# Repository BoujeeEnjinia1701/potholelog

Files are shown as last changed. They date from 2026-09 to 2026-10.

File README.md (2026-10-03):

# PotholeLog

     

**Area:** Smart Cities · **TRL:** 3 of 9 (proof of concept on paper) · **Value-engineering target:** about $75 USD · **Difficulty:** 2 of 5

A vehicle-mounted road roughness logger for buses, garbage trucks or bikes that records vibration with location to map potholes and rough roads as the fleet drives its routes.

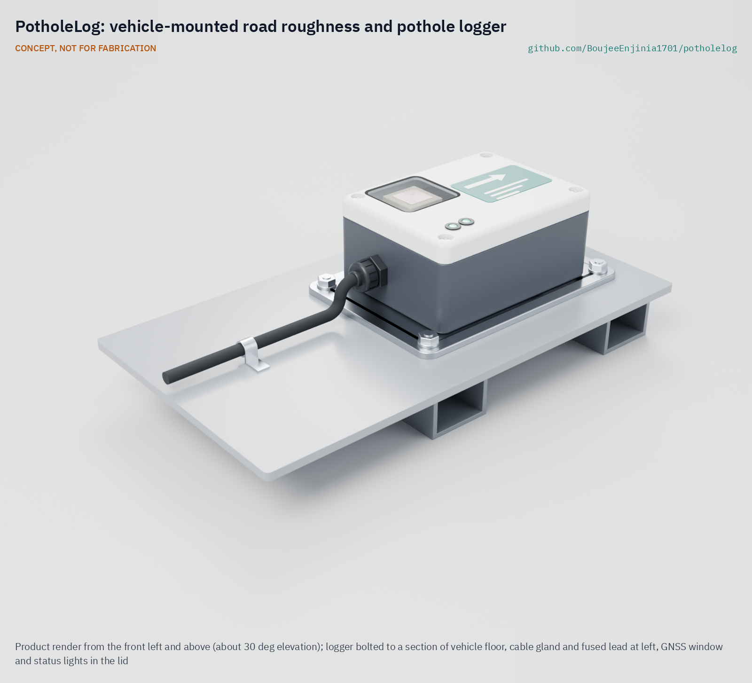
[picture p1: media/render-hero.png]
PotholeLog: vehicle-mounted road roughness and pothole logger, product render


[Exploded render](media/render-exploded.png) · [Detail render](media/render-detail.png) · [Interactive 3D model](media/viewer.html) · [Concept blueprint (PDF)](media/concept-blueprint.pdf) · [General arrangement (PDF)](cad/drawings/PHL-DWG-001.pdf) · [Calculations](docs/04-calcs/01-sizing.md) · [Prototype build plan](docs/05-build-plan.md) · [Design decisions](docs/06-design-decisions.md) · [Review note](docs/REVIEW.md)

## Concept rationale

Fleets already cover the road network every week, and a small sensor turns routine trips into a road survey. PotholeLog is a sealed box bolted to the floor of a bus or refuse truck above the rear axle. It logs vertical acceleration at 400 Hz with GNSS position, reports a roughness value for every 100 m of road and flags sharp impacts as possible potholes. Many passes by many vehicles are averaged, and each vehicle is calibrated on a few reference sections to give an estimate on the International Roughness Index (IRI) scale, following the method the World Bank set out for response-type roughness meters ([Technical Paper 46](https://documents1.worldbank.org/curated/en/851131468160775725/pdf/multi-page.pdf)).

It is open and garage-buildable because the agencies with the least survey money most need the data, and the parts are ordinary: an ESP32 board, an IMU breakout, a GNSS module, a vehicle DC-DC converter and a stock IP65 box, for about $77.50 in parts (indicative). Open firmware and an open data format let a city check how its road map was made and let others improve the detection method on the same raw data.

## Burning platform

Many road networks carry a large share of rough pavement. In the United States in 2023, about 25 % of the reported mileage of urban "other principal arterials" had an IRI above 170 in/mi (2.7 m/km), the level treated as poor (computed from [FHWA Highway Statistics, table HM-64](https://www.fhwa.dot.gov/policyinformation/statistics/2023/hm64.cfm)). In England, local authorities rated 17 % of their unclassified roads as needing maintenance to be considered in the year to March 2025 ([Department for Transport](https://www.gov.uk/government/statistics/road-conditions-in-england-to-march-2025)). Yet most local streets are surveyed rarely, so repairs follow complaints.

The stakes go beyond vehicle damage. Road crashes kill about 1.16 million people a year, 92 % of them in low- and middle-income countries, and more than half of those killed are pedestrians, cyclists and motorcyclists ([WHO](https://www.who.int/news-room/fact-sheets/detail/road-traffic-injuries)), the road users most exposed to potholes and broken surfaces. The same WHO fact sheet estimates that crashes cost most countries 3 % of gross domestic product.

## Where it could be used

### By industry

| Industry | Use |
| --- | --- |
| Municipal road maintenance | Weekly roughness and pothole map from the city's own fleet to plan patching and resurfacing |
| Public transit | Buses log the corridors they use most, and the agency can show where rough roads affect ride comfort and wear |
| Waste collection | Refuse trucks reach nearly every residential street on a weekly cycle, covering the roads surveys visit least |
| Road agencies and development programs | Low-cost condition data for network planning where survey vans are unaffordable |
| Fleet maintenance | Relate suspension and tyre wear to the roughness of each vehicle's routes |
| Universities and civic tech groups | Open raw data for research on detection methods and road equity |

### By country or region

| Country or region | Why it matters there |
| --- | --- |
| United States | About a quarter of urban principal arterial mileage rated above the poor IRI level in 2023 ([FHWA HM-64](https://www.fhwa.dot.gov/policyinformation/statistics/2023/hm64.cfm)); cities have large bus and refuse fleets to host loggers |
| England and the United Kingdom | 17 % of local unclassified roads needed maintenance to be considered in 2024/25 ([DfT](https://www.gov.uk/government/statistics/road-conditions-in-england-to-march-2025)); councils already publish condition data |
| Sub-Saharan Africa | Road traffic death rates are highest in the WHO African Region ([WHO](https://www.who.int/news-room/fact-sheets/detail/road-traffic-injuries)); minibus fleets cover dense networks where survey budgets are small |
| India | Road accidents attributed to potholes numbered 4,775 in 2019 and 3,564 in 2020, according to the road transport ministry's reply in the Lok Sabha ([PIB, 16 December 2021](https://pib.gov.in/PressReleasePage.aspx?PRID=1782178)); fleet data could locate defects before they cause crashes |
| Brazil | The 2025 CNT survey of 114,197 km of federal and main state highways rated the pavement fair, poor or very poor on 56.5 % of that length ([CNT, Pesquisa CNT de Rodovias 2025](https://repositorio.itl.org.br/jspui/bitstream/123456789/847/1/Pesquisa%20CNT%20de%20Rodovias%202025%20-%20S%C3%ADntese%20dos%20resultados%20-%20nacional,%20por%20regi%C3%A3o%20e%20por%20estados.pdf)); fleet loggers could extend condition data to city streets |
| Canada | About 13 % of public road length was in poor or very poor condition in 2020 ([Statistics Canada, Core Public Infrastructure Survey](https://www150.statcan.gc.ca/n1/daily-quotidien/220524/dq220524a-eng.htm)); municipal transit and refuse fleets could survey local roads weekly |

## What sparked the idea

The starting point was the International Road Roughness Experiment, held around Brasília, Brazil, in May and June 1982 by research teams from Brazil, the United Kingdom, France, the United States and Belgium. On 49 test sections, from asphalt to earth roads, it compared rod-and-level surveys and profilometers with seven response-type roughness systems, five of them roadmeters fitted to ordinary passenger cars, and the results became the basis of the International Roughness Index ([Sayers, Gillespie and Queiroz, World Bank Technical Paper 45, 1986](https://documents1.worldbank.org/curated/en/326081468740204115/pdf/multi-page.pdf)). The experiment showed that an everyday vehicle, calibrated on a few reference sections, can measure roughness on a common scale. PotholeLog applies that finding to the buses and refuse trucks that already drive every street, with an open, low-cost sensor in place of a mechanical roadmeter.

## Problem

Road surveys are expensive and infrequent, so repairs follow complaints rather than condition. Full problem statement: [docs/01-problem.md](docs/01-problem.md)

## Concept

A vehicle-mounted road roughness logger for buses, garbage trucks or bikes that records vibration with location to map potholes and rough roads as the fleet drives its routes. This build targets buses and refuse trucks on vehicle power, with summaries uploaded over depot Wi-Fi; a bicycle variant, which needs its own battery and mount, is a later step (decided by Amish, 2026-09-25).

The TRL 3 calculations ([PHL-CAL-001](docs/04-calcs/01-sizing.md)) give 0.54 W running, 112 kB of summaries a day, 133 to 160 days of raw data on a 32 GB card, 7 s of hold-up and an estimated $77.50 in parts, $2.50 over the $75 value-engineering target once the status lights, breather vent and nameplate adopted on 2026-10-02 are counted. They also found two limits, both settled by Amish's 2026-09-25 decisions ([PHL-DDR-002](docs/decisions/0002-recommendations-accepted.md)). A bus tyre bridges most of a 300 mm pothole, so small potholes are found reliably only at low speed; the defect-detection range is now 10 to 30 km/h, relying on repeat slow passes near stops and junctions. The converter is now rated 60 V, so it survives a load dump on a 24 V vehicle, with a thin 1.9 V margin over the TVS clamp. Detection accuracy and calibration remain unverified until field data exist.

Full design precis: [docs/02-concept.md](docs/02-concept.md) · Requirements: [docs/03-requirements.md](docs/03-requirements.md) · Decisions: [PHL-DDR-001](docs/decisions/0001-trl2-review-decisions.md), [PHL-DDR-002](docs/decisions/0002-recommendations-accepted.md), [PHL-DDR-003](docs/decisions/0003-design-for-construction.md) · Parametric model: [cad/src/model.py](cad/src/model.py)

## Key components

- 6-axis IMU (LSM6DSO class) on the enclosure floor, screwed through it into the mounting plate
- GNSS module with patch antenna and PPS output (u-blox M10 class)
- ESP32-S3 controller with Wi-Fi and microSD storage
- 60 V-rated vehicle DC-DC converter (9 to 36 V supplies) with fuse, TVS and reverse-polarity protection, plus a hold-up supercapacitor
- Stock IP65 enclosure, 120 x 90 x 55 mm, held by four hex standoffs to a 160 x 110 x 4 mm aluminum mounting plate, with the modules on an aluminum carrier plate inside

The working bill of materials is in [bom/bom.csv](bom/bom.csv).

## Building the prototype

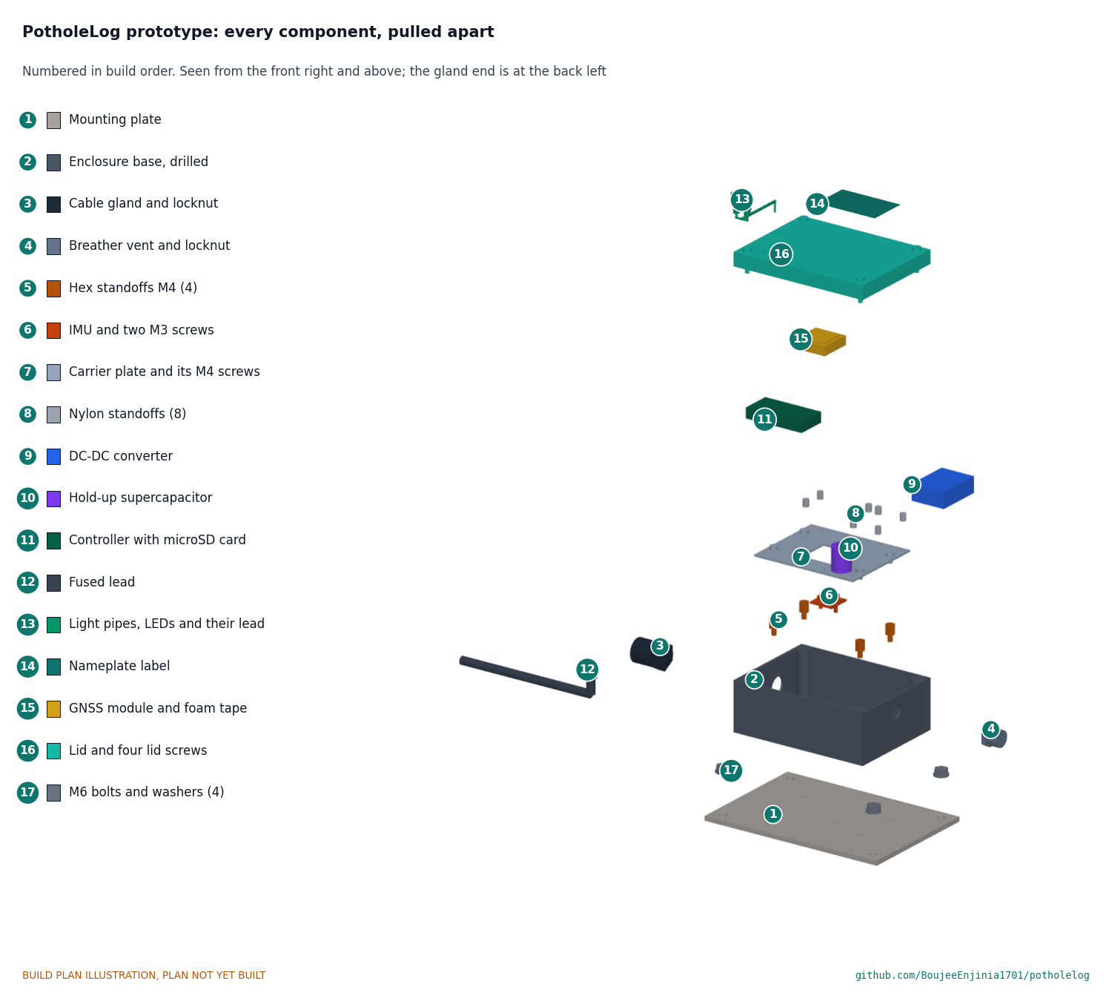
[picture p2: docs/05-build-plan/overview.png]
PotholeLog prototype: every component, pulled apart and numbered in build order


The [prototype build plan](docs/05-build-plan.md) (PHL-BLD-001) shows how to build the first logger from 14 components, each with a making sketch or a fitting picture, in nine assembly steps. Three parts are made in a small workshop from aluminium sheet and a bought plastic box; the rest are bought modules wired together at block level. Making the design buildable added a carrier plate for the modules and four hex standoffs that hold the box to the plate ([PHL-DDR-003](docs/decisions/0003-design-for-construction.md)). The plan stops at first checks on a bench board; fitting to a vehicle is outside it, and open choices are kept in the [design decisions register](docs/06-design-decisions.md).

## Safety

> Bolt the mounting plate through at existing fixing points so nothing can detach in a crash or hard stop, and never cut or weld structural members. Wire only to a fused, ignition-switched circuit with the battery isolated during installation, and route the lead away from moving parts and sharp edges. Do not fit a converter rated below 60 V to a 24 V vehicle. Never interact with the device while driving. Location data can reveal drivers' movements: publish only road-level results. This is a research prototype, not certified to automotive standards. See [docs/02-concept.md](docs/02-concept.md#safety).

## Repository layout

| Folder | Contents |
| --- | --- |
| `docs/` | Problem, concept, requirements, calculations and design decisions |
| `cad/src/` | build123d Python source, the source of truth for all geometry |
| `cad/step/`, `cad/stl/` | Exported models for FreeCAD, other CAD tools and printing |
| `cad/drawings/` | 2D sketches and dimensioned drawings |
| `bom/` | Bill of materials |
| `electronics/` | KiCad schematics and PCB layouts |
| `firmware/` | Microcontroller code |
| `media/` | Renders, perspectives and photos |
| `build-log/` | Dated prototyping notes |

## Documentation

Controlled documents follow the portfolio [documentation standard](.kit/STANDARDS.md). Each carries a document ID (PHL-PRC-001 for the precis), a version and a revision history. Branded PDFs are built with `python .kit/render.py` and attached to GitHub Releases when a document is tagged, for example `PHL-PRC-001/v1.0`.

## Credits

Designed by Amish Chadha. See [CONTRIBUTORS.md](CONTRIBUTORS.md) for roles. To cite this design, use [CITATION.cff](CITATION.cff) (GitHub shows it as "Cite this repository").

AI assistance (Claude) was used to accelerate concept renders, prototype documentation and first-pass sizing calculations. Design direction and all decisions are Amish Chadha's, recorded in this repository's decision records (`docs/decisions/`).

## Licenses

- **Hardware** (CAD, drawings, BOM, electronics): [CERN-OHL-S v2](LICENSE)
- **Software** (firmware, scripts, notebooks): [MIT](LICENSE-SOFTWARE)

A project of the [Design Molecule](https://designmolecule.com) lab.

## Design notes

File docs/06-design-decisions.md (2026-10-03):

---
doc_id: PHL-DEC-001
title: PotholeLog design decisions register
project: PotholeLog
doc_type: Design decisions register
version: "0.5"
status: Draft
date: '2026-10-03'
author: Amish Chadha
license: CERN-OHL-S-2.0
revisions:
  - version: "0.1"
    date: '2026-10-01'
    author: Amish Chadha
    change: Register opened with the build plan; budget treated as a value-engineering target
  - version: "0.2"
    date: '2026-10-02'
    author: Amish Chadha
    change: 'Amish approved the recommendations for all nine open decisions on 2026-10-02 (PHL-DDR-003 A1 to A3 accepted); moved to decisions made; value engineering notes the effect of the light pipes and vent'
  - version: "0.3"
    date: '2026-10-02'
    author: Amish Chadha
    change: "Design for construction (PHL-DDR-003, Tables 1 and 2) accepted by Amish on 2026-10-02; the 2026-10-01 row no longer says open for review"
  - version: "0.4"
    date: '2026-10-02'
    author: Amish Chadha
    change: "Value engineering: the light pipes and LEDs, breather vent and nameplate label are now BOM lines 14 to 16; estimate USD 77.50, USD 2.50 over the target"
  - version: "0.5"
    date: '2026-10-03'
    author: Amish Chadha
    change: "Amish accepted the cost overrun against the value-engineering target on 2026-10-03; row added to decisions made; value engineering section updated"
---

# PotholeLog design decisions register

Every design decision still to be made, and every decision made, in one place. Each decision is argued in full in its decision record under `docs/decisions/` or in the review note; this register is the index Amish works from. The build plan (`docs/05-build-plan.md`) describes the design as it stands and does not list open decisions.

## Open decisions

None. All open decisions were decided on 2026-10-02.

## To confirm when parts are bought

| # | What to confirm | Why it matters | Source |
| --- | --- | --- | --- |
| 1 | The box: 120 x 90 x 55 mm outside, 2.5 mm walls, a flat floor and four moulded corner pillars about 10 mm across | The standoff pattern, carrier size and clearances are set by them | PHL-DDR-003, P1, P7 |
| 2 | The converter's size (about 30 x 40 mm) and its four mounting holes; its 60 V input rating on the datasheet | The carrier's module holes are marked from it; safety stop S3 | PHL-DDR-003, P2; PHL-DDR-002, N1 |
| 3 | The ESP32-S3 board is no larger than about 52 x 26 mm and its microSD slot can be reached with the lid off | Many ESP32-S3 boards are longer; a longer board needs the layout rechecked | PHL-DDR-003, P3 |
| 4 | The IMU breakout: about 20 x 20 mm, two mounting holes, a side-entry plug, and the noise figure the calculations assume | The floor and plate IMU holes and the 3.4 mm clearance under the carrier | PHL-DDR-003, P5; PHL-CAL-001 |
| 5 | The GNSS module: no larger than 28 x 28 mm, a timing-pulse output, and a plug-in lead long enough to set the lid aside | The lid layout and the wiring | PHL-DDR-003, P6 |
| 6 | The hex standoffs' male thread is 6 mm or shorter | A longer thread would stick out under the plate | PHL-DDR-003, P1 |
| 7 | The M6 bolt length for the vehicle's floor or crossmember | It depends on the structure at the chosen fixing points | PHL-PRC-001 |

## Value engineering

Value-engineering target: USD 75 (a hypothetical control target, not a limit). Estimated cost of the constructable design: USD 77.50 (USD 2.50 over the target). Main cost drivers and savings worth trying:

Amish accepted this overrun on 2026-10-03: the estimated cost of USD 77.50 against the USD 75 target (USD 2.50 over), accepting the USD 2.50 overrun on R15. Amish: "Cost over target - i accept all the cost variations and overruns". It stays reported against the target as an accepted overrun, and the savings below remain worth trying.

- The largest lines are the GNSS module (USD 15), the controller (USD 10), the 60 V converter with its protection (USD 9) and the enclosure (USD 8); the plate, IMU and memory card are USD 6 each.
- Making the design constructable added the carrier plate (USD 2.00) and the box fixing kit (USD 1.50) and moved USD 0.50 of hardware out of line 11: from USD 71.00 to USD 74.00.
- Adopted on 2026-10-02 and now in the BOM: the two status light pipes with their LEDs and lead (line 14, USD 1.00), the breather vent (line 15, USD 2.00) and the nameplate label (line 16, USD 0.50). Together they take the estimate from USD 74.00 to USD 77.50, USD 2.50 over the target.
- Savings worth trying: cut the plate and carrier from offcuts; a 16 GB card still holds about 66 to 80 days of raw data against the 30 days needed (about USD 2 less), which with offcut plates would close most of the gap; GNSS modules of the same class vary widely in price; buying the standoffs, screws and lead parts in packs lowers the per-unit hardware cost.

## Decisions made

| Date | Decision | Decided by | Record |
| --- | --- | --- | --- |
| 2026-09-25 | TRL 2 review items D1 to D7: bicycles a later variant; depot Wi-Fi first; floor mount above the rear axle; ESP32-S3; LSM6DSO and M10 classes; 100 m segments in CSV and GeoJSON; publish road-level results only | Amish: "i accept all your recommendations, go with them across all repos." | PHL-DDR-001, PHL-DDR-002 |
| 2026-09-25 | N1: a 60 V-rated converter, with `budget_usd` raised from $70 to $75 | Amish, same instruction | PHL-DDR-002 |
| 2026-09-25 | N2: R5 defect-detection range 10 to 30 km/h with repeat slow passes; 300 mm reference defect kept | Amish, same instruction | PHL-DDR-002 |
| 2026-10-01 | Design for construction: hex standoffs, carrier plate, module layout, gland locknut, IMU screwed into the plate, GNSS on foam tape, modelled lid pillars | Made under Amish's 2026-09-30 instruction to make the design physically buildable ("fix the design assumptions to match and be physically feasible as you draw the illustrations"); the changes themselves were accepted on 2026-10-02 (below) | PHL-DDR-003 |
| 2026-10-02 | First pilot partner (first candidate to approach): a Dallas-Fort Worth area city with its own bus or refuse fleet, with TxDOT pavement management roughness data on state roads in that city as the reference IRI sections | Amish: "i approve your recommendations for all 555 open decisions." | PHL-DDR-001, O1; PHL-DDR-002 |
| 2026-10-02 | Clear lid window over the GNSS antenna shown in the renders only (option a); the build keeps the opaque lid | Amish: "i approve your recommendations for all 555 open decisions." | REVIEW 2026-09-26, item 1 |
| 2026-10-02 | Two sealed status light pipes in the lid, for power and logging, adopted (option a); the two lid holes are sealed like the others | Amish: "i approve your recommendations for all 555 open decisions." | REVIEW 2026-09-26, item 2 |
| 2026-10-02 | Pressure-equalizing breather vent on the front end wall adopted (option a) | Amish: "i approve your recommendations for all 555 open decisions." | REVIEW 2026-09-26, item 3 |
| 2026-10-02 | Printed nameplate label with a forward arrow adopted (option a) | Amish: "i approve your recommendations for all 555 open decisions." | REVIEW 2026-09-26, item 4 |
| 2026-10-02 | Segment files to CityTwin: CityTwin fetches the daily segment files from the operator's server (option a, matching CityTwin's outbound pull, CTW-DDR-001 D11); a date per segment may be published but never pass times, and only once at least two vehicles or several days are pooled | Amish: "i approve your recommendations for all 555 open decisions." | PHL-DDR-002, cross-repo actions |
| 2026-10-02 | Floor holes sealed with a ring of neutral-cure silicone round each hole for the prototype (option a), spray-tested at TRL 4 before a pilot; the foam gasket is the fallback if the spray test leaks | Amish: "i approve your recommendations for all 555 open decisions." | PHL-DDR-003, A1 |
| 2026-10-02 | GNSS module held by acrylic foam tape (option a), with adhesion checked after the TRL 4 heat soak; the printed clip is the fallback if the tape lets go | Amish: "i approve your recommendations for all 555 open decisions." | PHL-DDR-003, A2 |
| 2026-10-02 | Keep the 160 mm plate and bolt the logger down as a unit with a ring spanner for the prototype (option a); review after a TRL 4 trial fitting | Amish: "i approve your recommendations for all 555 open decisions." | PHL-DDR-003, A3; PHL-CAL-001 [I4] |
| 2026-10-02 | Design for construction accepted: the changes in Tables 1 and 2 (P1 to P7 and their knock-on changes), as made | Amish: "APPROVED: Design-for-construction changes in 10 repos (CityTwin, CoolShade, PalletPilot, Heliolite, PotholeLog, EarthPress, ReadyKit, CellCheck, CargoMule and ThermaCart)" | [PHL-DDR-003](decisions/0003-design-for-construction.md), Tables 1 and 2 |
| 2026-10-03 | Cost overrun accepted: the estimated cost of USD 77.50 against the USD 75 target (USD 2.50 over), accepting the USD 2.50 overrun on R15 | Amish: "Cost over target - i accept all the cost variations and overruns" | [REVIEW.md](REVIEW.md), session 2026-10-03 |

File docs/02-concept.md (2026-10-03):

---
doc_id: PHL-PRC-001
title: PotholeLog design precis
project: PotholeLog
doc_type: Design precis
version: "0.7"
status: Draft
date: '2026-10-02'
author: Amish Chadha
license: CERN-OHL-S-2.0
revisions:
- version: "0.1"
  date: '2026-09-25'
  author: Amish Chadha
  change: Initial scaffold
- version: "0.2"
  date: '2026-09-25'
  author: Amish Chadha
  change: Populate to TRL 2 (architecture, first-order numbers, safety, media)
- version: "0.3"
  date: '2026-09-25'
  author: Amish Chadha
  change: TRL 3 update (numbers checked against PHL-CAL-001, design choices adopted per PHL-DDR-001, parametric model and drawing PHL-DWG-001, detection and transient findings)
- version: "0.4"
  date: '2026-09-25'
  author: Amish Chadha
  change: Recommendations accepted by Amish (DDR-002)
- version: "0.5"
  date: '2026-10-01'
  author: Amish Chadha
  change: "Constructable design (PHL-DDR-003): carrier plate, box fixing, component table and key numbers updated"
- version: "0.6"
  date: '2026-10-02'
  author: Amish Chadha
  change: 'Decisions of 2026-10-02 (PHL-DEC-001): lid light pipes, nameplate and breather vent adopted; clear window renders only; CityTwin ingest and pooled dates; first pilot partner'
- version: "0.7"
  date: '2026-10-02'
  author: Amish Chadha
  change: 'Approved follow-ups carried out: light pipes and LEDs, breather vent and nameplate label as BOM lines 14 to 16; mass 0.44 kg and cost USD 77.50 (R15 not met); segment file pooling rule written into the server export'
---

# PotholeLog design precis

## Summary

PotholeLog is a sealed box, 120 x 90 x 55 mm on a 4 mm plate (59 mm overall), bolted to the floor of a bus or refuse truck above the rear axle. It records how the vehicle shakes and where it is, turns each 100 m of road into a roughness value and flags sharp impacts as possible potholes, then uploads a small daily file over depot Wi-Fi. Averaged over many passes and calibrated per vehicle, the data gives a city a weekly map of road condition on every street its fleet drives. The TRL 3 calculations (PHL-CAL-001) show that off-the-shelf modules meet the sampling, storage, hold-up and power needs for an estimated $77.50 in parts, $2.50 over the $75 value-engineering target since the status lights, breather vent and nameplate adopted on 2026-10-02 were added, and that the roughness signal is well above sensor noise. They also found two limits, both now addressed by Amish's 2026-09-25 decisions (PHL-DDR-002). A bus tyre bridges most of a 300 mm pothole, so the floor-mounted logger finds the R1 reference pothole only at low speed (up to about 20 km/h on a fair road, 50 km/h on a good one); small potholes are therefore sought on slow passes, 10 to 30 km/h, near stops and junctions. The converter is now rated 60 V so that it survives a load dump on a 24 V vehicle. Detection accuracy and calibration to IRI remain unverified until field data exist. On 2026-10-01 the design was made constructable (PHL-DDR-003): the modules now sit on a carrier plate held by the four hex standoffs that fix the box to the mounting plate, and the build is described component by component in the prototype build plan ([PHL-BLD-001](05-build-plan.md)).

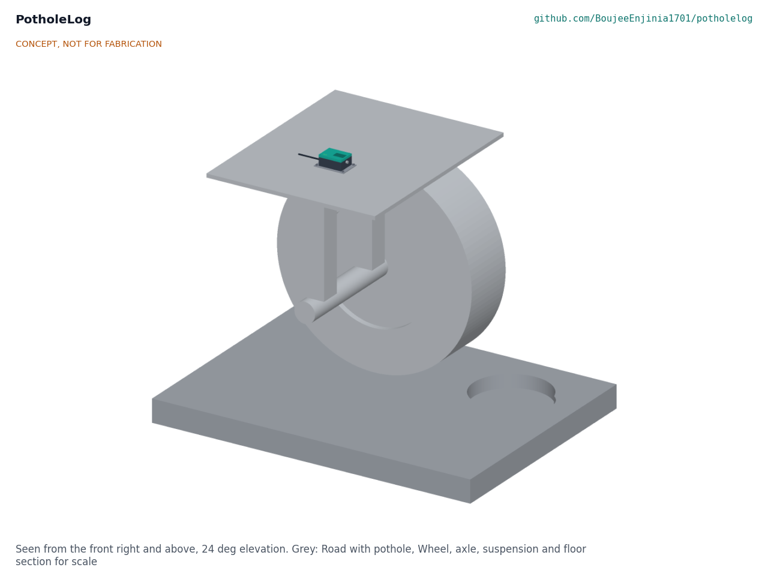
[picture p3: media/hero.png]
PotholeLog on a vehicle floor above the rear axle, with a wheel, suspension and a road with a pothole for scale


Figure 1. Concept massing model. The logger is the small dark box on the floor section; the grey scene is for scale.

## How it works

1. **Sense.** A 6-axis IMU rigidly fixed to the enclosure floor samples acceleration at 400 Hz. A GNSS module under the lid logs position and speed at 10 Hz.
2. **Log raw data.** Raw samples go to a microSD card as a rolling buffer, so any detection can be re-run later with a better algorithm.
3. **Summarize on board.** For every 100 m traveled, the controller computes a roughness value from the vertical acceleration (band-limited RMS from 0.5 to 20 Hz, tagged with its speed band for calibration), and records the segment's start and end, speed and the number of samples. Sharp vertical impacts above a threshold are stored as defect events, with most small potholes expected from slow passes at 10 to 30 km/h near stops and junctions (R5) with position, speed and peak size; the front and rear axle impacts of the same defect, about 0.4 to 0.7 s apart in town, are paired to confirm the event and place it at the rear axle.
4. **Upload.** When the vehicle is back within depot Wi-Fi with the ignition on, on arrival or at the next start, the controller joins the network and uploads the day's summaries (about 112 kB, about 8 s) to the fleet's server. The hold-up capacitor cannot power Wi-Fi long enough to upload after the ignition is switched off.
5. **Calibrate and aggregate.** On the server, each vehicle's raw roughness is converted to an IRI estimate using a calibration equation found on reference sections, in the way World Bank Technical Paper 46 describes for response-type systems ([Sayers et al., 1986](https://documents1.worldbank.org/curated/en/851131468160775725/pdf/multi-page.pdf)). Events from several passes and vehicles are clustered; a cluster seen on repeated passes becomes a reported defect, as in Pothole Patrol ([Eriksson et al., 2008](https://doi.org/10.1145/1378600.1378605)).
6. **Publish.** The city publishes a map of segment roughness and defect clusters as CSV and GeoJSON, for its own GIS and for CityTwin. Vehicle tracks and timestamps stay on the operator's server. CityTwin fetches the segment files from the operator's server; a date per segment is published only once at least two vehicles or several days are pooled, and pass times never are (decided 2026-10-02, PHL-DEC-001). The server export applies the pooling rule below.

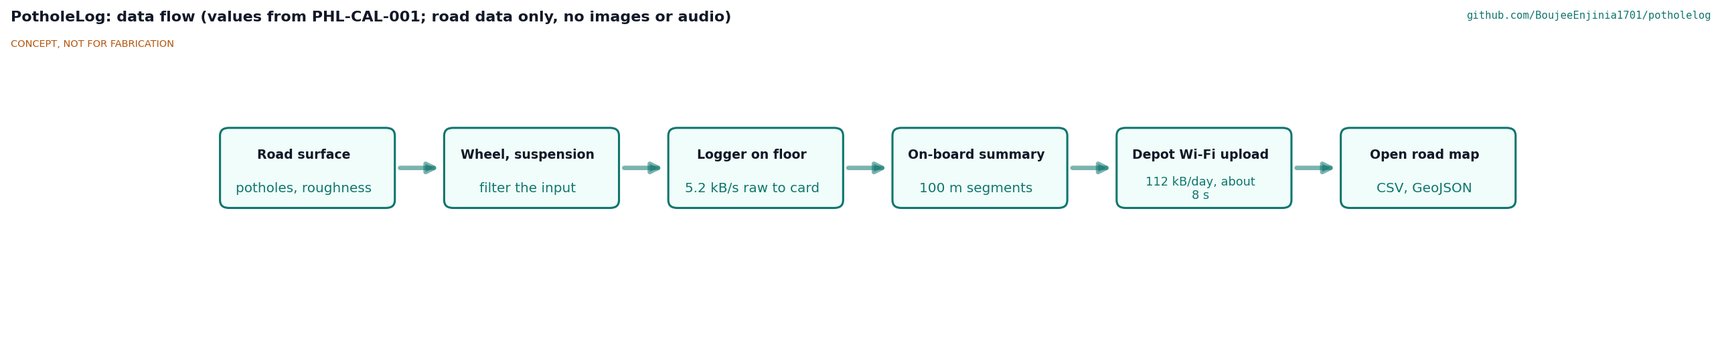
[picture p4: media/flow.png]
Data flow from road surface to open road map


Figure 2. Data flow. Values from PHL-CAL-001.

### Server export: segment files and the pooling rule

The operator's server writes one segment file a day in CSV and GeoJSON, following the CityTwin open data export, and CityTwin fetches it over HTTPS (decided 2026-10-02, PHL-DEC-001; CityTwin's outbound pull, CTW-DDR-001 D11). Each row is one 100 m segment: segment identifier and geometry, calibrated roughness (IRI estimate) with its uncertainty, number of passes, number of vehicles and number of days pooled, and defect clusters as point events. The pooling rule is applied in the export, not left to the reader:

1. A segment's row carries a date (day only, never a time) only when its value pools passes from at least two vehicles, or from at least three separate days. Otherwise the date field is left empty.
2. Pass times, vehicle identifiers, tracks and speeds are never exported; they stay on the operator's server.
3. Defect clusters carry the date of the newest day in the pool, under the same rule.

The three-day figure is this precis's reading of "several days" in the decision; it is to be matched with CityTwin's item 6 so both repos use the same rule and field names.

## Main components

Table 1. Main components. Numbers match the exploded view (Figure 3), `cad/src/model.py` and `bom/bom.csv`.

| # | Component | Proposed choice | Notes |
| --- | --- | --- | --- |
| 1 | Mounting plate | 160 x 110 x 4 mm aluminum, 4 x M6 on 140 x 90 mm; tapped for the box standoffs and the IMU screws | Bolts to existing crossmember, seat-rail or floor fixings; first mode about 168 Hz on corner bolts |
| 2 | Enclosure base | Stock IP65 ABS or polycarbonate box, 120 x 90 mm, with corner lid-screw pillars | Held to the plate by four M4 hex standoffs through its floor (PHL-DDR-003); a 12.2 mm hole in the front end wall for the breather vent (15) |
| 3 | Enclosure lid | Supplied with the box, with gasket; opaque; two 6.4 mm holes for the status light pipes (14) and the nameplate label (16) on top (decided 2026-10-02) | GNSS antenna under the lid; plastic lid keeps sky view through vehicle windows; the clear window shown in the renders is for the renders only |
| 4 | DC-DC converter and protection | 9 to 60 V in (60 V rated), 5 V 1 A out; TVS diode, reverse-polarity diode, input fuse | Covers normal 12 V and 24 V supplies and a 24 V suppressed load dump (58 V), clearing the TVS clamp by 1.9 V (PHL-DDR-002, N1) |
| 5 | Hold-up supercapacitor | 1 F, 5.5 V, rated to 70 °C or more | About 7 s at end of life to close files when power drops |
| 6 | Controller | ESP32-S3 board with Wi-Fi and microSD slot; module variant rated to 85 °C | Decided by Amish, 2026-09-25 (PHL-DDR-001, D4) |
| 7 | IMU | 6-axis, LSM6DSO class, ±16 g, 400 Hz or more | On the box floor, held by two M3 screws through the floor into the plate; gyroscope helps separate body roll and pitch from vertical motion |
| 8 | GNSS module | u-blox M10 class with patch antenna, 10 Hz, PPS output | Under the lid on a foam tape pad; PPS time-stamps the IMU samples |
| 9 | Cable gland and fused lead | M16 gland, 2 m lead, inline 2 A fuse | Wired to an ignition-switched fused circuit |
| 10 | microSD card | 32 GB high-endurance, -25 to 85 °C | 133 to 160 days of raw data |
| 11 | Fixings | 4 x M6 (8.8) with locking nuts and washers | Crash load is small; loosening needs a later test |
| 12 | Module carrier plate | 92 x 76 x 1.5 mm aluminum with a window over the IMU | Carries the converter, supercapacitor and controller (PHL-DDR-003) |
| 13 | Box fixing kit | 4 x M4 hex standoffs, screws, nylon standoffs, foam tape, sealant | Added for construction (PHL-DDR-003) |
| 14 | Status light pipes and LEDs | Two sealed panel-mount light pipes in the lid, a 5 mm LED in each, plug lead to the controller | Power and logging lights; adopted 2026-10-02 (PHL-DEC-001, decision 3) |
| 15 | Breather vent | M12 pressure-equalizing membrane vent, IP67, in the front end wall | Stops the box pumping moist air through the gasket as it heats and cools; adopted 2026-10-02 (decision 4) |
| 16 | Nameplate label | 54 x 34 mm laminated polyester label with a forward arrow | Shows which way the IMU's X axis must point; adopted 2026-10-02 |

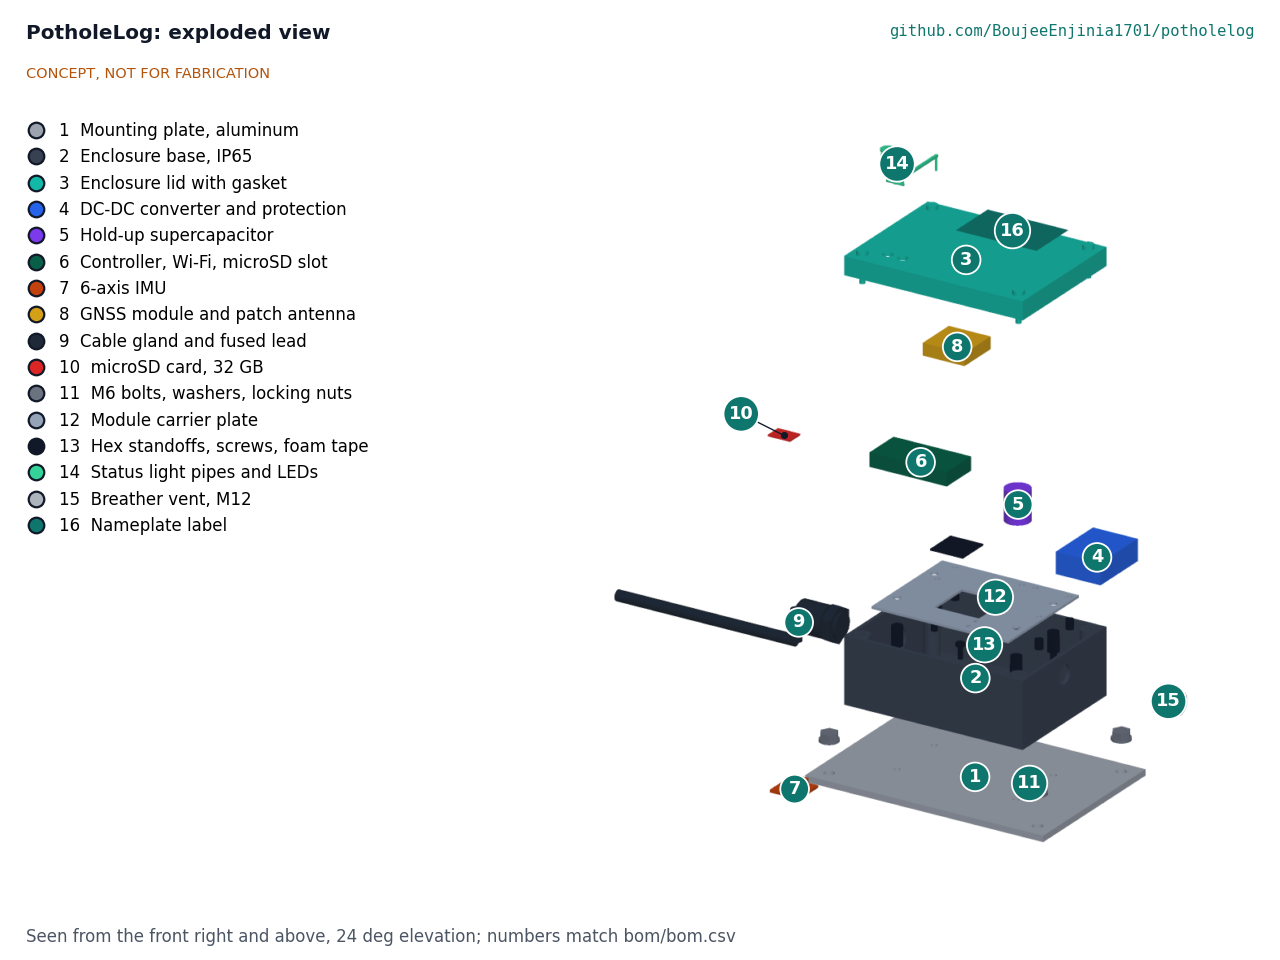
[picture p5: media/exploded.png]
Exploded view with BOM callouts


Figure 3. Exploded view with numbered callouts matching the BOM.

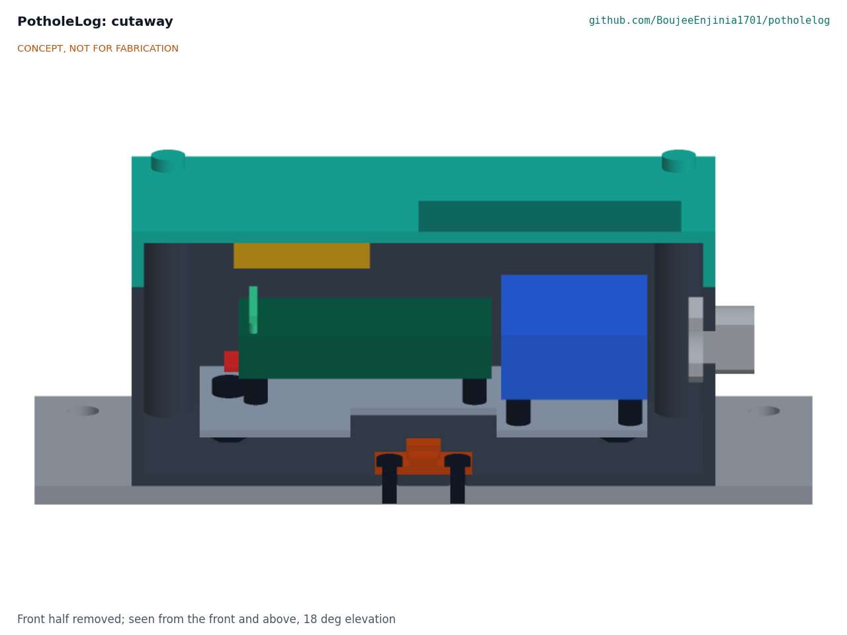
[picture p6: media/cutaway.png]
Section through the enclosure


Figure 4. Cutaway on the plane through the IMU. The IMU sits on the enclosure floor, the controller, supercapacitor and converter behind it, and the GNSS module under the lid.

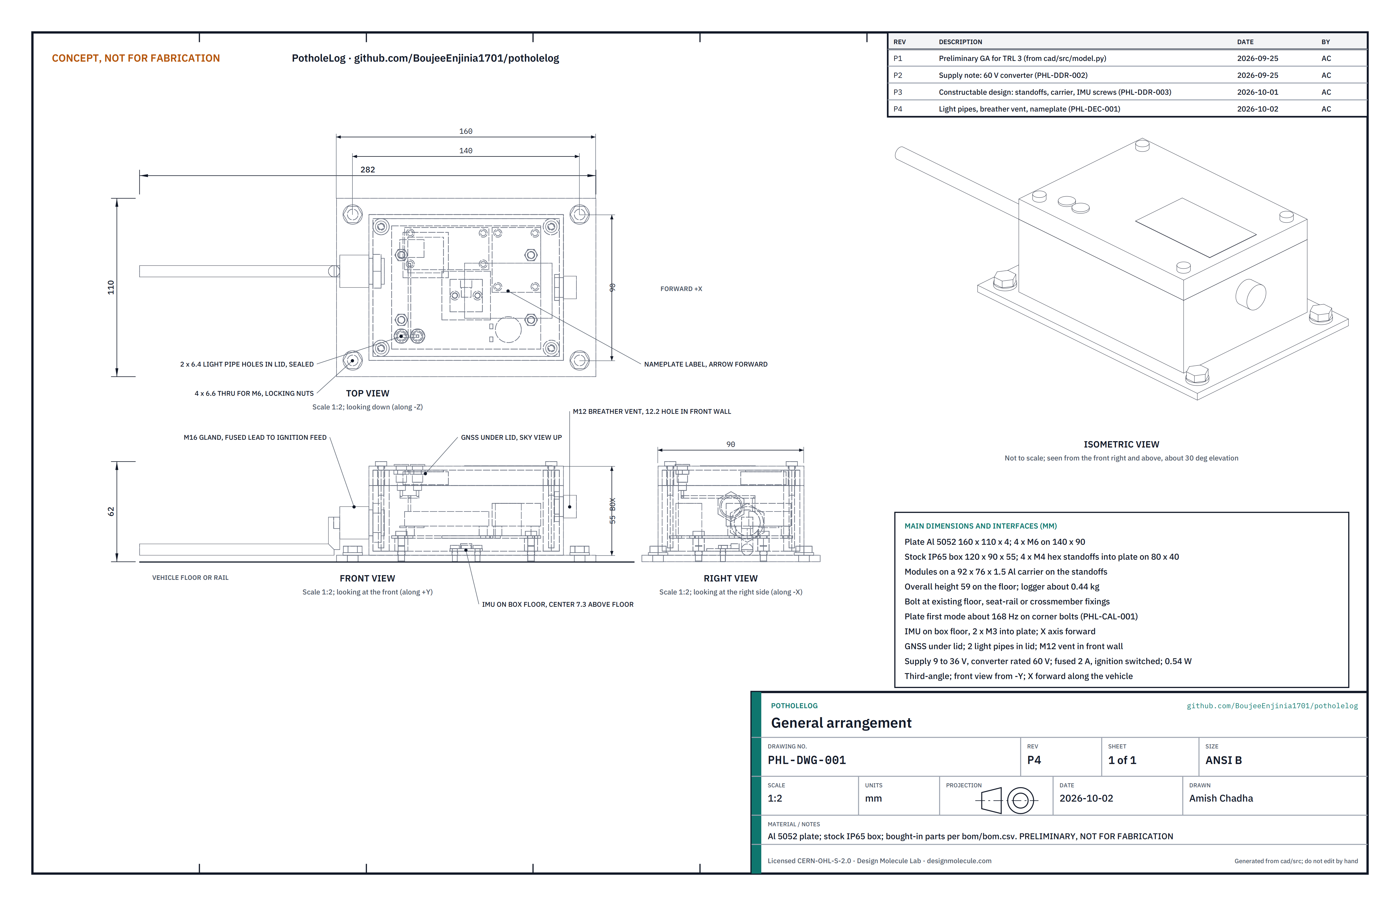
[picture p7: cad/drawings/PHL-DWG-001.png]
General arrangement drawing PHL-DWG-001


Figure 5. General arrangement PHL-DWG-001, Rev P3, generated from `cad/src/model.py` ([PDF](../cad/drawings/PHL-DWG-001.pdf)). Preliminary, not for fabrication.

## Key numbers

All values are from PHL-CAL-001 v0.3 (`docs/04-calcs/sizing.py`), which states the assumptions; they are calculations for review, not measurements.

Table 2. Key numbers.

| Quantity | Value | Basis | Requirement |
| --- | --- | --- | --- |
| Sample spacing on the road | 35 mm at 50 km/h, 56 mm at 80 km/h | 400 Hz | R6 |
| Samples across a 300 mm pothole | 9 at 50 km/h, 5 at 80 km/h | Length divided by spacing | R1 |
| Tyre drop into a 300 mm pothole | 22 mm, whatever its depth | 1.04 m tyre, rigid-circle envelope | R1 |
| Pothole detection margin | Above 1 up to about 20 km/h (IRI 4) and 50 km/h (IRI 2); in the 10 to 30 km/h band, 1.94 or more (IRI 2) and 0.97 at 30 km/h (IRI 4) | Quarter-car model against roughness crossing once per km | R1, R5 at risk |
| Roughness signal against noise | 12 times at 20 km/h on a smooth road | 0.5 to 20 Hz band | R5 |
| Synthetic calibration | r² 0.93 from one pass, 0.99 from five | 40 sections, IRI 1 to 8 m/km | R3 |
| Location, 95 % | 2.3 m suburban, 18.2 m dense urban (10 passes) | M10-class GNSS with PPS | R4 at risk |
| Raw data | 5.23 kB/s; 188 MB per 10 h day | 6 axes x 16 bit at 400 Hz, plus GNSS and time stamps | |
| Raw storage on a 32 GB card | 133 to 160 days | 10 to 12 h of driving a day | R7 met |
| Summaries per day | 112 kB, uploaded in about 8 s | 200 km, 48 B segments, 500 events at 32 B | R8 met |
| Running power | 0.54 W; 1.42 W for about 8 s while uploading | Loads 91 mA at 3.3 V, linear regulator, 85 % converter | R9 |
| Supply current | 45 mA at 12 V, 22 mA at 24 V | From running power | |
| Hold-up time | 10.0 s new, 7.0 s at end of life | 1 F from 4.7 V to 3.6 V | R10 met; 1 s needed |
| Inside temperature | About 72 °C at +70 °C ambient | 2.0 K self-heating | R11 at risk |
| Plate first mode | 168 Hz on corner bolts | 4 mm aluminum, 140 mm span | R12 met on paper |
| Installation | 30 min | Task estimate | R12 at the limit |
| Size | 120 x 90 x 55 mm box on a 160 x 110 x 4 mm plate, 59 mm overall | `cad/src/model.py` | |
| Mass | 0.44 kg; 0.58 kg with lead and fixings | Model volumes and module masses | |
| Converter input rating | 60 V against a 58 V suppressed load dump and a 58.1 V TVS clamp | ISO 16750-2 test B levels, to confirm | R9 at risk (TVS pulse energy) |
| Parts cost | $77.50 | `bom/bom.csv` | R15 not met: $2.50 over the $75 value-engineering target |

## Key design choices

The choices below were proposed at TRL 2 and decided by Amish on 2026-09-25 (go with recommendation; PHL-DDR-001 and PHL-DDR-002).

- **Sprung-mass mount on the floor, not on the axle.** The floor is clean, dry and easy to reach, and the GNSS can see the sky through the windows. The axle would give a stronger, less filtered signal but sees large shocks, water and stones. Calibration per vehicle corrects for the suspension. PHL-CAL-001 supports the choice: the axle would see about 9 g, 65 times the floor peak.
- **Depot Wi-Fi upload, not cellular.** It keeps parts cost near the value-engineering target and avoids data plans. Cellular (for example an LTE-M module) would give same-day data but adds about $20 to $30 per unit and a monthly fee; it stays an optional add-on, costed separately.
- **Raw data kept on the card.** Storage is cheap, and raw data lets the detection method improve without new hardware.
- **Summaries and events, not tracks, leave the vehicle's operator.** Only road-level results are published (R13).
- **Controller, IMU and GNSS.** ESP32-S3 (Wi-Fi, low cost, wide community), an LSM6DSO-class IMU and a u-blox M10-class GNSS. The alternatives considered were an RP2040 board with a separate Wi-Fi module and an nRF52 board with a phone or gateway for upload.
- **100 m segments and point events, in CSV and GeoJSON** following the CityTwin open data export.
- **60 V converter input.** A 60 V-rated converter replaces the 36 V part so that a 24 V suppressed load dump does not destroy it; about $2 more, with `budget_usd` raised from $70 to $75 (PHL-DDR-002, N1). A surge-stopper front end would be more robust and was not chosen.
- **Slow-pass defect detection.** The R5 defect-detection range is 10 to 30 km/h, with the 300 mm reference defect kept, because buses slow near stops and junctions and pass each spot many times (PHL-DDR-002, N2).
- **Bicycles later.** This build serves buses and refuse trucks; a bicycle variant with its own battery and mount is a later step, and the pitch is unchanged.
- **Built on existing lab work where it fits.** Outputs follow the CityTwin open data export so PotholeLog segments can appear on the CityTwin map; CityTwin is built on TwinKit. PotholeLog does not use FieldNode, because it runs from vehicle power rather than solar and uploads at the depot rather than over LoRaWAN.

## Safety

> **Safety:** PotholeLog is fitted to vehicles that carry passengers and operate in traffic.
>
> - **Secure mounting.** A loose box can become a projectile in a crash or hard stop. Bolt the plate through with M6 bolts and locking nuts at existing fixing points, never with adhesive or magnets alone. Do not cut, drill or weld chassis members or safety-critical structure; follow the fleet operator's and vehicle maker's rules for body fittings.
> - **Vehicle electrics.** Connect only to a fused, ignition-switched circuit through the inline fuse, with the battery isolated during installation. Route the lead away from moving parts, hot surfaces and sharp edges, and protect it where it passes through panels. A short on a 24 V vehicle supply can start a fire. The converter is now rated 60 V for a 24 V suppressed load dump (PHL-DDR-002), but the margin over the TVS clamp is only 1.9 V and the TVS pulse energy is untested; do not fit a converter rated below 60 V to a 24 V vehicle.
> - **Working on vehicles.** Install only with the vehicle parked, secured and switched off. Never work under a vehicle supported only by a jack.
> - **Driver distraction.** The logger has no controls or display and must not be handled while the vehicle is moving.
> - **Sharp edges.** Deburr the aluminum plate.
> - **Supercapacitor.** It stays charged for a short time after power is removed; do not short its terminals.
> - **Data.** Vehicle location data can reveal where drivers are and when. Keep tracks on the operator's server under the operator's data policy, inform drivers and unions before a pilot, and publish only road-level results.
>
> This is a research prototype. It is not certified to automotive electrical or EMC standards, and its outputs must not be used for contract acceptance or safety decisions without validation against a calibrated reference.

## Open questions

- Does the TVS survive a 24 V load dump pulse with the 60 V converter, or is a surge stopper needed (R9)? Needs a bench test (TRL 4, on hold).
- Are slow passes near stops and junctions frequent enough to meet R1 with the 10 to 30 km/h detection band (R5)? Needs field data.
- How far off is GNSS in the partner city's densest streets, and is map matching needed for R4?
- Which host fleet and city for a first pilot, and who provides reference IRI? Decided 2026-10-02 (PHL-DEC-001): the first candidate to approach is a Dallas-Fort Worth area city with its own bus or refuse fleet, with TxDOT pavement management roughness data on state roads in that city as the reference IRI sections.
- Should a bicycle variant be developed later, and with what battery and mount (R16)?

Concept media: [blueprint sheet](../media/concept-blueprint.pdf), [interactive 3D model](../media/viewer.html). Calculations: [PHL-CAL-001](04-calcs/01-sizing.md). Decisions: [PHL-DDR-001](decisions/0001-trl2-review-decisions.md).

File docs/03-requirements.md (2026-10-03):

---
doc_id: PHL-REQ-001
title: PotholeLog requirements
project: PotholeLog
doc_type: Requirements
version: "0.7"
status: Draft
date: '2026-10-02'
author: Amish Chadha
license: CERN-OHL-S-2.0
revisions:
- version: "0.1"
  date: '2026-09-25'
  author: Amish Chadha
  change: Initial scaffold
- version: "0.2"
  date: '2026-09-25'
  author: Amish Chadha
  change: First measurable requirements for TRL 2, with status against the concept
- version: "0.3"
  date: '2026-09-25'
  author: Amish Chadha
  change: TRL 3 status from PHL-CAL-001; R16 redefined per PHL-DDR-001 (D1); R8, R13 and R14 rest on adopted choices
- version: "0.4"
  date: '2026-09-25'
  author: Amish Chadha
  change: Recommendations accepted by Amish (DDR-002)
- version: "0.5"
  date: '2026-10-01'
  author: Amish Chadha
  change: "Constructable design (PHL-DDR-003): R12 plate mode and R15 cost updated; budget treated as a value-engineering target"
- version: "0.6"
  date: '2026-10-02'
  author: Amish Chadha
  change: 'Decisions of 2026-10-02 (PHL-DEC-001): R13 restated for published dates (pooled, never pass times); R14 CityTwin ingest path decided; R15 notes the cost of the adopted light pipes and vent. No status changed'
- version: "0.7"
  date: '2026-10-02'
  author: Amish Chadha
  change: 'Approved follow-ups carried out (PHL-CAL-001 v0.5): light pipes and LEDs, breather vent and nameplate label in the BOM; R15 moves from met on paper to not met (USD 77.50, USD 2.50 over the target)'
---

# PotholeLog requirements

These requirements are checked by calculation in PHL-CAL-001 v0.5. Targets are unchanged from v0.2 except R16, redefined for this build under PHL-DDR-001 (D1), and R5, whose defect-detection range is restated as 10 to 30 km/h under PHL-DDR-002 (N2). Both were decided by Amish on 2026-09-25 (go with recommendation). The status column gives the result on paper: "met on paper" means a calculation shows the target is met under the stated assumptions; "met by design" means the chosen parts and architecture meet it; "not verifiable at TRL 3" means only data from a vehicle can show it.

Table 1. Requirements.

| ID | Requirement | Target | Status at TRL 3 (PHL-CAL-001) | Verification (later) |
| --- | --- | --- | --- | --- |
| R1 | Detect potholes and severe defects in the wheel path | 80 % or more of defects at least 50 mm deep and 300 mm long found within 3 passes | At risk: a bus tyre drops only 22 mm into a 300 mm pothole; detectable up to about 20 km/h on IRI 4 roads and 50 km/h on IRI 2 roads | Detection model on logged data against a surveyed defect list |
| R2 | Keep false reports low | 10 % or fewer of reported defect clusters (2 or more passes) are not real defects | Not verifiable at TRL 3; Pothole Patrol reported over 90 % real after clustering | Field check of reported clusters |
| R3 | Report roughness per road segment | One roughness value per 100 m segment per pass, calibrated per vehicle to an IRI estimate; r² of 0.8 or better against reference IRI on calibration sections | Not verifiable at TRL 3; synthetic calibration gives r² 0.93 from one pass and 0.99 from five | Calibration runs following World Bank Technical Paper 46 |
| R4 | Locate defects | Defect cluster within 10 m of its true position (95 %) and on the correct street | At risk: 2.3 m suburban, 18.2 m in dense urban streets (10-pass cluster) | GNSS logs against surveyed points |
| R5 | Work across normal fleet speeds | Roughness valid from 20 to 80 km/h; defect detection from 10 to 30 km/h, relying on repeat slow passes near stops and junctions (restated under PHL-DDR-002, N2; was 10 to 80 km/h) | At risk: margin 1.94 or more on IRI 2 roads across the band, but 0.97 at 30 km/h on IRI 4 roads (1.17 allowing 10 background crossings per km); roughness signal is 12 times sensor noise at 20 km/h | Speed-banded calibration |
| R6 | Sample fast enough | 3-axis acceleration at 400 Hz or more, range ±8 g or more; GNSS position at 5 Hz or more | Met by design (400 Hz, ±16 g, 10 Hz GNSS with PPS; floor peak 0.14 g) | Datasheets and firmware configuration |
| R7 | Store data on the vehicle | 30 days or more of raw data and summaries without upload | Met on paper (133 to 160 days on 32 GB) | Storage calculation |
| R8 | Get data off the vehicle | Summaries uploaded automatically within 24 h, with no driver or staff action | Met on paper for vehicles in daily service (112 kB in about 8 s over depot Wi-Fi, with the ignition on) | Design review |
| R9 | Run from vehicle power | 9 to 36 V DC input (12 V and 24 V systems); reverse-polarity protected; transient levels of ISO 16750-2 as a target; under 1 W running; no draw with ignition off At risk: 60 V-rated converter (PHL-DDR-002, N1) clears the 58 V suppressed load dump and the 58.1 V TVS clamp by 1.9 V; TVS pulse energy during a load dump needs a bench test; running power 0.54 W met | Power budget; later bench test |
| R10 | Shut down cleanly | Files closed without corruption when power is cut at any time | Met on paper (7.0 s hold-up at end of life; 1 s needed) | Hold-up calculation |
| R11 | Survive the vehicle environment | Operating -20 to +70 °C; enclosure IP65; no loosening under vehicle vibration | At risk: about 72 °C inside at +70 °C needs 85 °C part grades; vibration not verifiable | Component ratings; later vibration test |
| R12 | Install quickly and safely | 30 min or less by a fleet mechanic; no cutting or welding of structural members; bracket first natural frequency above 150 Hz | At risk: 30 min task estimate at the limit; plate first mode 168 Hz met on paper (constructable design, PHL-DDR-003) | Design review |
| R13 | Protect privacy | No camera or microphone; published data limited to road-segment roughness and defect locations, with no vehicle tracks, timestamps or driver identity; no driver scoring. A date per segment may be published, never pass times, and only once at least two vehicles or several days are pooled (PHL-DEC-001, 2026-10-02) | Met by design (privacy rule D7) | Design review; data schema review |
| R14 | Open outputs | CSV and GeoJSON outputs that CityTwin and common GIS tools can read | Met by design (format D6); CityTwin fetches the segment files from the operator's server (PHL-DEC-001, 2026-10-02) | Sample export |
| R15 | Low cost and buildable | Parts cost against the $75 value-engineering target (a hypothetical control target, raised from $70 under PHL-DDR-002, N1); off-the-shelf modules; no custom PCB | Not met ($77.50, $2.50 over the target) | Priced BOM |
| R16 | Fit the fleet types in this build | Buses and refuse trucks; a bicycle variant is deferred to a later step (PHL-DDR-001, D1) | Met by design for buses and refuse trucks; bicycles are not served by this build | Design review |

## Requirements not met or at risk

- **R5 at risk.** The R1 reference pothole is largely bridged by a bus tyre, so its floor signal falls below ordinary road vibration at 30 km/h and above on fair roads (PHL-CAL-001, section C). Under PHL-DDR-002 (N2) the defect-detection range is restated as 10 to 30 km/h, with repeat slow passes near stops and junctions; the 300 mm reference defect is kept. The restated range is met on good roads and on fair roads up to about 29 km/h; at 30 km/h on an IRI 4 road the margin is 0.97. Longer potholes (600 mm) are detectable at all speeds.
- **R9 at risk.** Under PHL-DDR-002 (N1) the converter is now rated 60 V, which clears the 24 V suppressed load dump (58 V) and the TVS clamp (58.1 V), a margin of only 1.9 V. The TVS conducts during the load dump, and whether it survives the pulse energy can only be shown by a bench test (TRL 4, on hold).
- **R1 at risk.** Detection depends on passes at low speed; only field data can show whether 80 % within 3 passes is reached.
- **R4 at risk** in dense urban streets, where GNSS errors repeat between passes.
- **R11 and R12 at risk.** Part temperature grades, vibration loosening and the 30 min installation are all at their limits.
- **R2 and R3 not verifiable at TRL 3.** Both need field data and a calibration partner with reference IRI sections.
- **R15 not met.** Value-engineering target: USD 75. Estimated cost of the constructable design: USD 77.50 (USD 2.50 over the target), after the 60 V converter (PHL-DDR-002), the carrier plate and box fixing kit added for construction (PHL-DDR-003), and the status light pipes and LEDs, breather vent and nameplate label adopted by Amish on 2026-10-02 (PHL-DEC-001, BOM lines 14 to 16, USD 3.50 together). The savings in the design decisions register could close the gap. A cellular option would take it further over.
- **Bicycles.** The pitch still names bikes, but this build serves buses and refuse trucks only (R16 as redefined).

## Assumptions

- Host vehicles run about 200 km a day (estimate for an urban bus or refuse truck), return to a depot with Wi-Fi each night and spend at least about 10 s with the ignition on within its coverage.
- The logger is mounted on the sprung mass (floor or body structure), not the axle; the suspension filters the input, which calibration corrects.
- 100 m segments match common practice for network roughness reporting; defects are reported as point events.
- A partner agency can provide reference IRI on a few calibration sections, or allow a rod-and-level survey of them.

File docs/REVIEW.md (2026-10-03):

# Review note: PotholeLog

## Session 2026-09-25: /populate to a strong TRL 2

### What was done

- `docs/01-problem.md` (PHL-PRB-001 v0.2): problem with cited figures (FHWA, DfT, WHO), users and context, prior work (Pothole Patrol, World Bank response-type roughness meters, smartphone apps), constraints, out of scope, safety pointer; co-design checklist kept.
- `docs/03-requirements.md` (PHL-REQ-001 v0.2): 16 measurable requirements (R1 to R16) with targets, status against the concept, verification route and assumptions.
- `docs/02-concept.md` (PHL-PRC-001 v0.2): how it works, numbered components, first-order numbers with assumptions, design choices, safety section, open questions.
- `cad/src/concept_media.py`: massing model of the logger (plate, IP65 box and lid, converter, supercapacitor, controller, IMU, GNSS, cable gland and lead), each part with a BOM number. Because the logger is small, the hero uses a grey context scene (road with a pothole, wheel, axle, suspension and floor section) instead of the 1.75 m figure.
- `media/`: `hero.png`, `concept-blueprint.png`, `.pdf` and `.svg`, `model.glb` and `viewer.html`, `exploded.png` (callouts 1 to 9), `cutaway.png`, `flow.png` (data flow, estimates labeled). All images were inspected; temporary `media/_views*` folders were removed.
- `bom/bom.csv`: 11 lines with indicative prices, rows 1 to 9 matching the exploded view; `bom/bom-notes.md` updated.
- `README.md`: hero image and links line; concept rationale, burning platform, where it could be used (by industry and by region), what sparked the idea, and updated concept, components and safety sections.
- `docs/pdf/`: branded PDFs of the three controlled documents.
- `project.yaml`: unchanged. The pitch and problem still match the cited figures.

### Key results (estimates, to be checked at TRL 3)

| Quantity | Estimate | Requirement |
| --- | --- | --- |
| Sampling | 400 Hz acceleration (about 35 mm spacing at 50 km/h), 10 Hz GNSS | R6 met by design |
| Raw storage | about 190 MB a day; about 5 months on 32 GB | R7 met by design |
| Upload | about 0.1 MB of summaries a day over depot Wi-Fi | R8 met by design; no real-time data |
| Power | about 0.7 W, about 60 mA at 12 V | R9 met by design |
| Hold-up after power loss | about 9 s (1 F supercapacitor) | R10 met by design |
| Size and mass | 120 x 90 x 59 mm box on a 160 x 110 mm plate; about 0.4 kg | |
| Parts cost | about $69 against a $70 budget | R15 met, $1 margin |

Requirements not met or at risk:

- **R16 not met for bicycles.** The pitch names bikes, but this concept needs vehicle power and a rigid floor.
- **R1, R2 and R3 unverified.** Detection rate, false reports and correlation with IRI need field data and reference sections.
- **R4 at risk** in dense urban streets, where GNSS error can be large.
- **R5 partly met.** Segments driven below 20 km/h give no roughness value on that pass.
- **R9 transient immunity, R11 temperature and vibration, and R12 install time and plate stiffness are unverified.**
- **R15 margin is thin.** Any cellular option would exceed the $70 budget.

### Proposed, awaiting Amish

Update 2026-09-25: items 1 to 7 are now "Decided by Amish, 2026-09-25: go with recommendation" (PHL-DDR-001, PHL-DDR-002). Item 8 stays "Proposed, awaiting Amish".

1. **Bicycles in the pitch.** Options: (a) keep the pitch and treat a bicycle variant (own battery, handlebar or seat-post mount) as a later step; (b) drop bikes from the pitch; (c) design both now. Recommendation: (a). `project.yaml` is unchanged.
2. **Upload route.** Options: depot Wi-Fi (in budget, next-day data) or LTE-M cellular (about $20 to $30 more per unit plus a data plan, same-day data, over budget). Recommendation: depot Wi-Fi first, with cellular as an optional add-on costed separately. No budget change is proposed.
3. **Mount location.** Sprung-mass floor mount above the rear axle (recommended) or an axle mount (stronger signal, harsher environment).
4. **Controller.** ESP32-S3 (recommended), an RP2040 board with Wi-Fi, or an nRF52 board.
5. **IMU and GNSS classes.** LSM6DSO-class IMU and u-blox M10-class GNSS (recommended), to be confirmed against datasheets at TRL 3.
6. **Segment length and output format.** 100 m segments plus point events, in CSV and GeoJSON following the CityTwin open data export (recommended).
7. **Privacy rule.** Publish only road-segment roughness and defect clusters; keep vehicle tracks and timestamps on the operator's server; no driver scoring (recommended, and should be agreed with any fleet partner and its drivers).
8. **First pilot partner.** A city road department with a bus or refuse fleet that can provide reference IRI sections; the Helpful Engineering network could help find one.

### Safety concerns

- Mounting on passenger vehicles: a loose box is a projectile hazard; through-bolting at existing fixings only.
- Vehicle electrics: fused, ignition-switched supply; a short on a 24 V system can cause a fire. Transient immunity is unverified.
- Working under or around vehicles during installation.
- Driver distraction: no controls or display.
- Location data can reveal drivers' movements; this is the main non-physical risk and needs a data agreement with the operator.
- Outputs are not a certified survey and must not drive contract acceptance or safety decisions without validation.

### Problems and notes

- The kit's cutaway cutter is centered at Z = 0, so the logger is modeled at the origin and the context scene is shifted down to meet it. This does not affect the media.
- In the hero render the logger is small relative to the wheel and floor, which is the true scale; the exploded view and cutaway show it clearly.
- WebSearch was unavailable. Sources were verified by fetching pages directly. Figures that could not be verified (for example AAA pothole damage costs, the UK ALARM survey and India pothole death counts) were left out.
- The legacy `cad/src/model.py` placeholder is untouched (TRL 3 work).

### Recommended next step

Review this note and the media, then decide items 1 and 2. If approved, run `/advance-trl3` to check the sampling, power, hold-up and plate stiffness by calculation, define the roughness metric and calibration method, and produce the parametric model and drawing sheet.

## Session 2026-09-25: TRL 3

Amish asked on 2026-09-25 for this batch of repos to be taken through the usual process with the instruction "you know the drill, nothing gets past TRL 3". He has not reviewed this repo's TRL 2 items one by one, so each item with a recommendation is adopted as recommended for TRL 3 under that instruction and remains open for his review. This session ran `/advance-trl3` and stopped at TRL 3.

### What was done

- `docs/decisions/0001-trl2-review-decisions.md` (PHL-DDR-001 v0.1, status proposed): items D1 to D7 adopted as recommended for TRL 3 under Amish's 2026-09-25 instruction, open for his review; O1 (first pilot partner and city) left as "Proposed, awaiting Amish".
- `docs/04-calcs/01-sizing.md` (PHL-CAL-001 v0.1) and `docs/04-calcs/sizing.py`: a quarter-car model of a bus rear corner on ISO 8608 road profiles with golden-car IRI; roughness signal, noise, speed and load effects and a synthetic calibration; pothole detection with tyre enveloping; location error; storage, upload, power, transients and hold-up; self-heating, mass and fixings; plate stiffness and installation time; cost. The script imports the model's parameters and part volumes and reads the BOM and `project.yaml`; every number in the note is printed by it (runs in about 10 s).
- `cad/src/model.py`: parametric build123d model (plate with hole patterns, stock enclosure base and lid, converter, supercapacitor, controller with microSD card, IMU on the box floor, GNSS under the lid, gland and lead stub, M6 fixings). Exports `cad/step/` and `cad/stl/` for `potholelog-assembly`, `mounting-plate` and `enclosure`.
- `cad/src/sheets.py` and `cad/drawings/PHL-DWG-001.svg`, `.pdf`, `.png`: general arrangement at Rev P1, 1:2, marked "CONCEPT, NOT FOR FABRICATION" and "PRELIMINARY, NOT FOR FABRICATION". PHL-DWG-001 was free because the concept blueprint is PHL-DWG-010.
- `bom/bom.csv` (11 lines, all priced with a supplier or supplier type, $69.00) and `bom/bom-notes.md`.
- `cad/src/concept_media.py` now builds from the model; all of `media/` was re-rendered and every image checked. The exploded view now has callouts 1 to 11 matching the BOM. Temporary `media/_views*` folders were removed.
- PHL-PRB-001, PHL-PRC-001 and PHL-REQ-001 revised to v0.3; `README.md` (TRL 3, key numbers, links) and `project.yaml` (`trl: 3`, `trl_target: 3`, evidence list) updated. PDFs rebuilt in `docs/pdf/`.

Design details specified by the calculations, within the adopted choices: GNSS with a PPS output to time-stamp IMU samples; uploads run with the ignition on (the hold-up cannot power Wi-Fi); shutdown starts only after about 2 s of low input so cranking dips are ridden through; front and rear axle impacts are paired; part grades of 85 °C for the controller module and card and 70 °C or more for the supercapacitor; the plate is bolted down before the box is fitted, because socket clearance is about 2 mm. The TRL 2 power estimate falls from 0.7 W to 0.54 W.

### Requirement status (PHL-CAL-001, Table 5)

2 not met, 4 at risk, 2 not verifiable at TRL 3, 4 met on paper, 4 met by design.

| ID | Status | Key number |
| --- | --- | --- |
| R5 Speed range | **Not met** | Reference pothole (50 x 300 mm) margin 0.97 at 30 km/h, 0.54 at 50 km/h and 0.30 at 80 km/h on an IRI 4 road; a bus tyre drops only 22 mm into it |
| R9 Vehicle power | **Not met** (transients) | 24 V suppressed load dump 58 V against a 36 V converter; running power 0.54 W is met |
| R1 Detection | At risk | Margin above 1 up to about 20 km/h (IRI 4) and 50 km/h (IRI 2); 93 % of passes hit the pothole |
| R4 Location | At risk | 95 % radius 2.3 m suburban, 18.2 m dense urban after 10 passes |
| R11 Environment | At risk | About 72 °C inside at +70 °C; part grades and vibration loosening |
| R12 Installation | At risk | 30 min task estimate at the limit; plate mode 186 Hz met |
| R2, R3 | Not verifiable at TRL 3 | Synthetic calibration r² 0.93 from one pass, 0.99 from five |
| R7, R8, R10, R15 | Met on paper | 133 to 160 days on 32 GB; 112 kB uploaded in about 8 s; 7.0 s hold-up; $69.00 of $70 |
| R6, R13, R14, R16 | Met by design | 400 Hz, ±16 g, peak 0.14 g; privacy rule; CSV and GeoJSON; buses and refuse trucks |

Key numbers: 5.23 kB/s raw; 0.37 kg (0.51 kg with lead and fixings); load changes the roughness signal by ±7 % with air suspension and up to 22 % with steel springs.

### Decisions recorded (PHL-DDR-001)

Decided by Amish, 2026-09-25: go with recommendation (previously adopted as recommended for TRL 3, open for his review): D1 keep the pitch and treat bicycles as a later variant (R16 redefined to buses and refuse trucks for this build); D2 depot Wi-Fi first, cellular as a separately costed add-on; D3 floor mount above the rear axle; D4 ESP32-S3; D5 LSM6DSO-class IMU and M10-class GNSS; D6 100 m segments and point events in CSV and GeoJSON after the CityTwin export; D7 publish road-level results only, no driver scoring. No new budget and no pitch or problem rewording were recommended, so `budget_usd` stays at $70 and the pitch still names bikes.

### Still awaiting Amish

Update 2026-09-25: items 2 and 3 are now "Decided by Amish, 2026-09-25: go with recommendation" (PHL-DDR-002, N1 and N2). Item 1 stays "Proposed, awaiting Amish".

1. **O1, first pilot partner and city.** No partner, city or preference was named at TRL 2; none is chosen here.
2. **New, converter input for 24 V vehicles (R9).** Options: (a) a 60 V-rated converter, about $2 more, $71.00 in parts, $1 over budget; (b) keep the 36 V part and limit the build to 12 V vehicles, which excludes most buses; (c) add a surge-stopper front end, more robust and more costly. Recommendation: (a), with `budget_usd` raised to about $75 to restore a small margin. Not applied: the BOM still carries the 36 V part and `budget_usd` is unchanged at $70.
3. **New, defect-detection target (R1, R5).** Options: (a) keep the targets and accept R5 as not met; (b) limit the R5 defect-detection range to 10 to 30 km/h and rely on repeat slow passes near stops and junctions; (c) change the R1 reference defect to one at least 600 mm long, which is detectable at all speeds (margin 1.67 at 80 km/h on IRI 4). Recommendation: (b), keeping the 300 mm reference, because it matches how buses drive in town. Not applied.

Suggestions only, not in the repo: map matching to street centerlines for R4 in dense streets; a load flag for steel-sprung refuse trucks; testing the gyroscope's roll rate as a second detection channel for one-sided potholes.

### Cross-repo consistency

- PotholeLog uses no FieldNode, CellGuard, MotionCore, ThermaCart or CalRig component. It relates to TwinKit only through CityTwin's open data export (D6).
- CityTwin's review (session 2026-09-25, /populate) lists the PotholeLog upload path as undefined (its R1 at risk) and recommends one-way publishing, with the gateway accepting no inbound connections. PotholeLog uploads to the fleet operator's server, so CityTwin would need to fetch the operator's daily segment files, or the operator would pass them on by another route. This is not a conflict, but the path must be agreed between the two repos; no change was made to CityTwin.
- CityTwin plans to publish PotholeLog data "per road segment and per day". PotholeLog's R13 excludes timestamps from published data. A publication date for a daily aggregate is compatible with R13 as long as pass times are not published; to confirm when the interface is agreed.

### Safety concerns

- The 36 V converter in the BOM is not rated for a 24 V load dump. Until item 2 is decided it must not be fitted to a 24 V vehicle; the precis and README say so.
- A loose box is a projectile: crash loads are small (18 N per M6 bolt at 20 g), but loosening under years of vibration is untested. Locking nuts and bolting to structure, not thin floor panels, stay mandatory.
- False reassurance: small potholes can be missed at speed (R5), so a clean map is not proof of a sound road. Outputs remain uncertified and must not drive contract acceptance or safety decisions.
- Location data can reveal drivers' movements; the privacy rule (D7) still needs agreement with the fleet partner and its drivers.
- Working under and around vehicles and on vehicle electrics during installation, as at TRL 2.

### Gaps and notes

- The quarter-car model is linear, uses a rigid tyre circle and ignores pitch, roll and body flexing; ISO 8608 roads are Gaussian and lack joints and covers. The ISO 16750-2 levels, the IMU noise figure and the GNSS accuracy classes are stated as assumptions to confirm from the documents; they were not fetched this session.
- Citations: no unchecked citations remain in the docs. The figures left out at TRL 2 (AAA damage costs, the UK ALARM survey, India pothole deaths) were not re-attempted; WebSearch was unavailable.
- The kit's cutaway cuts at the mean Y of the parts, which removed the IMU; `cad/src/concept_media.py` swaps in a cut on the IMU's plane (a project-side wrapper; the kit is unchanged). The logger stays at the origin and the grey context scene is shifted, as at TRL 2.
- In the hero render the logger is small beside the wheel and floor, which is its true scale.
- Existing material beyond TRL 3: `build-log/README.md` (scaffold only) is present, untouched and not extended. No test, build, firmware or PCB material exists.

### Recommended next step

TRL 4 is on hold by Amish's instruction; this repo stops at TRL 3. Amish's review is needed on items 1 to 3 above and on D1 to D7. For the record only, TRL 4 would need: a bench build of the logger; a lab test report (TST, `environment: lab`) covering IMU noise and timing against PPS, power and hold-up with power cuts, and ISO 16750-2 transients on the chosen converter; and build log entries. Drive data over surveyed defects and reference IRI sections would follow at TRL 5. None of this has been started.

## Session 2026-09-25: recommendations accepted

Amish wrote on 2026-09-25, in chat: "i accept all your recommendations, go with them across all repos." This session applied that decision at TRL 3 and recorded it in `docs/decisions/0002-recommendations-accepted.md` (PHL-DDR-002 v0.1).

### Decisions applied

Nine items are now "Decided by Amish, 2026-09-25: go with recommendation".

| # | Decision | Before | After |
| --- | --- | --- | --- |
| D1 to D7 | Bicycles later, depot Wi-Fi, floor mount, ESP32-S3, LSM6DSO and M10 classes, 100 m segments in CSV and GeoJSON, privacy rule | Adopted as recommended for TRL 3, open for review | Decided; wording updated in PHL-DDR-001 v0.2, PHL-PRB-001, PHL-PRC-001, `bom/bom.csv`, `bom/bom-notes.md` and `README.md` |
| N1 | 60 V-rated converter; budget raised | 9 to 36 V converter, $7.00; parts $69.00; `budget_usd` $70; R9 not met | 9 to 60 V converter, $9.00; parts $71.00; `budget_usd` $75 (margin $4.00); R9 at risk (1.9 V over the 58.1 V TVS clamp; TVS pulse energy untested) |
| N2 | R5 defect-detection range restated, 300 mm reference kept | 10 to 80 km/h; not met (margin 0.30 at 80 km/h on IRI 4) | 10 to 30 km/h with repeat slow passes; at risk (lowest margin 1.94 on IRI 2, 0.97 at 30 km/h on IRI 4, 1.17 allowing 10 crossings per km) |

What changed in the repo:

- `project.yaml`: `budget_usd` 70 to 75; DDR-002 added to the TRL evidence. Pitch and problem unchanged (no rewording was recommended). `trl: 3` and `trl_target: 3` unchanged.
- `bom/bom.csv` item 4 and `bom/bom-notes.md`: 60 V converter, $71.00 total.
- `docs/03-requirements.md` (PHL-REQ-001 v0.4): R5 target and status, R9 status, R15 target ($75) and status.
- `docs/04-calcs/sizing.py` and `01-sizing.md` (PHL-CAL-001 v0.2): converter rating 60 V in F4 and F5, cost in J1 and J2, new line K2 for the 10 to 30 km/h band; Table 5 and the summary updated. The script was re-run and the note matches its output.
- `docs/02-concept.md` (PHL-PRC-001 v0.4), `docs/01-problem.md` (PHL-PRB-001 v0.4): decisions, converter, detection band, budget and safety text.
- `cad/src/model.py`: converter comment only (same 40 x 30 x 14 mm envelope); STEP and STL re-exported.
- `cad/drawings/PHL-DWG-001`: supply note now states the 60 V converter; Rev P1 to P2.
- `cad/src/concept_media.py`: blueprint key figures ($71 of $75, 60 V-rated input); all media re-rendered and inspected; `media/_views*` removed.
- `README.md`: budget, concept numbers, components, safety, a new "What sparked the idea" (the 1982 International Road Roughness Experiment in Brasília, World Bank Technical Paper 45), and removal of the earlier text about how the idea was assembled.
- All PDFs in `docs/pdf/` rebuilt; generated files regenerated so that none shows the old personal domain.

### Requirement status (PHL-CAL-001 v0.2)

0 not met, 6 at risk, 2 not verifiable at TRL 3, 4 met on paper, 4 met by design (before: 2 not met, 4 at risk).

| ID | Status | Key number |
| --- | --- | --- |
| R5 Speed range | At risk | Defect band 10 to 30 km/h: margin 0.97 at 30 km/h on IRI 4 |
| R9 Vehicle power | At risk | 60 V converter against 58 V load dump and 58.1 V TVS clamp; TVS energy untested |
| R1 Detection | At risk | Margin above 1 up to about 20 km/h (IRI 4) and 50 km/h (IRI 2) |
| R4 Location | At risk | 18.2 m in dense urban streets (10 passes) |
| R11 Environment | At risk | About 72 °C inside at +70 °C |
| R12 Installation | At risk | 30 min at the limit |
| R2, R3 | Not verifiable at TRL 3 | Synthetic r² 0.93 (one pass), 0.99 (five) |
| R7, R8, R10, R15 | Met on paper | 133 to 160 days; 112 kB in 8 s; 7.0 s hold-up; $71.00 of $75 |
| R6, R13, R14, R16 | Met by design | 400 Hz, ±16 g; privacy rule; CSV and GeoJSON; buses and refuse trucks |

### Still awaiting Amish

1. **O1, first pilot partner and city, and who provides reference IRI.** No recommendation was made, so no choice is made here.

Suggestions only, unchanged and not decisions: map matching for R4, a load flag for steel-sprung refuse trucks, and the gyroscope roll rate as a second detection channel.

### Cross-repo actions

- **CityTwin:** agree the ingest path for PotholeLog's daily segment files (CityTwin fetches from the operator's server, or the operator passes them on), and confirm that a daily publication date is compatible with PotholeLog R13. Not edited from this repo.

### Safety

- The 60 V converter clears the 24 V load dump by only 1.9 V over the TVS clamp, and the TVS pulse energy is untested; converters rated below 60 V must not be fitted to 24 V vehicles. The precis and README say so.
- A clean map is still not proof of a sound road: small potholes are sought only on slow passes.
- Other concerns are as in the TRL 3 session.

### TRL 4

TRL 4 remains on hold by Amish's instruction. Decided but on hold because they are TRL 4 work: a bench test of the converter and TVS against ISO 16750-2 load dump pulses (N1), and field data on slow-pass detection rates (N2). No build, test, firmware, PCB or purchasing work was started.

## Session 2026-09-26: sources strengthened

README "By country or region" rows without a citation were replaced or rewritten so each states only what a verified primary source supports. All kept links (FHWA HM-64, DfT, WHO, World Bank Technical Papers 45 and 46) were re-fetched and still support their claims.

| Row | Old source | New source |
| --- | --- | --- |
| India and South Asia, now India | None (uncited claims on two-wheelers and monsoon damage) | Press Information Bureau, Lok Sabha reply of 16 December 2021: pothole-related accidents 4,775 (2019) and 3,564 (2020) |
| Latin America, now Brazil | None | Confederação Nacional do Transporte, Pesquisa CNT de Rodovias 2025: pavement fair, poor or very poor on 56.5 % of 114,197 km |
| Canada and northern Europe, now Canada | None (uncited freeze-thaw claim) | Statistics Canada, Core Public Infrastructure Survey (The Daily, 24 May 2022): 13 % of roads poor or very poor in 2020 |

- What sparked the idea: the World Bank Technical Paper 45 source was kept (primary); "England" corrected to "the United Kingdom" to match the paper's list of participating countries.
- India pothole death counts were again not used; only the accident counts in the PIB release could be verified.
- No controlled document changed; `docs/01-problem.md` did not cite a weak source.

## Session 2026-09-26: product appearance model and photoreal renders

Amish chose this repo for the first batch of product renders on 2026-09-26. This session added `cad/src/product_model.py`, an appearance model for photoreal renders, and pointed the README hero at `media/render-hero.png` with a link to `media/render-exploded.png` (both produced later by the render pipeline).

What `product_model.py` adds, reusing `PARAMS`, `derived()` and `build_parts()` from `cad/src/model.py` with every main dimension and interface unchanged (plate, hole patterns, 120 x 90 x 55 mm box, module positions, gland position and lead path):

- Mounting plate with rounded corners and edge rounds; hex M6 bolt heads and washers (item 11).
- Enclosure base and lid with corner and edge fillets, a lid-to-base parting line, lid gasket, corner screw pillars and stainless lid screws, as on a stock IP65 box.
- M16 cable gland with hex body, locknut and knurled dome cap; the fused lead swept from the gland down to the floor, with a P-clip.
- Internals with credible detail: converter board with inductor, capacitors, TVS and terminal block; sleeved supercapacitor; controller PCB with ESP32-S3 module shield, USB-C, headers and microSD slot; IMU breakout with spacers and screws; GNSS PCB with ceramic patch antenna.
- Context: a compact section of painted steel vehicle floor with two crossmembers under the fixings.
- `TITLE` and three `RENDER_VIEWS`: hero (front left, with the floor), exploded (front right) and detail (front right, without the floor).

Where the appearance model differs from `model.py` (none of these change a main dimension or interface):

1. **Clear window in the lid over the GNSS patch antenna.** The BOM lid is opaque. Proposed, awaiting Amish. Recommendation: keep it for the renders only, or choose a stock box with a clear lid if Amish wants a visible antenna; GNSS reception is fine through either.
2. **Two status light pipes (power and logging) in the lid.** Not in the BOM or the firmware sketch. Proposed, awaiting Amish. Recommendation: adopt; a driver can see at a glance that the logger is running, at a cost of well under $1.
3. **Breather vent on the +X end wall.** Not in the BOM. Proposed, awaiting Amish. Recommendation: adopt a pressure-equalizing vent (about $2 to $3) to limit condensation in a sealed box that heats and cools daily; this would use about half of the $4 margin left in the $75 budget, so Amish decides.
4. **Teal nameplate with a forward arrow.** Not in the BOM. Proposed, awaiting Amish. Recommendation: adopt as a printed label; the arrow tells the installer which way the IMU axes face.
5. **Lead P-clip and floor and crossmember context.** Context only; the clip counts under item 11 hardware. No decision needed.

This is appearance only. No tolerances, fabrication detail, PCB layout or purchasing work was added. `trl` stays 3, and TRL 4 remains on hold by Amish's instruction. Previews were checked with the kit renderer; the photoreal renders are left to the orchestrator. No git commands were run in this session, by instruction.

## Session 2026-09-27: kit 1.5.0 and image quality

- Kit 1.5.0 synced: STANDARDS v1.5 (sections 12 to 15: product renders, storefront images and image quality, public release, authorship and signing), `.kit/cards.py`, `.kit/image_qc.py`, `.kit/release_gate.py`, issue templates, and the `/render-product` and `/release` commands. `CLAUDE.md` now matches `.kit/CLAUDE.md`.
- Every `media/render-*.png` recaptioned from its original render with the new layout: the title, concept label and repository sit in a band above the render and the view note in a band below it, each line wrapped to the image width, so no text overlaps other text or the render or runs off the image. `media/card.png` and `media/social-preview.png` regenerated with the same rules.
- `python .kit/image_qc.py` and `python .kit/release_gate.py` pass. trl stays 3.

## Session 2026-10-01: kit 1.7.0, constructable design and build plan

Amish approved the build plan format on 2026-09-30 and asked for it across all repos, with outstanding decisions kept in a separate design decisions register. Under his 2026-09-30 instruction to make the design physically buildable ("If you are realising that the design cannot be built as per concept - fix the design assumptions to match and be physically feasible as you draw the illustrations."), this session made the PotholeLog design constructable and wrote the build plan. No git commands were run, by instruction.

### What was done

- Kit 1.7.0 installed (`.kit/`, `.claude/commands/`); `CLAUDE.md` now matches `.kit/CLAUDE.md`.
- `cad/src/model.py`: constructable design with 48 build123d constructability checks (`python cad/src/model.py --check`), all passing. STEP and STL re-exported.
- `docs/decisions/0003-design-for-construction.md` (PHL-DDR-003 v0.1, Draft): every change, with the reason; three questions "Proposed, awaiting Amish" (A1 to A3).
- `bom/bom.csv`: line 12 (module carrier plate, $2.00) and line 13 (box fixing kit, $1.50) added; lines 1, 2, 4, 5, 7, 8 and 11 respecified; line 11 repriced to $2.50. Estimated cost $74.00.
- `docs/04-calcs/sizing.py` and `01-sizing.md` (PHL-CAL-001 v0.3): mass, crash loads, plate stiffness and cost re-run; cost written against the value-engineering target.
- `docs/02-concept.md` (PHL-PRC-001 v0.5), `docs/03-requirements.md` (PHL-REQ-001 v0.5), `docs/01-problem.md` (PHL-PRB-001 v0.5): figures and value-engineering wording.
- `cad/drawings/PHL-DWG-001` Rev P3 (`cad/src/sheets.py`); concept media regenerated (`cad/src/concept_media.py`: hero, blueprint, exploded with callouts 1 to 13, cutaway, flow, model.glb).
- `cad/src/build_plan_media.py`: overview, making sketches PHL-DWG-101 (mounting plate), 102 (enclosure base drilling) and 103 (module carrier plate), plate and box hole layouts, six joint close-ups, nine assembly step pictures and a block wiring diagram. Every picture was inspected; `drawing.py --check-text` is clean.
- `docs/05-build-plan.md` (PHL-BLD-001 v0.1) and `docs/06-design-decisions.md` (PHL-DEC-001 v0.1). `project.yaml`: `design_state: constructable`, both new documents and PHL-DDR-003 in `trl_evidence`; `budget_usd` unchanged. README: links line, "Building the prototype" section, value-engineering wording.
- `cad/src/product_model.py`: one key renamed so it still builds (controller standoff height); its appearance is otherwise unchanged.

### Design changes made for construction (PHL-DDR-003)

1. The box is held to the plate by four M4 male-female hex standoffs on 80 x 40 mm, through the floor into tapped holes in the plate (was four screws on 100 x 70 mm, two of them under the converter and all four on the box's corner pillars).
2. A 92 x 76 x 1.5 mm aluminium carrier plate on the standoffs holds the converter and controller on nylon standoffs and the supercapacitor with a cable tie; a window leaves the IMU clear (the modules had no fixings).
3. The converter is turned 90 degrees and the modules rearranged so nothing overlaps (the supercapacitor overlapped the controller by 0.5 mm).
4. The gland has a 16.2 mm hole in the rear end wall and a locknut inside, with 4.5 mm or more to the carrier and modules.
5. The IMU is held by two M3 screws through the box floor into the plate, so it is clamped to the aluminium.
6. The GNSS module is held under the lid by a pad of acrylic foam tape, with a plug-in lead.
7. The stock box's corner pillars and lid screws are modelled and every part is clear of them.
8. The floor holes are sealed with a ring of neutral-cure silicone under the box.

Knock-on: logger 0.43 kg (was 0.37 kg), 0.57 kg with lead and fixings; plate first mode 168 Hz (was 186 Hz; R12's 150 Hz still met on paper); estimated cost $74.00, $1.00 under the $75 value-engineering target. Requirement status unchanged: 0 not met, 6 at risk, 2 not verifiable, 4 met on paper, 4 met by design.

### Proposed, awaiting Amish

All open items are in `docs/06-design-decisions.md`: O1 pilot partner; the four appearance items of 2026-09-26 (clear lid window, light pipes, breather vent, nameplate); the CityTwin ingest path; and PHL-DDR-003 A1 (floor hole sealing), A2 (GNSS fixing) and A3 (spanner room at the M6 bolts).

### Stale media (made on Amish's Mac)

The outside of the logger is unchanged, so `media/render-hero.png`, `media/card.png` and `media/social-preview.png` are still true. `media/render-exploded.png` and `media/render-detail.png` show the concept's internal layout (no carrier plate, converter on the floor) and are stale; `cad/src/product_model.py` needs the carrier and new layout before they are re-rendered.

### Safety

- The build plan keeps bench power to a fused, current-limited supply and leaves vehicle fitting outside the plan, with safety stops before first power, before tests above 30 V and before any vehicle fitting.
- Concerns from earlier sessions stand: the 1.9 V margin over the TVS clamp, projectile risk if bolted to thin panels, and location privacy.

### Recommended next step

Amish reviews PHL-DDR-003 and the register. TRL 4 (building to this plan and testing) remains on hold by his instruction.

## Session 2026-10-02: open-decision recommendations approved

Amish, 2026-10-02: "i approve your recommendations for all 555 open decisions." This approves the recommendation for every open decision in the design decisions register. 9 decisions were recorded: each moved to Decisions made, dated 2026-10-02, with the approved recommendation and its record. trl stays 3; no build or test work was done, and the CAD model, BOM quantities and prices, and pictures were not changed.

### Documents changed

- `docs/06-design-decisions.md` (PHL-DEC-001 v0.2): the nine open decisions moved to Decisions made; Open decisions now reads none; value engineering notes the light pipes and vent take the estimate about USD 2 to 3 over the target
- `docs/decisions/0003-design-for-construction.md` (PHL-DDR-003 v0.2): A1 to A3 accepted with their fallbacks; Tables 1 and 2 stayed open for review (no register item asked for them) until Amish accepted them later on 2026-10-02 (see the next session)
- `docs/decisions/0001-trl2-review-decisions.md` (PHL-DDR-001 v0.3): O1 (first pilot partner) decided
- `docs/decisions/0002-recommendations-accepted.md` (PHL-DDR-002 v0.2): O1 decided; CityTwin ingest path decided
- `docs/03-requirements.md` (PHL-REQ-001 v0.6): R13 restated (dates published only when pooled, never pass times); R14 ingest path decided; R15 notes the cost of the light pipes and vent; no status changed
- `docs/04-calcs/01-sizing.md` (PHL-CAL-001 v0.4): requirement table wording for R13 and R14; no result changed
- `docs/02-concept.md` (PHL-PRC-001 v0.6): lid light pipes and nameplate, breather vent, clear window renders only, CityTwin path and pooled dates, first pilot partner
- `docs/01-problem.md` (PHL-PRB-001 v0.6): first pilot partner stated
- `bom/bom-notes.md`: adopted lid details and vent noted, not yet in the BOM; no quantity or price changed
- PDFs regenerated with `python3 .kit/render.py`; superseded PDF versions removed by the render.

### Follow-up actions to carry approved decisions into the design

1. Decision 3 (model): Add two sealed light pipe holes in the lid and the two status LEDs with their wires to `cad/src/model.py` and its checks
2. Decision 4 (model): Add the breather vent hole in the front end wall to `cad/src/model.py` and check its clearance to the modules
3. Decision 3 (bom): Add the light pipes and LEDs, the breather vent and the nameplate label to `bom/bom.csv` and price them
4. Decision 3 (calcs): Re-run `sizing.py` for the new total and update R15 in PHL-CAL-001 and PHL-REQ-001 (about USD 2 to 3 over the target)
5. Decision 3 (drawings): Update the general arrangement PHL-DWG-001 and the lid and box making sketches with the light pipe and vent holes
6. Decision 3 (pictures): Regenerate the build plan pictures and text for the lid, box drilling and wiring steps with the light pipes, vent and label
7. Decision 2 (pictures): Keep the clear lid window in the product renders only; check that `cad/src/product_model.py` marks it as a render detail
8. Decision 6 (docs): Agree the segment file fetch and pooled-date rule with CityTwin's item 6 so the formats match, and write the pooling rule into the server export

### Points found in the review

- There was no open item to accept PHL-DDR-003, yet the register listed it under Decisions made as "open for his review"; the recommendation was to accept. Amish accepted it later on 2026-10-02 (see the next session).
- Item 6 is already decided on the CityTwin side (CTW-DDR-001, D11, outbound pull); decide it together with CityTwin's item 6 so the formats match.
- Items 3 and 4 together take the estimate to about $2 to $3 over the $75 target; the register states only the vent's effect.

## Session 2026-10-02: design-for-construction changes accepted

Amish, 2026-10-02: "APPROVED: Design-for-construction changes in 10 repos (CityTwin, CoolShade, PalletPilot, Heliolite, PotholeLog, EarthPress, ReadyKit, CellCheck, CargoMule and ThermaCart)". This accepts the design-for-construction changes in Tables 1 and 2 of PHL-DDR-003 (P1 to P7 and their knock-on changes), which were left open for his review when the open decisions were decided earlier the same day. No other item is decided by it. trl stays 3; no build or test work was done, and the model, BOM, calculations and pictures are unchanged.

### Documents changed

- `docs/decisions/0003-design-for-construction.md` (PHL-DDR-003 v0.3, status Draft): status line now "accepted" with Amish's words.
- `docs/06-design-decisions.md` (PHL-DEC-001 v0.3): Decisions made row added, dated 2026-10-02; the 2026-10-01 row no longer calls the changes open for review.
- `docs/05-build-plan.md` (PHL-BLD-001 v0.2): section 2 says PHL-DDR-003 is accepted.
- PDFs regenerated.

### Recommended next step

No change: the follow-up actions of the previous session stand. TRL 4 remains on hold by Amish's instruction.

## Session 2026-10-02: approved follow-ups carried out

Amish, 2026-10-02: "497 follow-up actions that need CAD, drawing, picture, BOM or calculation work ... APPROVED CHANGES, COMPLETE THESE", and "Photoreal renders are out of date in most repos ... COMPLETE THESE". This session carried the decisions of 2026-10-02 into the design. trl stays 3; no build or test work was done; `budget_usd` is unchanged. No git commands were run, by instruction.

### Follow-ups (from the list of the open-decision session above)

1. Done. Light pipes and LEDs in the model: `cad/src/model.py` has two 6.4 mm sealed holes in the lid (30 mm right of centre, 40 and 30 mm toward the rear), two panel-mount light pipes with inside nuts, a 5 mm LED in each and their wire pair routed under the GNSS module to the controller (BOM line 14). Checks added for the seal, nuts, pillars, GNSS, LEDs and wire clearances.
2. Done. Breather vent in the model: a 12.2 mm hole in the front end wall on the centre line, 30 mm up, with an M12 vent and inside locknut (BOM line 15); the nut is 8.5 mm clear of the converter, 3.8 mm clear of the lid and 12.2 mm clear of the carrier. The nameplate label is modelled on the lid top (BOM line 16). 68 of 68 constructability checks pass (was 48); STEP and STL re-exported.
3. Done. `bom/bom.csv`: lines 14 (light pipes, LEDs and lead, $1.00), 15 (breather vent, $2.00) and 16 (nameplate label, $0.50) added with a price basis each; lines 2 and 3 respecified for the new holes. `bom/bom-notes.md` updated (total, mass, basis).
4. Done. `docs/04-calcs/sizing.py` re-run: logger 0.44 kg, 0.58 kg with lead and fixings [H2]; 22 N per M6 bolt at 20 g [H3]; plate first mode 168 Hz, unchanged [I1]; cost $77.50 [J1]. PHL-CAL-001 v0.5, PHL-REQ-001 v0.7 and PHL-DEC-001 v0.4 updated. Value-engineering target: USD 75. Estimated cost of the constructable design: USD 77.50 (USD 2.50 over the target).
5. Done. General arrangement PHL-DWG-001 Rev P4 (vent, light pipe holes and nameplate called out; notes updated). Making sketch PHL-DWG-102 adds the front wall vent hole; new lid drilling sketch PHL-DWG-104 (P1).
6. Done. Build plan pictures regenerated: overview (17 components), box hole layout (vent hole and front wall note), new joints 7 (light pipe in the lid) and 8 (vent in the front wall), step 1 (gland and vent), new step 7 (light pipes and nameplate onto the lid), steps 8 to 10 renumbered, wiring (status LEDs). `docs/05-build-plan.md` PHL-BLD-001 v0.3: section 1, 3.2, new 3.8 (lid drilling), 3.5.1 wiring, bought parts, steps, first checks and sources.
7. Done. `cad/src/product_model.py` marks the clear GNSS window as a render detail only (the build lid is opaque) and takes the light pipe, vent and nameplate sizes and positions from `model.py`. Its internals were also brought to the constructable design: carrier plate on the hex standoffs, modules on nylon standoffs, IMU on two screws, status LEDs and lead.
8. Partly done. The pooling rule is written into the server export description in PHL-PRC-001 v0.7 ("Server export: segment files and the pooling rule"): a date per segment, day only, only when at least two vehicles or at least three separate days are pooled; pass times, vehicle identifiers, tracks and speeds never exported. The three-day reading of "several days" is Proposed, awaiting Amish, to be matched with CityTwin. Agreeing the format with CityTwin's item 6 is not done here: cross-repo (see below). No server code was written (TRL 4 software).

Also changed: concept media regenerated (`cad/src/concept_media.py`: hero, blueprint key figures 0.44 kg and $77.50, exploded with callouts 1 to 16, cutaway, flow, model.glb); README cost figures; PHL-PRB-001 v0.7 cost line. `python3 .kit/drawing.py --check-text` is clean.

### Requirement status change

- R15 (low cost): met on paper to **not met**, $77.50 against the $75 value-engineering target ($2.50 over). Counts now: 1 not met, 6 at risk, 2 not verifiable at TRL 3, 3 met on paper, 4 met by design. The register lists savings (offcut plates, a 16 GB card) that could close the gap.

### Cross-repo actions

- CityTwin: match its item 6 (segment file fetch and pooled-date rule) to the PotholeLog export: daily CSV and GeoJSON files fetched over HTTPS, a day-only date per segment only when at least two vehicles or at least three days are pooled, no pass times. Field names to agree.

### Render scenes

`cad/src/product_model.py` exported with `.kit/export_views.py` to `/home/claude/renders/potholelog` (hero, exploded, detail: one .npz and .json each, plus `potholelog__jobs.json`). Photoreal renders, `media/card.png` and `media/social-preview.png` are to be made on Amish's Mac; until then `media/render-*.png` show the concept layout and no carrier plate.

### Proposed, awaiting Amish

- The "several days" in the pooling rule read as three or more separate days.
- R15 is over the target; whether to take the savings in the register or accept the overrun is Amish's call (`budget_usd` left at $75).

## 2026-10-02: photoreal renders redone on the constructable design

Rendered with Blender Cycles on Amish's Mac from the updated appearance model; captioned with `.kit/photo_caption.py`; `media/card.png` and `media/social-preview.png` regenerated with `.kit/cards.py`. Views: hero, exploded, detail. image_qc passes. Appearance deviations are those logged above as proposed, awaiting Amish.

## 2026-10-03: decisions recorded

Amish decided on 2026-10-03: "Cost over target - i accept all the cost variations and overruns". Recorded for this repo: the estimated cost of USD 77.50 against the USD 75 target (USD 2.50 over), accepting the USD 2.50 overrun on R15.

- `docs/06-design-decisions.md`: row added to decisions made; value engineering section says the overrun was accepted by Amish on 2026-10-03.

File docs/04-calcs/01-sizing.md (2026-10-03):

---
doc_id: PHL-CAL-001
title: PotholeLog sizing calculations
project: PotholeLog
doc_type: Calculation
version: "0.5"
status: Draft
date: '2026-10-02'
author: Amish Chadha
license: CERN-OHL-S-2.0
revisions:
- version: "0.1"
  date: '2026-09-25'
  author: Amish Chadha
  change: First issue for TRL 3 (vehicle and road model, roughness signal and calibration, pothole detection, location, storage and upload, power and transients, hold-up, environment, plate stiffness, installation, cost)
- version: "0.2"
  date: '2026-09-25'
  author: Amish Chadha
  change: Recommendations accepted by Amish (DDR-002)
- version: "0.3"
  date: '2026-10-01'
  author: Amish Chadha
  change: Design made constructable (PHL-DDR-003); mass, fixings, plate stiffness and cost re-run; budget treated as a value-engineering target
- version: "0.4"
  date: '2026-10-02'
  author: Amish Chadha
  change: 'Requirement table wording for R13 and R14 follows the decisions of 2026-10-02; no result changed'
- version: "0.5"
  date: '2026-10-02'
  author: Amish Chadha
  change: 'Approved follow-ups carried out: status light pipes and LEDs, breather vent and nameplate label (BOM lines 14 to 16) added to the model and BOM; mass, fixings, stiffness and cost re-run; R15 moves from met on paper to not met ($2.50 over the target)'
---

# PotholeLog sizing calculations

On paper, PotholeLog meets seven of its sixteen requirements (three by calculation, four by design), has six at risk, cannot show two at TRL 3 and misses one (R15, cost, $2.50 over the value-engineering target since the parts adopted on 2026-10-02). Version 0.2 applies Amish's 2026-09-25 decisions (PHL-DDR-002). Version 0.1 found two misses. First, a bus tyre largely bridges the R1 reference pothole (50 mm deep, 300 mm long), so a floor-mounted logger sees it clearly only at low speed: in the quarter-car model the impact stands above ordinary road vibration up to about 20 km/h on a fair road (IRI 4) and about 50 km/h on a good one (IRI 2), and not at 80 km/h. R5's defect-detection range is now restated as 10 to 30 km/h, relying on repeat slow passes near stops and junctions; it is met on good roads and misses by a hair (margin 0.97) at 30 km/h on fair ones, so R5 moves from not met to at risk, and R1 stays at risk. Second, the 9 to 36 V converter was exceeded by a suppressed load dump on a 24 V vehicle. The BOM now carries a 60 V-rated converter, which clears the 58 V load dump and the 58.1 V TVS clamp by 1.9 V; the TVS pulse energy is unverified, so R9 moves from not met to at risk. Version 0.3 re-runs the mass, fixing, stiffness and cost lines for the constructable design of PHL-DDR-003, which adds a carrier plate for the modules and a box fixing kit: the logger is now 0.43 kg, the plate's first mode 168 Hz (still above the 150 Hz target) and the estimated cost $74.00, $1.00 under the $75 value-engineering target. Version 0.5 adds the status light pipes and LEDs, the breather vent and the nameplate label that Amish adopted on 2026-10-02: the logger is 0.44 kg, the first mode stays at 168 Hz and the estimated cost is $77.50, $2.50 over the target, so R15 moves from met on paper to not met. The roughness function itself looks sound: the signal is 12 times the sensor noise at 20 km/h on a smooth road, and a synthetic calibration against IRI gives r² of 0.93 from one pass and 0.99 from five. Every number in this note is printed by `docs/04-calcs/sizing.py`; the tag in brackets, for example [C2], is the line of that script's output that carries it.

> **Safety:** These are first-principles estimates for a paper proof of concept. They are not a survey method, an automotive electrical approval or a mounting approval. Outputs must not drive contract acceptance or safety decisions without validation against a calibrated reference. See PHL-PRC-001, Safety.

## Scope and method

The note checks every requirement in PHL-REQ-001 v0.5 against the design in PHL-PRC-001 v0.5, the constructable design of PHL-DDR-003 and the parametric model `cad/src/model.py`. The script imports the model's `PARAMS`, derived dimensions and part volumes, so the plate, hole pattern, enclosure and masses used here are the ones in the STEP files and in drawing PHL-DWG-001. It also reads `bom/bom.csv` and `budget_usd` in `project.yaml`. Run it from the repo root with `python docs/04-calcs/sizing.py`.

The vehicle is a linear quarter-car model of one side of a 12 m city bus's rear axle: sprung body, unsprung axle and twin tyres. Random road profiles follow the ISO 8608 spectral shape and are solved in the frequency domain; their IRI comes from the standard golden-car model at 80 km/h, following World Bank Technical Paper 46. A single pothole is enveloped by a rigid tyre circle and solved in the time domain. The logger reads the body's vertical acceleration at the floor centerline above the axle.

## Assumptions

*Table 1. Main assumptions.*

| Area | Assumption | Basis |
| --- | --- | --- |
| Vehicle | Per side: sprung mass 4,500 kg (3,500 empty to 5,250 laden), unsprung 500 kg; body frequency 1.2 Hz with 20 % damping (air suspension); twin tyres 1.8 MN/m; tyre radius 0.52 m; wheelbase 6 m | Typical 12 m city bus; to confirm with the pilot fleet |
| Road | ISO 8608 displacement spectrum with slope 2 (1.8 to 2.2 for the calibration study), 0.01 to 10 cycles/m, 250 mm moving average as the tyre patch | ISO 8608 shape; the classes are mapped to IRI in [A2] |
| Logger position | Floor centerline above the axle sees half of a one-sided input (bounce only) and 0.87 of the single-track random input (left and right tracks correlated at 0.5) | Assumed; roll and pitch are not modeled |
| Sensor | 400 Hz output, ±16 g, noise about 100 µg/√Hz; roughness metric band 0.5 to 20 Hz | LSM6DSO class; to confirm from the datasheet |
| Detection | A pothole is detected when its floor peak exceeds the level that ordinary roughness crosses once per km (Rice formula, Gaussian roughness); lateral wander σ 250 mm; twin-tyre width 0.6 m | Assumed; real roads have joints, covers and bumps that are not Gaussian |
| Location | M10-class GNSS, open-sky CEP 1.5 m; σ 3 m per axis suburban, 10 m in dense urban streets with errors 0.5 correlated between passes; PPS time-stamping to 10 ms | Class figures; urban values assumed |
| Data | 6 axes x 16 bit at 400 Hz; 40 B GNSS record at 10 Hz; 8 B time stamp per 100 samples; 10 to 12 h of driving and 200 km a day; 500 events a day; 32 GB card with 94 % usable | As at TRL 2, with the record layout now defined |
| Power | 3.3 V loads 91 mA (ESP32-S3 60 mA at 240 MHz with radio off, board 10 mA, GNSS 10 mA, card 10 mA average, IMU 1 mA); linear regulator on the board from 5 V; 85 % converter efficiency; Wi-Fi adds 150 mA while uploading | Typical module figures; to confirm by measurement later |
| Transients | Suppressed load dump of 35 V (12 V systems) and 58 V (24 V systems), as understood from ISO 16750-2 test B | To confirm from the standard |
| Hold-up | 1 F, 5.0 V rail less a 0.3 V diode, regulator dropout floor 3.6 V; capacitance 70 % at end of life and at -20 °C; 1 s to flush and close files | Typical supercapacitor data; worst-case card write latency |
| Structure | Aluminum E = 70 GPa; plate on four corner bolts with nothing beneath, half the width effective; 20 g crash pulse, M6 property class 8.8 | Conservative screening values, not a vehicle-code check |

## A. Road and vehicle model

- **Vehicle.** The bus corner has a 1.2 Hz body mode (256 kN/m, 13.6 kN·s/m) and a 10.2 Hz wheel-hop mode [A1].
- **Road classes on the IRI scale.** ISO 8608 classes A, B, C and D come out at 2.17, 4.35, 8.69 and 17.38 m/km [A2]. IRI scales with the square root of the spectrum level, so IRI 2, 4 and 6 m/km correspond to Gd(n₀) of 13.6, 54.2 and 122.0 x 10⁻⁶ m³ [A3]. In this note "IRI 2" stands for a good urban road and "IRI 4" for a fair one.

## B. Roughness signal and calibration (R3, R5)

- **Noise.** The IMU's noise over the 0.5 to 20 Hz band is 4.3 mm/s² RMS, and one count at ±16 g is 4.8 mm/s² [B1].
- **Signal.** The floor RMS acceleration in that band rises with IRI and with speed [B2]:

*Table 2. Floor RMS acceleration in the 0.5 to 20 Hz band, m/s² [B2].*

| IRI | 10 km/h | 20 km/h | 30 km/h | 50 km/h | 80 km/h |
| --- | --- | --- | --- | --- | --- |
| 1 m/km | 0.031 | 0.051 | 0.066 | 0.089 | 0.114 |
| 2 m/km | 0.062 | 0.102 | 0.133 | 0.178 | 0.228 |
| 4 m/km | 0.123 | 0.204 | 0.266 | 0.356 | 0.456 |
| 6 m/km | 0.185 | 0.306 | 0.398 | 0.533 | 0.684 |

- **Low speed.** On a smooth road (IRI 1) the signal is 7 times the noise at 10 km/h and 12 times at 20 km/h [B3]. The 20 km/h floor of the roughness range in R5 is supported; the sensor is not the limit.
- **Speed.** At IRI 2 the RMS at 80 km/h is 2.23 times the 20 km/h value; even normalized by the square root of speed it varies 1.31 to 1 over 10 to 80 km/h [B4]. The metric must be calibrated per speed band, as TRL 2 assumed.
- **Scatter.** A 100 m segment at 50 km/h holds 7.2 s of data. With an effective bandwidth of 3.33 Hz, one RMS estimate scatters by 14 %, falling to 6 % averaged over five passes [B5].
- **Calibration.** For 40 synthetic sections from IRI 1 to 8 m/km with spectral slopes from 1.8 to 2.2, a straight-line fit of IRI on floor RMS gives r² of 0.998 with expected values, 0.934 from one pass and 0.992 from five passes, with a slope of 11.1 m/km per m/s² [B6]. This supports the response-type method and the R3 target of r² 0.8, but only a calibration on real reference sections can verify R3.
- **Load.** From empty to laden, the floor RMS changes from 1.07 to 0.96 of its mid-load value with air suspension, and from 1.22 to 0.89 with steel springs [B7]. Buses with air suspension need no load correction beyond this ±7 %; refuse trucks on steel springs need a load flag or calibration by load state.

## C. Pothole detection (R1, R2, R5, R6)

- **The tyre bridges the hole.** A 1,040 mm tyre can drop only 22.1 mm into a 300 mm long pothole, however deep it is, and the loaded tyre's contact patch is about 337 mm long [C1]. A bus sees the R1 reference pothole as a 22 mm dip.
- **Floor peak against background.** The floor peak from the reference pothole falls with speed while ordinary road vibration rises:

*Table 3. Reference pothole (50 mm deep, 300 mm long) against a threshold that ordinary roughness crosses once per km [C2], [K1].*

| Speed | Floor peak | Threshold, IRI 2 | Margin, IRI 2 | Threshold, IRI 4 | Margin, IRI 4 |
| --- | --- | --- | --- | --- | --- |
| 10 km/h | 1.35 m/s² (0.138 g) | 0.24 m/s² | 5.64 | 0.48 m/s² | 2.82 |
| 20 km/h | 1.20 m/s² | 0.40 m/s² | 3.03 | 0.79 m/s² | 1.51 |
| 30 km/h | 0.98 m/s² | 0.51 m/s² | 1.94 | 1.01 m/s² | **0.97** |
| 50 km/h | 0.71 m/s² | 0.66 m/s² | 1.07 | 1.32 m/s² | **0.54** |
| 80 km/h | 0.48 m/s² | 0.82 m/s² | **0.59** | 1.64 m/s² | **0.30** |

Margins below 1 (bold) mean the pothole is lost in ordinary road vibration.

- **Relaxing the threshold does not rescue high speed.** Allowing 10 background crossings per km, which clustering over repeat passes could tolerate, raises the IRI 4 margins only to 1.17 at 30 km/h and 0.66 at 50 km/h [C2b]. A band-pass detector tuned to the wheel-hop band gave similar margins in a side check, so the limit is physical, not the choice of filter.
- **Longer potholes are found at all speeds.** A 50 mm deep pothole 600 mm long lets the tyre reach the bottom and gives margins of 5.28 at 10 km/h, 2.63 at 50 km/h and 1.67 at 80 km/h on an IRI 4 road [C2c].
- **Wheel path.** The twin tyres hit a 300 mm pothole centered in the wheel path on 93 % of passes, and on at least one of three passes 99.96 % of the time [C3]. The limit is detection per hit, not the chance of a hit.
- **R1 is at risk and R5 is not met.** In urban service a bus often passes a spot at 20 km/h or less, near stops and junctions, and R1 allows three passes, so R1 may still be met on streets with low speeds; it cannot be shown without field data. The original R5 defect-detection range of 10 to 80 km/h was not met for the reference pothole at 30 km/h and above on fair roads, or at 80 km/h on good ones. Under PHL-DDR-002 (N2) the range is restated as 10 to 30 km/h. Across that band the lowest margin is 1.94 on IRI 2 roads and 0.97 at 30 km/h on IRI 4 roads, or 1.17 allowing 10 background crossings per km [K2]. R5 is at risk rather than not met.
- **Range and sampling (R6).** The floor peak is at most 0.14 g, far inside ±16 g. An axle mount would see about 9 g in this linear model, 65 times more, with water and stones [C4], which supports the floor mount (D3). Sampling at 400 Hz keeps 99 % or more of the floor peak; samples are 35 mm apart at 50 km/h and 56 mm at 80 km/h, giving 9 and 5 samples across the pothole [C5].
- **Two axles.** The front and rear axle impacts arrive 0.72 s apart at 30 km/h and 0.43 s at 50 km/h [C6]. Pairing them confirms an event and fixes which axle hit it.
- **R2 cannot be shown at TRL 3.** Joints, drain covers and speed bumps are not Gaussian roughness, and they are the likely false reports. Only a field check of reported clusters can verify R2.

## D. Location (R4)

*Table 4. 95 % location radius [D1].*

| Setting | σ per axis | One pass | 10-pass cluster |
| --- | --- | --- | --- |
| Open sky | 1.3 m | 3.1 m | 1.0 m |
| Suburban | 3.0 m | 7.3 m | 2.3 m |
| Dense urban | 10.0 m | 24.5 m | 18.2 m (errors correlated) |

- **Timing.** With PPS, a 10 ms IMU-to-GNSS error is 0.22 m at 80 km/h; using message times alone, 100 ms is 2.2 m. Fixes are 2.2 m apart at 10 Hz and 80 km/h [D2]. BOM item 8 now calls for a PPS output.
- **Axle.** An event attributed to the wrong axle is misplaced by the 6 m wheelbase [D3]; axle pairing (section C) removes this.
- **R4 is at risk.** The 10 m target is met in open and suburban streets but not in dense urban streets, where multipath errors repeat from pass to pass and do not average out. Map matching to the street centerline is the likely fix and is a later software task.

## E. Storage and upload (R7, R8)

- **Raw data.** 5.23 kB/s, or 188 MB per 10 h day and 226 MB per 12 h day [E1]. A 32 GB card holds 160 days at 10 h or 133 days at 12 h [E2], far beyond the 30 days of R7. Over five years the card is written 14 times over (412 GB) [E3], well within a high-endurance card's rating. **R7 is met on paper.**
- **Summaries.** A 48 B segment record and a 32 B event record give 112 kB a day for 200 km and 500 events [E4]. The pass time is kept only in the operator's copy (R13).
- **Upload.** At 2 Mbit/s effective at the edge of depot coverage the upload takes 8.4 s, most of it connecting; a day of raw data would take 13 min, so raw data stays on the card [E5]. The hold-up capacitor can power Wi-Fi for only 2.3 s [G3], so the upload runs while the ignition is on: on arrival at the depot or at the next start. **R8 is met on paper** for vehicles in daily service that spend at least about 10 s with the ignition on within depot Wi-Fi.

## F. Power and transients (R9)

- **Running power.** The 3.3 V loads draw 91 mA, which is 0.45 W at 5 V through the board's linear regulator and 0.54 W from the vehicle [F1]: 45 mA at 12 V, 22 mA at 24 V and 59 mA at 9 V, well within the 2 A fuse [F2]. Uploading raises this to 1.42 W for about 8 s a day; a 10 h day uses 5.4 Wh [F3]. The running target of under 1 W is met; the brief upload peak exceeds it. With an ignition-switched feed there is no draw with the ignition off. The TRL 2 estimate of 0.7 W was conservative and is revised to 0.54 W.
- **Transients.** Under PHL-DDR-002 (N1) the converter is rated 60 V (v0.1 used a 36 V part). Normal 12 V (9 to 16 V) and 24 V (18 to 32 V) supplies and both suppressed load dumps, 35 V on 12 V systems and 58 V on 24 V systems, are within the 60 V input [F4]. The SMBJ36A-class TVS clamps at up to 58.1 V, which the 60 V converter clears by 1.9 V [F5]. The TVS conducts during a 24 V load dump, and a pulse lasting hundreds of milliseconds may overheat it; only a bench test can show that it survives. **The transient part of R9 is at risk** for 24 V vehicles, rather than not met. A surge-stopper front end remains the fuller fix and was not chosen.

## G. Hold-up (R10)

- **Hold-up time.** 1 F from 4.7 V to 3.6 V stores 4.57 J, which lasts 10.0 s new and 7.0 s at 70 % capacitance; closing files needs about 1 s, a factor of 7 [G1]. The TRL 2 estimate of about 9 s stands for a new capacitor. **R10 is met on paper.** The controller should start shutdown only after about 2 s of low input, so engine cranking dips are ridden through rather than logged as a stop.
- **Charging.** Through 10 Ω the capacitor reaches 95 % in 30 s; the 0.5 A charge peak is within the 1 A converter [G2].

## H. Environment and fixings (R11)

- **Self-heating.** 0.54 W over 339 cm² of box raises the inside by 2.0 K, so at +70 °C ambient the parts see about 72 °C [H1]. The GNSS, IMU, converter and a high-endurance card are commonly rated to 85 °C, but many supercapacitors are rated to 70 °C and some ESP32-S3 module variants (those with octal PSRAM) are rated to 65 °C. BOM items 5, 6 and 10 now state the grades needed. Parked in the sun with the ignition off, the logger sees only storage temperature.
- **Mass.** The plate is 187 g, the polycarbonate enclosure with its moulded lid-screw pillars 143 g, the modules on their carrier 90 g (of which the aluminium carrier is 24 g and its standoffs, screws and tape 21 g) the gland 12 g, and the light pipes, vent and label adopted on 2026-10-02 8 g: 0.44 kg for the logger, 0.58 kg with the 2 m lead and fixings [H2]. The TRL 2 estimate of 0.4 kg is close.
- **Fixings.** A 20 g crash pulse puts 86 N on the plate, 22 N per M6 bolt against about 9.6 kN of shear capacity, and 46 N on the four M4 hex standoffs that hold the box to the plate [H3]. Strength is not a concern; loosening under long-term vibration is, and only a test can show that locking nuts suffice.
- **R11 is at risk:** the temperature margin depends on part grades, and vibration and loosening cannot be verified at TRL 3.

## I. Plate stiffness and installation (R12)

- **Stiffness.** Spanning 140 mm between corner bolts with nothing beneath, on half its width, the 4 mm plate has a stiffness of 359 kN/m under a moving mass of 323 g and a first mode of 168 Hz; on full-width supports it is 237 Hz [I1]. A 3.7 mm plate would just reach 150 Hz on the conservative model [I2], so the 4 mm plate keeps a small margin. The bracket part of R12 is met on paper. The mode sits near the 200 Hz Nyquist limit, so the IMU's internal low-pass filter should be set well below 200 Hz. A thin floor panel has its own lower modes, so the plate should bolt to a crossmember, seat rail or other stiff structure.
- **Installation time.** The tasks add up to 30 min, exactly the R12 limit [I3]. Tool clearance around the bolts is tight: the hole centers are 10 mm beyond the box end walls, leaving about 2 mm for a 10 mm socket [I4]; a ring spanner or a thin-wall socket is needed, and the build plan uses a ring spanner on the assembled logger. **R12 is at risk** on installation time.

## J. Cost (R15)

Value-engineering target: USD 75 (`budget_usd`, a hypothetical control target, not a limit). Estimated cost of the constructable design: USD 77.50 from the 16-line BOM (USD 2.50 over the target) [J1]. The 60 V converter added about $2 under PHL-DDR-002 (N1), the carrier plate and box fixing kit added for construction (PHL-DDR-003) add $3.50, and the status light pipes and LEDs ($1.00), breather vent ($2.00) and nameplate label ($0.50) adopted by Amish on 2026-10-02 add $3.50 [J2]. **R15 is not met:** the estimate is over the target. The savings listed in the design decisions register (PHL-DEC-001) could close the gap; `budget_usd` is unchanged. The LTE-M option would bring the cost to $98 to $108 [J2], over the target; it is not in the BOM.
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

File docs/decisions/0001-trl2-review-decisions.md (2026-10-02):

---
doc_id: PHL-DDR-001
title: PotholeLog TRL 2 review decisions
project: PotholeLog
doc_type: Design decision record
version: "0.3"
status: Draft
date: '2026-10-02'
author: Amish Chadha
license: CERN-OHL-S-2.0
revisions:
- version: "0.1"
  date: '2026-09-25'
  author: Amish Chadha
  change: Record the TRL 2 review items adopted as recommended for TRL 3 work and the items that remain open
- version: "0.2"
  date: '2026-09-25'
  author: Amish Chadha
  change: Recommendations accepted by Amish (DDR-002)
- version: "0.3"
  date: '2026-10-02'
  author: Amish Chadha
  change: 'O1 (first pilot partner) decided by Amish on 2026-10-02'
---

# 0001: TRL 2 review decisions

- **Date:** 2026-09-25
- **Status:** items D1 to D7 decided by Amish, 2026-09-25: go with recommendation (see PHL-DDR-002); item O1 decided by Amish on 2026-10-02 (PHL-DEC-001).

## Context
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

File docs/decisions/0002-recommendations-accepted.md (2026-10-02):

---
doc_id: PHL-DDR-002
title: PotholeLog recommendations accepted
project: PotholeLog
doc_type: Design decision record
version: "0.2"
status: Draft
date: '2026-10-02'
author: Amish Chadha
license: CERN-OHL-S-2.0
revisions:
- version: "0.1"
  date: '2026-09-25'
  author: Amish Chadha
  change: Record the recommendations accepted by Amish on 2026-09-25, what changed in the repo, and the items still open
- version: "0.2"
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

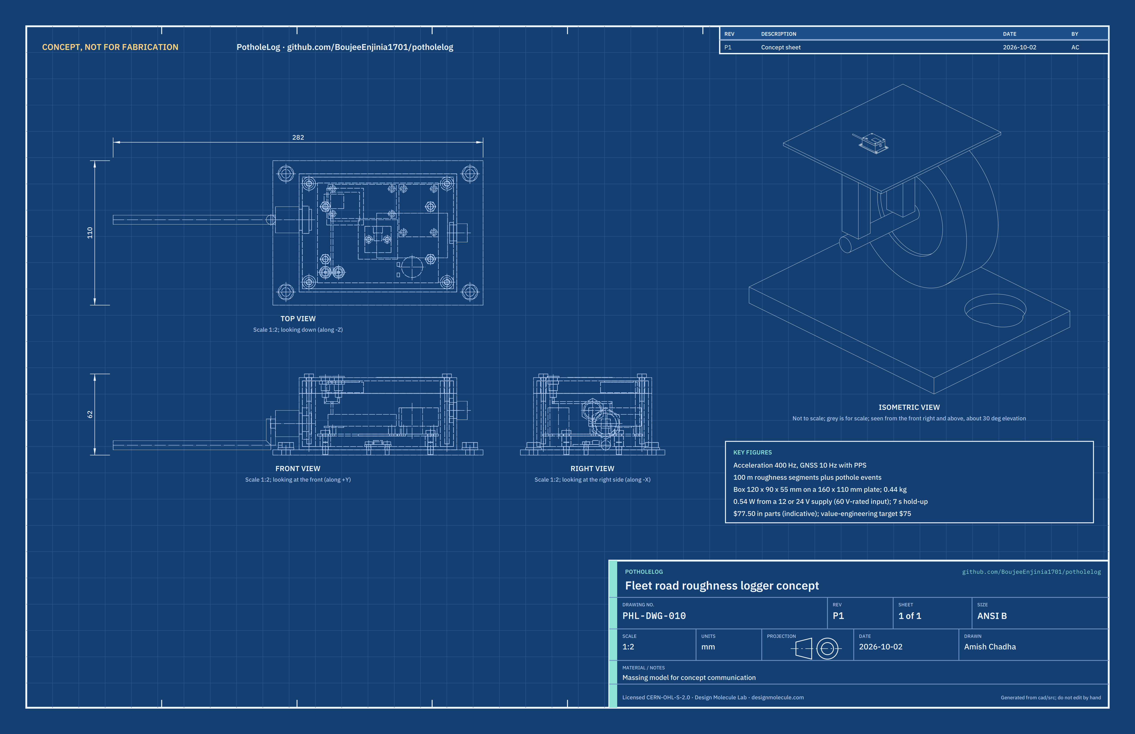
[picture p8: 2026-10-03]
media/concept-blueprint.png

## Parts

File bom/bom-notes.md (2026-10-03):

# BOM notes

- Items 1 to 16 match the numbered callouts in `media/exploded.png` and the parts in `cad/src/model.py`. The microSD card (10) sits in the controller's slot and the fixings (11) are shown as bolt heads and washers.
- Every line is priced. Prices are indicative single-unit USD prices for concept costing, not quotes. Supplier types are given where no single supplier is preferred.
- Total: $77.50 over 16 lines against the $75 value-engineering target (`budget_usd` in `project.yaml`, unchanged), $2.50 over (PHL-CAL-001 v0.5, J1). The budget was raised from $70 under PHL-DDR-002 (N1); the carrier plate and box fixing kit (lines 12 and 13) were added for construction (PHL-DDR-003) and lines 14 to 16 for the decisions of 2026-10-02.
- PHL-CAL-001 v0.1 (F4, F5) showed that a 36 V converter input is exceeded by a suppressed load dump on 24 V vehicles. Item 4 is now a 60 V-rated converter, about $2 more ($7.00 to $9.00), decided by Amish on 2026-09-25 (PHL-DDR-002, N1). The TVS pulse energy during a load dump still needs a bench test (TRL 4, on hold).
- The depot Wi-Fi version is costed. A cellular option (LTE-M module and antenna, about $20 to $30 more, plus a data plan) is an optional add-on, costed separately and not included.
- The controller, IMU and GNSS choices were decided by Amish on 2026-09-25 (PHL-DDR-001, D4 and D5).
- Decisions of 2026-10-02 (PHL-DEC-001), carried into the BOM the same day: line 14, two sealed status light pipes with their 5 mm LEDs and a plug lead to the controller ($1.00); line 15, an M12 pressure-equalizing breather vent in the front end wall ($2.00, low end of the $2 to $3 range for screw-in membrane vents); line 16, a laminated nameplate label with a forward arrow ($0.50). Prices are indicative distributor single-unit prices for each class of part, not quotes. Together they take the estimate $3.50 higher, to $2.50 over the target. The lid stays opaque (line 3; the clear window is shown in the product renders only) and is drilled for the light pipes (PHL-DWG-104). The floor holes are sealed with neutral-cure silicone and the GNSS module held with acrylic foam tape (line 13).
- Mass: logger 0.44 kg, 0.58 kg with the 2 m lead and fixings (PHL-CAL-001 v0.5, H2); lines 14 to 16 add about 8 g.

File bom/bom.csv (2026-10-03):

item | qty | spec | supplier | unit_cost_usd | make_buy | notes
1 Mounting plate | 1 | 160 x 110 x 4 mm aluminium 5052; 4 x 6.6 mm holes on 140 x 90 mm; 4 x M4 tapped holes on 80 x 40 mm (box standoffs); 2 x M3 tapped holes 14 mm apart (IMU); deburred | Metal supplier or offcut (local metal stockist) | 6.00 | make | Indicative price; material and cutting; first mode about 186 Hz on corner bolts (PHL-CAL-001 I1); hole pattern revised for construction (PHL-DDR-003)
2 Enclosure base | 1 | Stock IP65 polycarbonate or ABS box, 120 x 90 x 55 mm overall with lid, gasket, four corner lid-screw pillars and lid screws; flat floor; drilled 4 x 4.5 mm and 2 x 3.5 mm in the floor, 16.2 mm in the rear end wall and 12.2 mm in the front end wall | Electronics distributor (enclosure range) | 8.00 | buy | Indicative price; includes lid (item 3); drilling per PHL-DWG-102
3 Enclosure lid with gasket | 1 | Supplied with item 2; opaque; drilled 2 x 6.4 mm for the light pipes | Electronics distributor (enclosure range) | 0.00 | buy | Included with item 2; drilling per PHL-DWG-104
4 DC-DC converter and protection | 1 | 9 to 60 V in (60 V rated), 5 V 1 A buck module about 30 x 40 mm with four mounting holes; SMBJ36A-class TVS diode; reverse-polarity diode | Electronics distributor or module marketplace | 9.00 | buy | Indicative price; 60 V input clears the 24 V suppressed load dump (58 V) and the TVS clamp (58.1 V) per PHL-DDR-002 (N1); TVS pulse energy to confirm by bench test (TRL 4 on hold)
5 Hold-up supercapacitor | 1 | 1 F 5.5 V radial, about 16 mm diameter and 20 mm tall, rated to 70 degC or more, with 10 ohm charge resistor, bypass diode and a Schottky blocking diode | Electronics distributor | 3.00 | buy | Indicative price; about 7 s hold-up at end of life (PHL-CAL-001 G1)
6 Controller | 1 | ESP32-S3 board with Wi-Fi and microSD slot; module variant rated to 85 degC | Electronics distributor | 10.00 | buy | Indicative price; decided by Amish 2026-09-25 (PHL-DDR-001 D4)
7 6-axis IMU breakout | 1 | LSM6DSO class, +/-16 g, 416 Hz, about 100 ug/rtHz, I2C or SPI; breakout about 20 x 20 mm with two mounting holes and a side-entry connector | Electronics distributor | 6.00 | buy | Indicative price; decided by Amish 2026-09-25 (PHL-DDR-001 D5); datasheet figures to confirm
8 GNSS module with patch antenna | 1 | u-blox M10 class, multi-constellation, 10 Hz, PPS output, patch antenna on top, module about 28 x 28 mm, with a plug-in lead | Electronics distributor or module marketplace | 15.00 | buy | Indicative price; PPS used to time-stamp IMU samples (PHL-CAL-001 D2)
9 Cable gland and fused lead | 1 | M16 IP68 gland, 2 m two-core lead, inline 2 A blade fuse holder, fuse tap, ring terminals | Auto parts store or electronics distributor | 5.00 | buy | Indicative price
10 microSD card | 1 | 32 GB high-endurance, rated -25 to 85 degC | Electronics retailer | 6.00 | buy | Indicative price; about 133 to 160 days of raw data (PHL-CAL-001 E2)
11 Hardware and consumables | 1 | 4 x M6 x 20 bolts (8.8) with locking nuts and washers; hook-up wire 0.5 and 0.25 mm2; two resistors for the supply-sense divider; heat shrink; cable ties | Hardware store | 2.50 | buy | Indicative price; box fixing hardware moved to item 13 (PHL-DDR-003)
12 Module carrier plate | 1 | 92 x 76 x 1.5 mm aluminium 5052 with a 30 x 30 mm window over the IMU, 4 x 4.5 mm holes on 80 x 40 mm, M3 holes to suit the modules, two tie slots | Metal supplier or offcut (local metal stockist) | 2.00 | make | Indicative price; added for construction (PHL-DDR-003); carries the converter, supercapacitor and controller above the IMU
13 Box fixing kit | 1 | 4 x M4 male-female hex standoffs 7 mm across flats, 8 mm body, 6 mm male thread; 4 x M4 x 6 pan-head screws; 2 x M3 x 8 pan-head screws; 8 x M3 nylon standoffs 6 mm with screws; acrylic foam tape pad 22 x 22 mm; neutral-cure silicone sealant | Hardware store or electronics distributor | 1.50 | buy | Indicative price; added for construction (PHL-DDR-003)
14 Status light pipes and LEDs | 1 | 2 x sealed panel-mount light pipes for a 6.4 mm hole, 9 mm flange, O-ring and inside nut, about 10 mm long with a rear socket for a 5 mm LED; 2 x 5 mm LEDs (green for power, blue-green for logging) with series resistors; 2-pin plug lead to the controller | Electronics distributor | 1.00 | buy | Indicative price: light pipes about $0.30 each, LEDs and resistors about $0.10 each, plug lead about $0.20 at distributor single-unit prices; adopted by Amish 2026-10-02 (PHL-DEC-001, decision 3)
15 Breather vent | 1 | M12 x 1.5 pressure-equalizing vent with ePTFE membrane, IP67 or better, screw-in with O-ring and locknut; 12.2 mm hole in the front end wall | Electronics distributor (enclosure accessories) | 2.00 | buy | Indicative price: low end of the $2 to $3 range for screw-in membrane vents at distributor single-unit prices; adopted by Amish 2026-10-02 (PHL-DEC-001, decision 4)
16 Nameplate label | 1 | 54 x 34 mm printed polyester label, laminated, outdoor-rated adhesive; name, forward arrow and contact line | Label printer or print shop | 0.50 | buy | Indicative price: one label from a short run of laminated polyester labels; adopted by Amish 2026-10-02 (PHL-DEC-001)

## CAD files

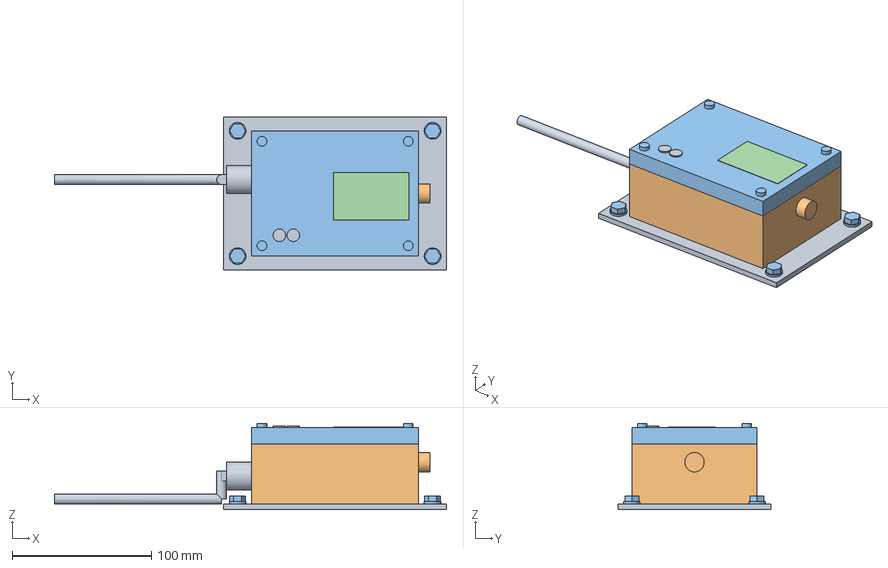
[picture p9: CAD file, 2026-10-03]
cad/step/potholelog-assembly.step
281.5 x 110.0 x 61.8 mm

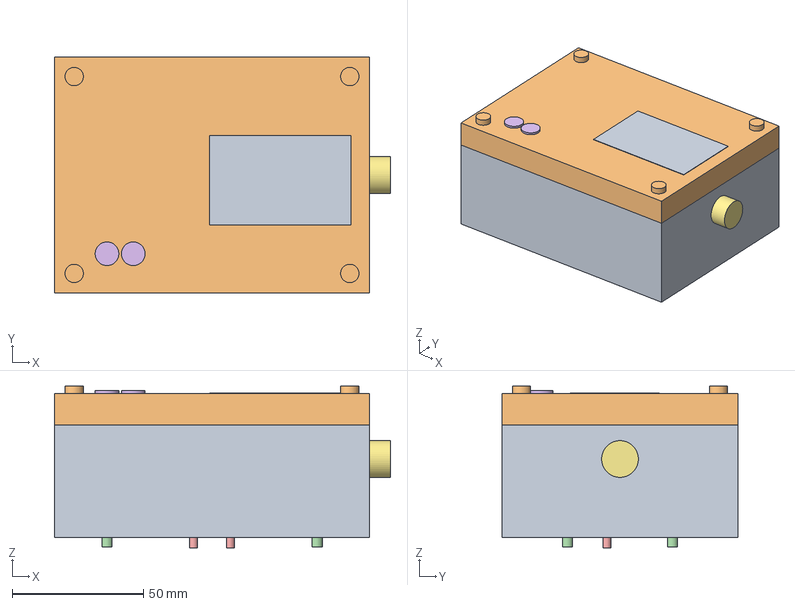
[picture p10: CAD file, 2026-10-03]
cad/step/enclosure.step
128.0 x 90.0 x 61.7 mm

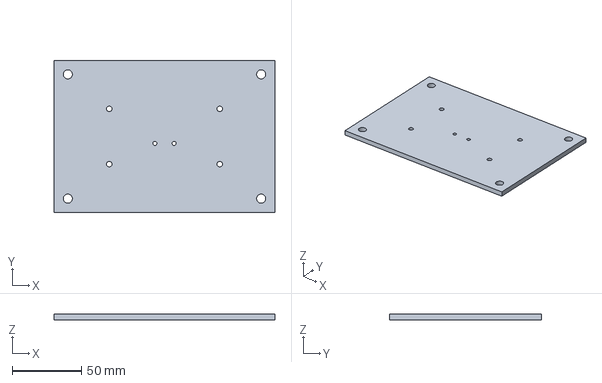
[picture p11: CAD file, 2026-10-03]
cad/step/mounting-plate.step
160.0 x 110.0 x 4.00 mm

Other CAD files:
cad/stl/enclosure.stl
cad/stl/mounting-plate.stl
cad/stl/potholelog-assembly.stl

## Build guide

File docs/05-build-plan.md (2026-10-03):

---
doc_id: PHL-BLD-001
title: PotholeLog prototype build plan
project: PotholeLog
doc_type: Build plan
version: "0.3"
status: Draft
date: '2026-10-02'
author: Amish Chadha
license: CERN-OHL-S-2.0
revisions:
  - version: "0.1"
    date: '2026-10-01'
    author: Amish Chadha
    change: First build plan; design made constructable (PHL-DDR-003)
  - version: "0.2"
    date: '2026-10-02'
    author: Amish Chadha
    change: "Section 2: the changes recorded in PHL-DDR-003 accepted by Amish on 2026-10-02"
  - version: "0.3"
    date: '2026-10-02'
    author: Amish Chadha
    change: "Status light pipes and LEDs, breather vent and nameplate label (decisions of 2026-10-02) added: lid drilling sketch PHL-DWG-104, joints 7 and 8, new step 7, wiring, bought parts and first checks; pictures regenerated"
---

# PotholeLog prototype build plan

**Plan, not yet built.** How to build the first proof-of-concept prototype, component by component. Building and testing to it is TRL 4 work. Decisions still to be made are kept in the design decisions register ([docs/06-design-decisions.md](06-design-decisions.md)), not here.

## 1. What you are building

Figure 1. Every component, pulled apart and numbered in build order

*Figure 1. Every component pulled apart and numbered in build order.*

The prototype is one PotholeLog on a bench board that stands in for the vehicle floor: a grey plastic box, 120 x 90 x 55 mm, on a 4 mm aluminium plate that bolts down at its four corners. Inside, a small motion sensor (the IMU) is screwed through the box floor into the plate, so it feels exactly what the plate feels, and an aluminium carrier plate above it holds the power converter, the hold-up capacitor and the controller. The position module (GNSS) sits under the plastic lid, where it sees the sky. Two sealed light pipes in the lid show power and logging, a breather vent in the front end wall lets the box breathe without letting water in, and a nameplate label on the lid carries an arrow that must point forward. Figure 1 shows the 17 components in the order you make or fit them. Three are made in a small workshop: the mounting plate, the carrier plate and the drilling of the bought box and its lid. Everything else is bought and fitted: the box and lid, cable gland, breather vent, hex standoffs, electronic modules, light pipes and their LEDs, memory card, fused lead, label and bolts. The work is sawing, drilling, tapping and filing aluminium sheet, drilling a plastic box, and wiring bought modules together at screw terminals and plugs. The parts cost about $77.50 from the bill of materials.

> **Safety:** The logger runs from a vehicle's 12 V or 24 V supply. On the bench, power it only from a bench supply with a 2 A fuse in the lead and the current limit set to 0.5 A; never from a vehicle until the stops of section 6 are passed. The hold-up capacitor stays charged for a short time after power is removed: do not short its terminals. Cut aluminium edges are sharp; deburr everything. Installing on a vehicle is outside this plan.

## 2. What changed to make it buildable

The concept showed what the logger does; some of its parts overlapped or had no fixing. Each change below keeps what the logger does, and all of them are recorded in decision record PHL-DDR-003, accepted by Amish on 2026-10-02.

*Table 1. Changes from the concept.*

| Component | The concept had | The buildable design has | Why |
| --- | --- | --- | --- |
| Box fixing | Four screws through the box floor, two of them under the converter and all four where a stock box has its corner pillars | Four hex standoffs through the floor into the plate, 80 x 40 mm apart (Figure 6) | Nothing sits on a screw head; the standoffs also carry the carrier plate |
| Modules | Converter and capacitor standing loose on the floor; controller on a support that was not a part | An aluminium carrier plate on the standoffs, with the modules on nylon standoffs and a window over the IMU (Figures 8 and 9) | Bought modules are made to be screwed to a plate |
| Layout inside the box | The capacitor overlapping the controller; the controller touching the end wall where the gland nut goes | Converter turned and moved to the front; every module at least 2 mm from the next and well clear of the gland nut (Figure 3) | Same box, same modules, nothing overlaps |
| Cable gland | Drawn against the outside of the wall, with no hole or nut | A 16.2 mm hole with the gland's seal outside and its locknut inside (Figure 5) | This is how a gland is fitted |
| IMU | Screwed to the plastic floor, with no screws shown | Two M3 screws through the floor into the aluminium plate (Figure 7) | Clamped to the plate the vehicle shakes; still on the floor, on the centre line |
| GNSS module | Floating under the lid | Held by a pad of foam tape under the lid top (Figure 10) | No hole in the lid |
| Lid | Fixing not shown | The box's four corner pillars and lid screws, with every part kept clear of them (Figure 11) | They are on the box that will be bought |

## 3. Making the components

Make and check each component before the assembly step that needs it. Sizes are in millimetres. "Forward" is toward the front of the vehicle, the end of the box without the gland; "left" and "right" are as seen facing forward. Positions are measured from the centre lines of the plate or box. Workshop tolerance is 0.5 mm unless a step says otherwise; drawings do not carry tolerances before TRL 4.

### 3.1 Mounting plate

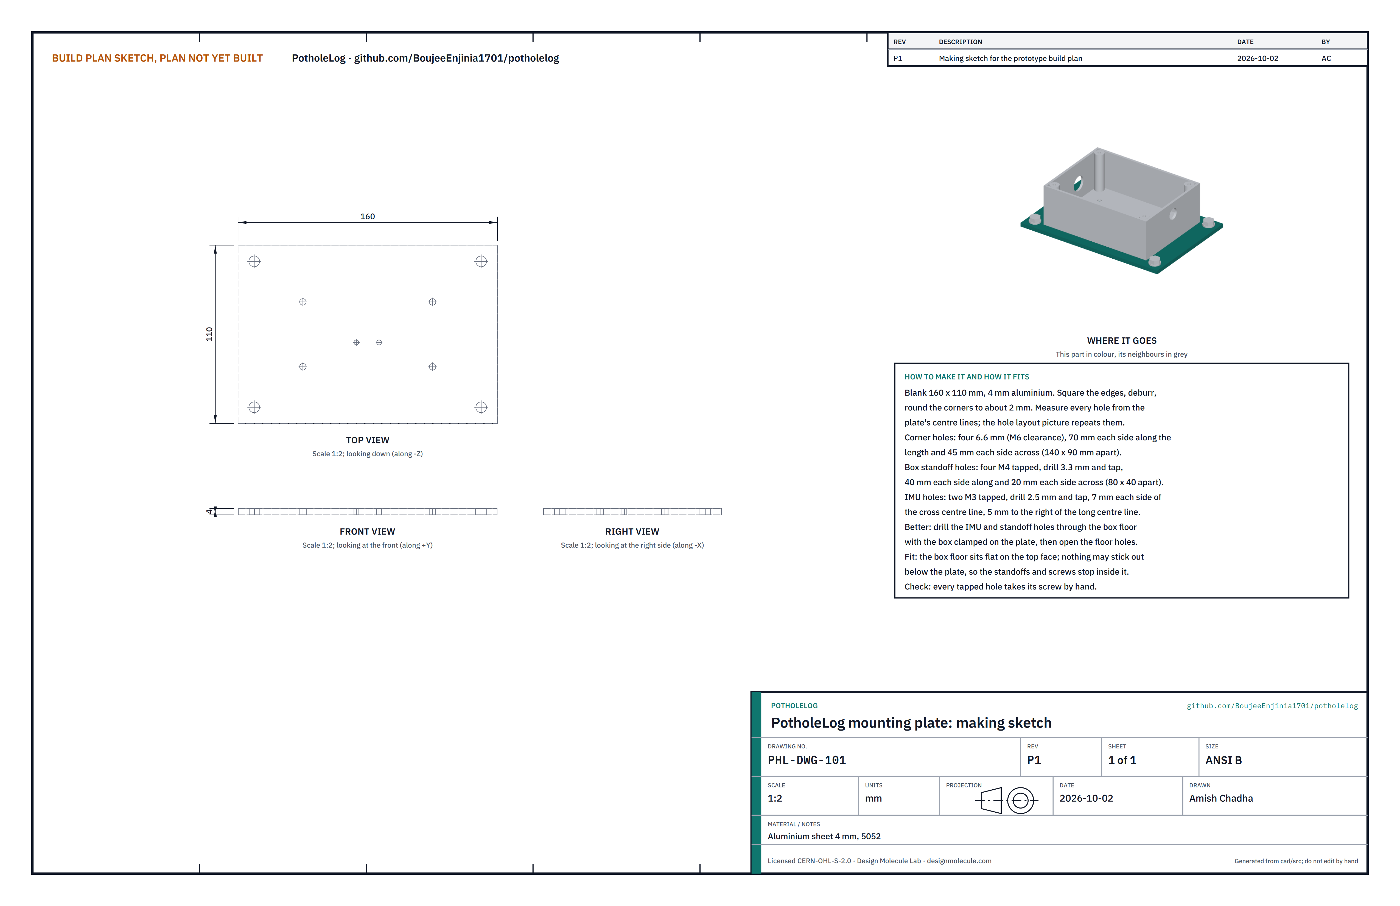
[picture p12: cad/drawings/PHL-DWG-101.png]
Figure 2. Making sketch of the mounting plate


*Figure 2. Mounting plate making sketch (PHL-DWG-101).*

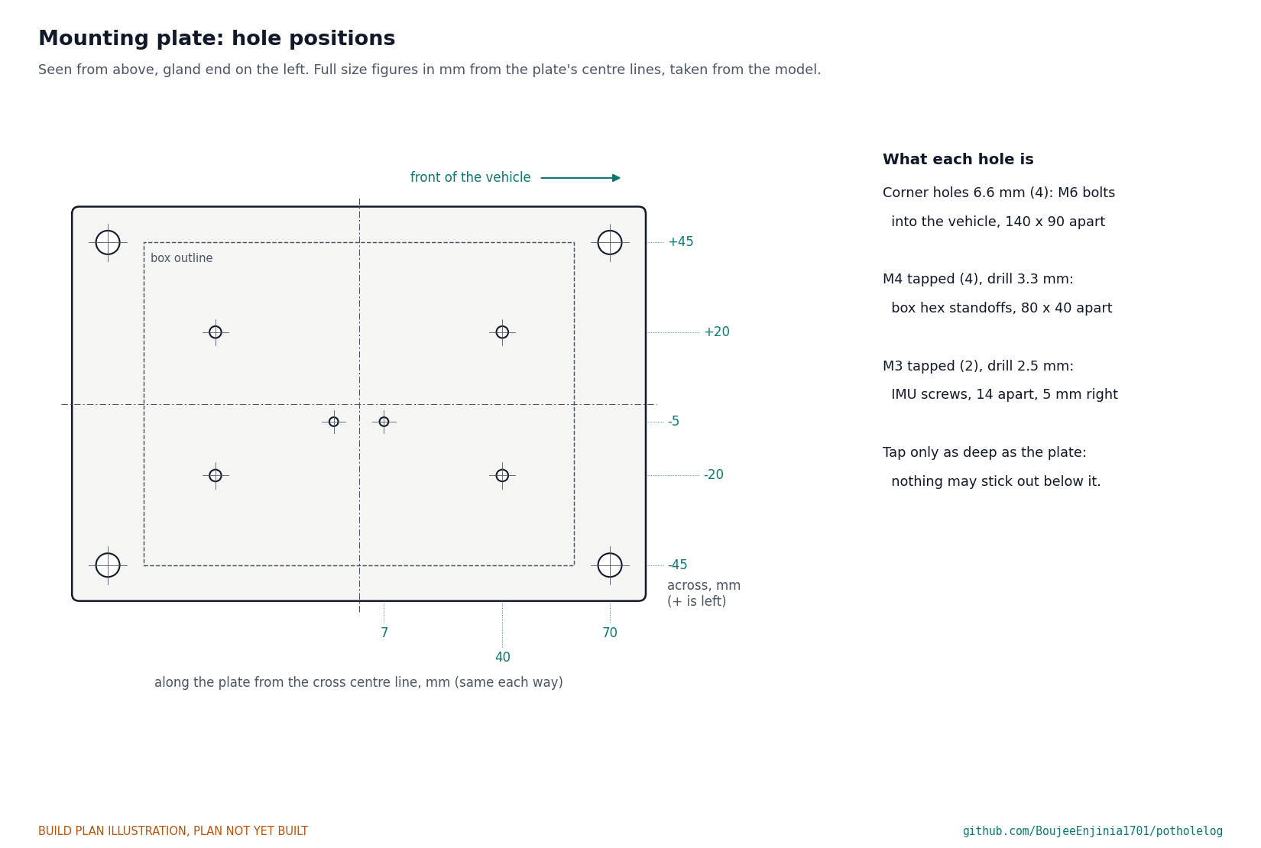
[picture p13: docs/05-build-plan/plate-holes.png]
Figure 2a. Hole positions on the mounting plate


*Figure 2a. Every hole, full size figures, measured from the plate's centre lines.*

**What it is and what it is made from.** The flat plate the whole logger stands on and bolts down by. Aluminium sheet 4 mm thick, 5052 class, cut to 160 x 110 mm.

**How to make it.**

1. Cut the blank to 160 x 110 mm, square. File the edges and round the corners to about 2 mm.
2. Scribe both centre lines on the top face and mark the forward end.
3. Corner holes: four 6.6 mm holes, 70 mm each side of the cross centre line and 45 mm each side of the long centre line (140 x 90 mm apart).
4. Standoff holes: four holes 40 mm each side along and 20 mm each side across (80 x 40 mm apart). Drill 3.3 mm and tap M4 right through.
5. IMU holes: two holes 7 mm each side of the cross centre line, 5 mm to the right of the long centre line. Drill 2.5 mm and tap M3 right through.
6. Deburr every hole on both faces.

**How it fits the parts next to it.** The box floor sits flat on the top face, centred, held by the four standoffs (Figure 6); the IMU screws come down through the floor into the M3 holes (Figure 7). The four corner bolts sit 4 mm outside the box ends (Figure 12). Nothing may stick out below the plate, so it sits flat on the vehicle floor.

**Check before moving on.** Each tapped hole takes its screw by hand, and the plate lies flat on a bench without rocking.

### 3.2 Enclosure base, drilled, with its cable gland

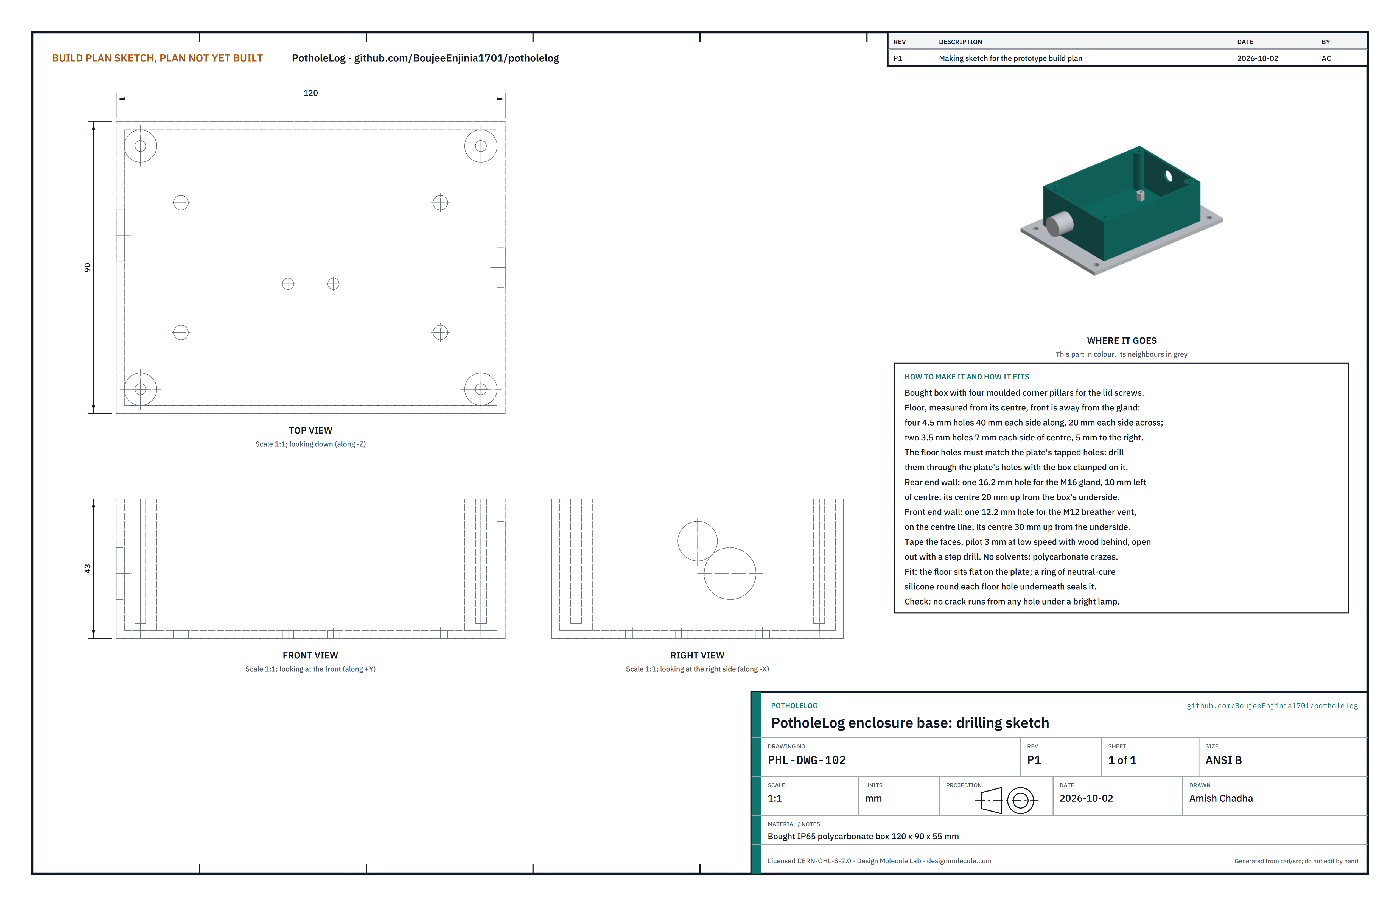
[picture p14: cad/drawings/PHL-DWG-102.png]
Figure 3. Drilling sketch of the enclosure base


*Figure 3. Enclosure base drilling sketch (PHL-DWG-102).*

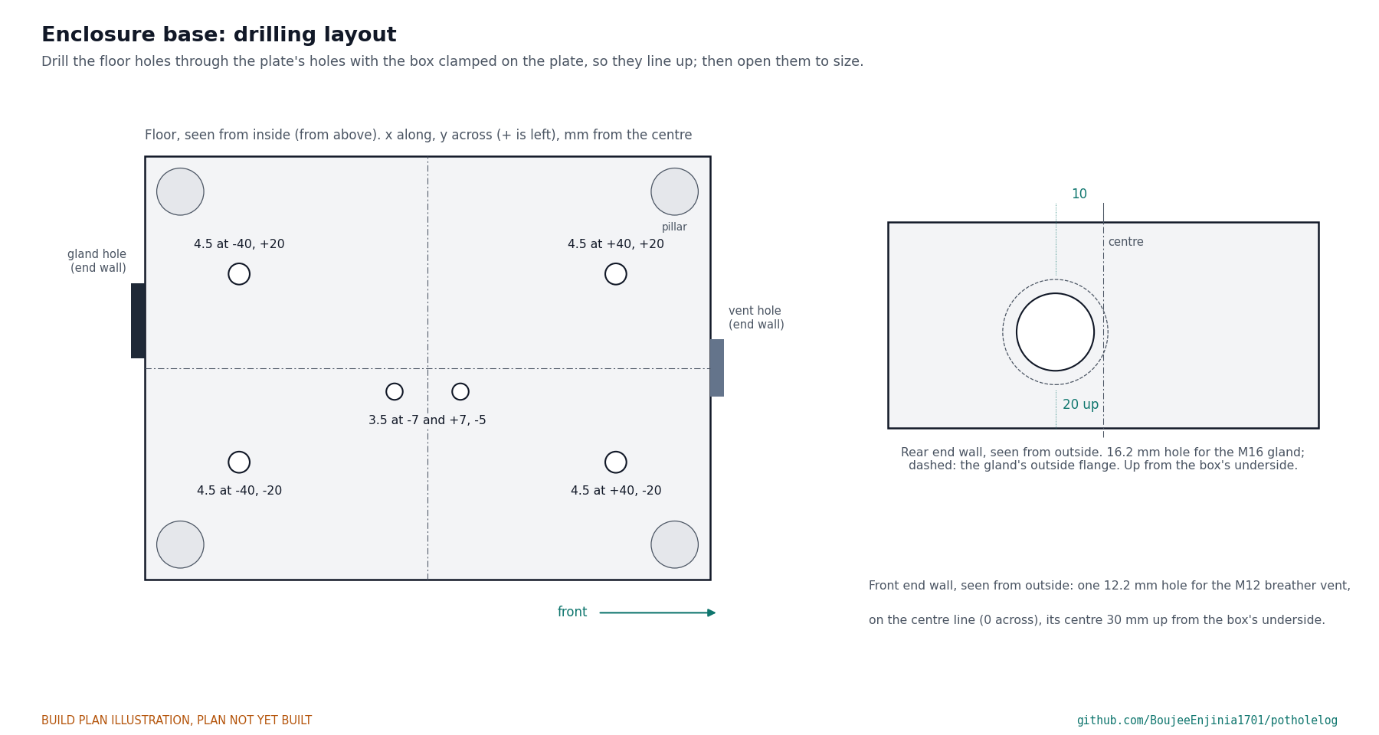
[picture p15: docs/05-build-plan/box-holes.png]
Figure 4. Drilling layout of the floor and the rear end wall


*Figure 4. Floor holes, the gland hole in the rear end wall and the vent hole in the front end wall.*

**What it is and what it is made from.** A bought grey polycarbonate box, 120 x 90 x 55 mm with its lid, rated IP65, with four moulded pillars in its corners for the lid screws. Six holes are drilled in its floor, one in its rear end wall and one in its front end wall.

**How to make it.**

1. Clamp the box, centred and square, on the mounting plate, rear end over the plate's rear end.
2. From inside the box, drill through the plate's four standoff holes and two IMU holes with a 2.5 mm drill, just deep enough to mark the plate's holes through the floor. Unclamp.
3. Open the four standoff holes in the floor to 4.5 mm and the two IMU holes to 3.5 mm with a step drill, at low speed and light pressure, with a block of wood under the floor.
4. Rear end wall: cover it with masking tape, mark a point 10 mm left of the centre and 20 mm up from the box's underside, pilot 3 mm, and open to 16.2 mm with the step drill. Check the size against the gland's datasheet before the last step.
5. Front end wall: tape it, mark a point on the centre line 30 mm up from the box's underside, pilot 3 mm and open to 12.2 mm with the step drill, checking the size against the vent's datasheet.
6. Deburr inside and out. Clean with water and mild soap only; solvents craze polycarbonate.

**How it fits the parts next to it.**

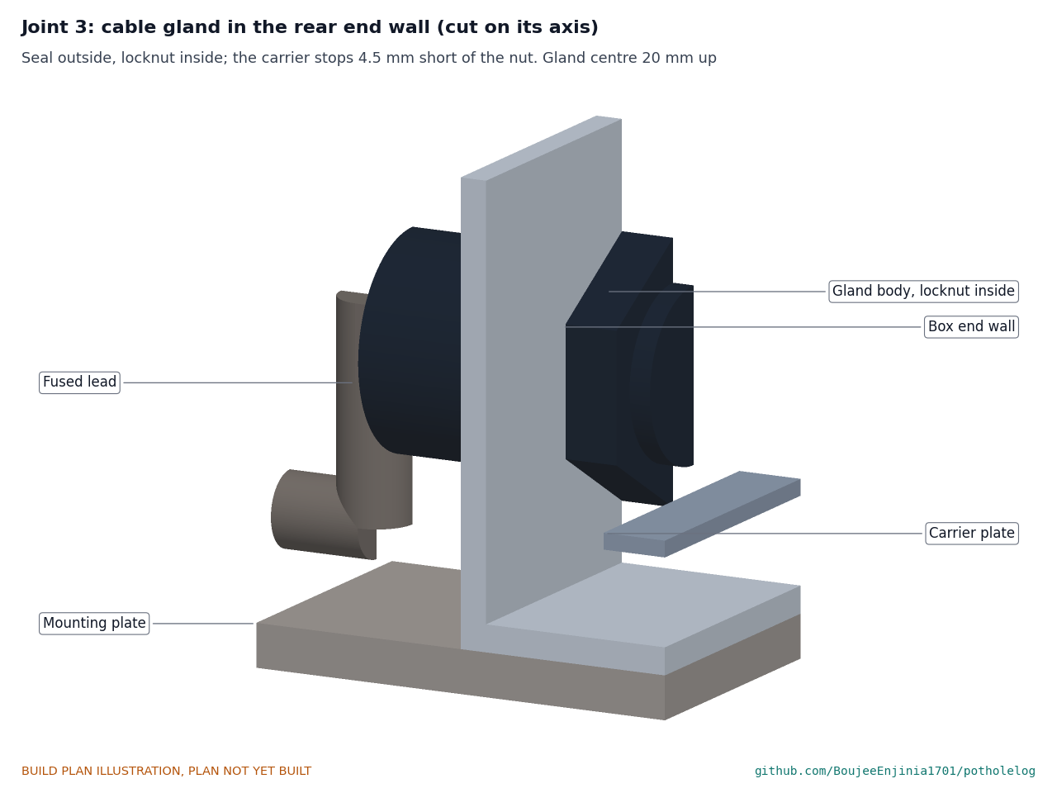
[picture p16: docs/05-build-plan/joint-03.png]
Figure 5. Joint 3: cable gland in the rear end wall


*Figure 5. The gland's body and seal sit outside the wall; its locknut is inside, 4.5 mm clear of the carrier plate.*

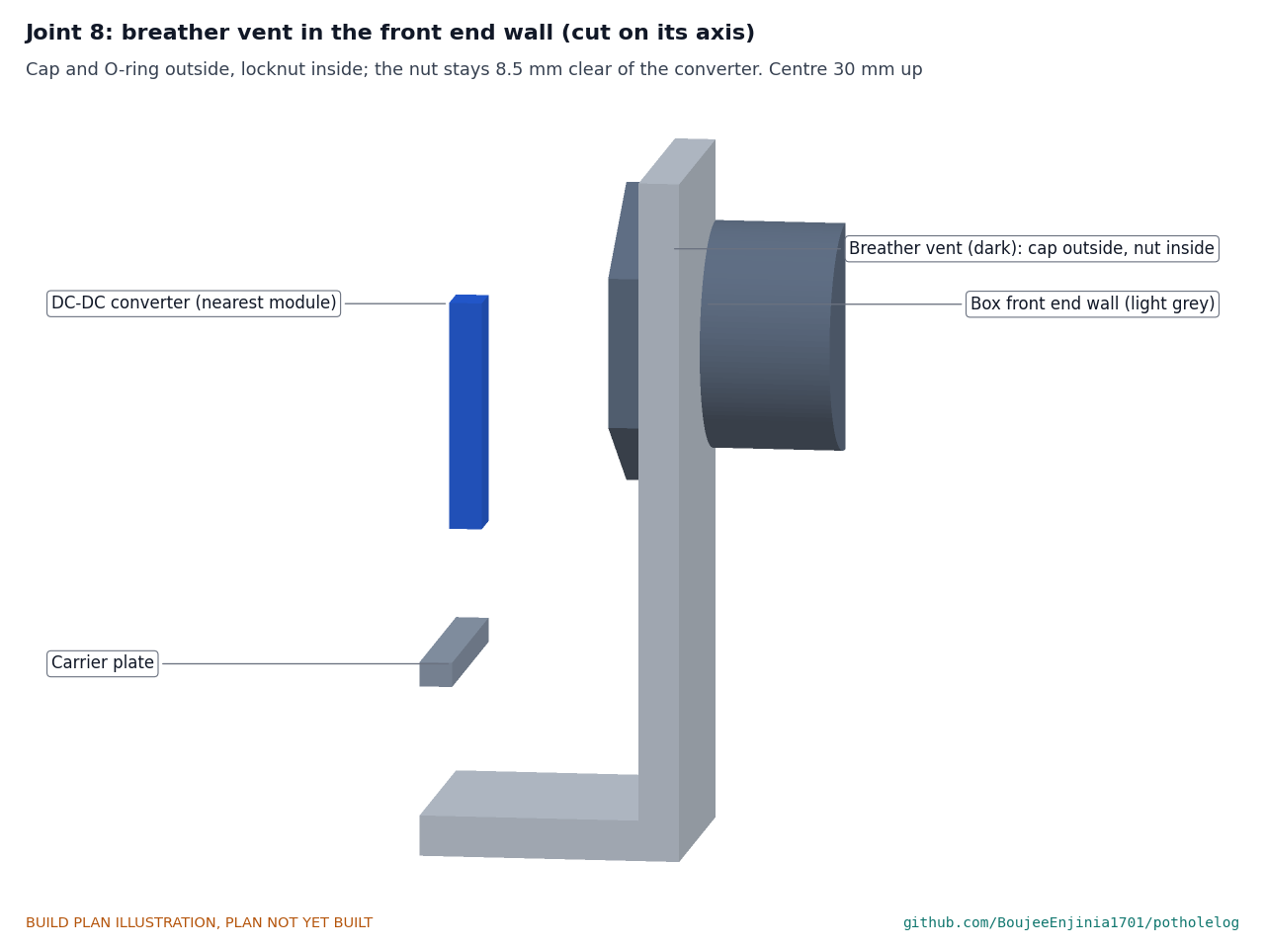
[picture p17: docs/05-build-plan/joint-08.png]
Figure 5a. Joint 8: breather vent in the front end wall


*Figure 5a. The vent's membrane cap and O-ring sit outside the front wall; its locknut is inside, 8.5 mm clear of the converter.*

The gland goes in from outside with its sealing washer against the wall and its locknut inside, and the breather vent goes into the front wall the same way (step 1). The floor sits flat on the plate; a ring of neutral-cure silicone under each floor hole seals it (step 2).

**Check before moving on.** No crack runs out from any hole under a bright lamp; with the box clamped back on the plate, every floor hole lines up with its plate hole.

### 3.3 Hex standoffs (bought, 4)

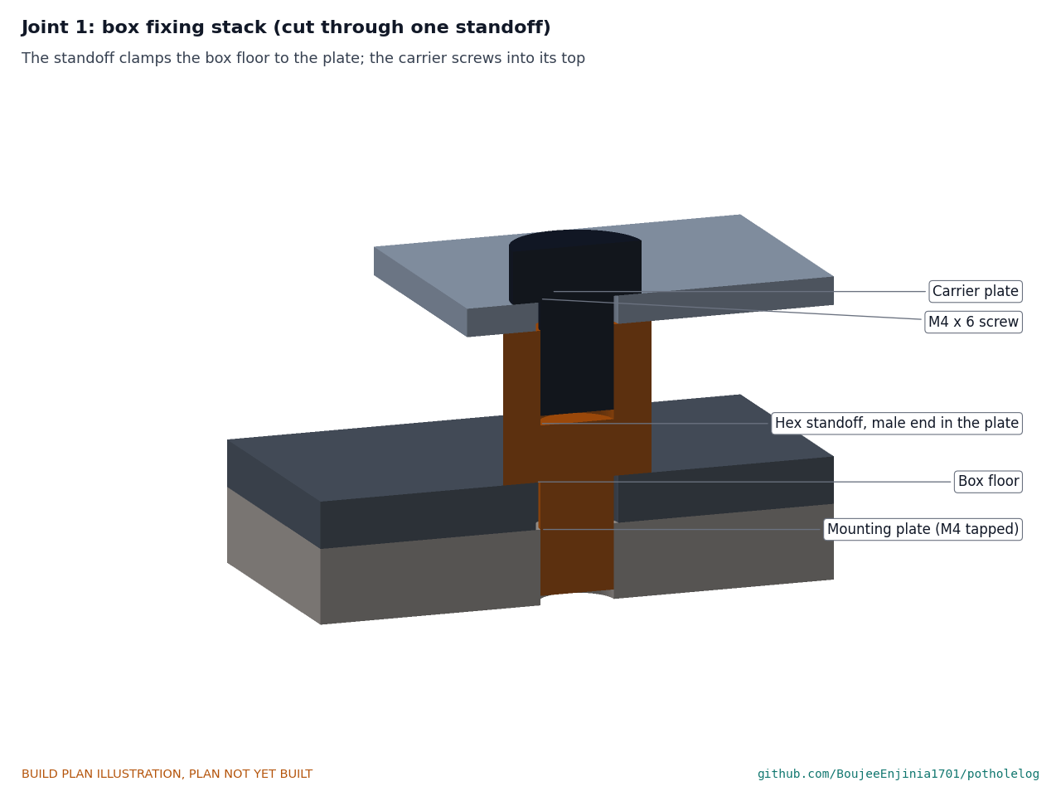
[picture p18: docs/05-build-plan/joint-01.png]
Figure 6. Joint 1: the box fixing stack


*Figure 6. Each standoff's threaded end goes through the box floor into the plate and clamps the floor down; the carrier plate screws onto its top.*

**What to buy and how it fits.** Four M4 male-female hex standoffs, brass or stainless, 7 mm across the flats, 8 mm body and a 6 mm male thread (no longer, or the thread would come out under the plate). The male end goes through the 4.5 mm floor hole into the plate's tapped hole; the body stands on the floor. The carrier plate sits on their tops, 8 mm above the floor, and four M4 x 6 pan-head screws go into their female threads.

**Check before moving on.** All four tops are level within 0.5 mm, checked with a straightedge across them.

### 3.4 IMU (bought)

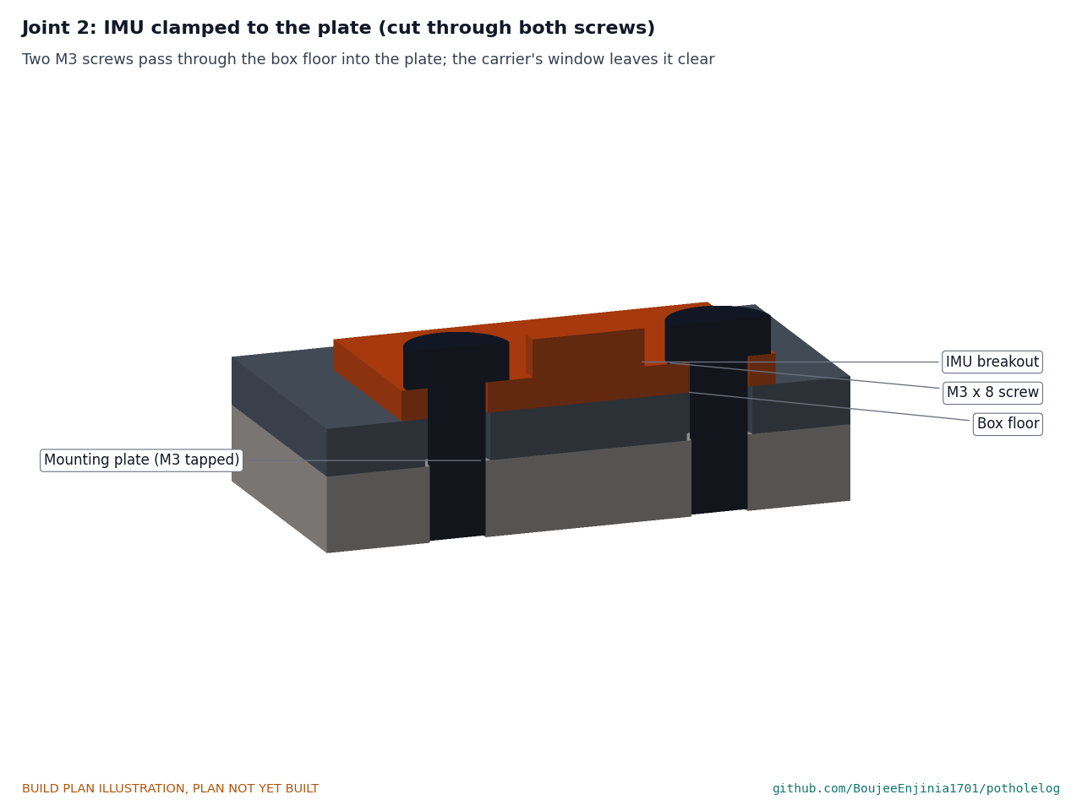
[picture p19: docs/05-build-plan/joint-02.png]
Figure 7. Joint 2: the IMU clamped to the plate


*Figure 7. Two M3 screws pass through the IMU board and the box floor into the plate.*

**What to buy and how it fits.** A 6-axis IMU breakout of the LSM6DSO class, about 20 x 20 mm, with two mounting holes 14 mm apart (or drill the floor and plate to the holes of the board you buy) and a side-entry plug for its lead, so nothing stands more than about 5 mm above the floor. It sits flat on the box floor with the arrow printed for its forward axis pointing forward, held by two M3 x 8 pan-head screws into the plate. Its top stays 3.4 mm below the carrier plate, and the carrier's window gives room for its lead.

**Check before moving on.** The board does not rock; the screw tips do not show under the plate.

### 3.5 Module carrier plate and the modules on it

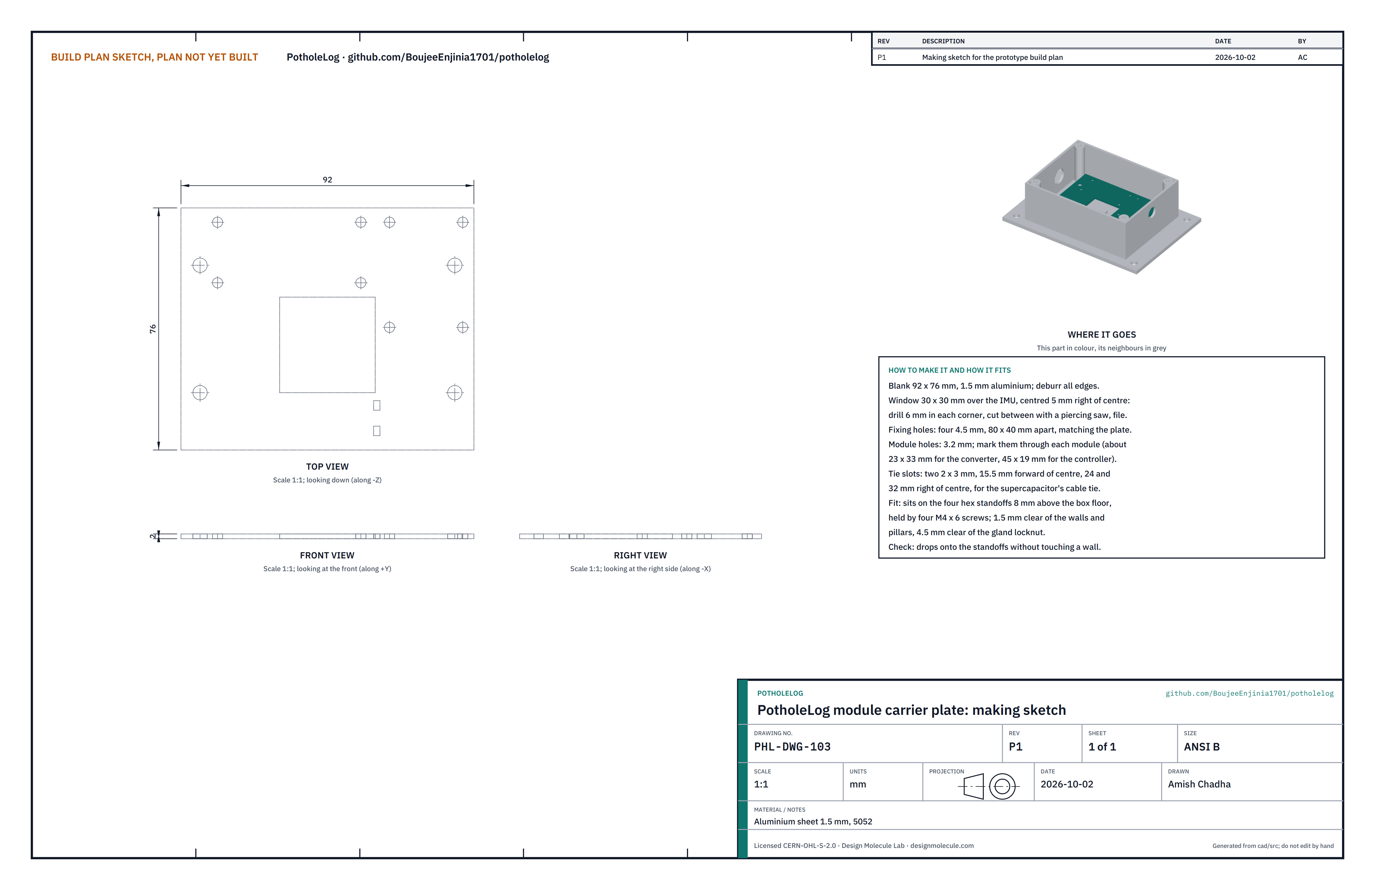
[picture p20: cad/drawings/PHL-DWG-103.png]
Figure 8. Making sketch of the carrier plate


*Figure 8. Module carrier plate making sketch (PHL-DWG-103).*

**What it is and what it is made from.** A thin plate that carries the converter, the hold-up capacitor and the controller above the IMU. Aluminium sheet 1.5 mm thick, 5052 class, cut to 92 x 76 mm.

**How to make it.**

1. Cut the blank to 92 x 76 mm; deburr every edge.
2. Fixing holes: four 4.5 mm holes, 80 x 40 mm apart, matching the plate. Best: clamp the carrier on the plate and drill through the plate's standoff holes, then open to 4.5 mm.
3. Window: 30 x 30 mm, centred 5 mm right of the centre. Drill a 6 mm hole in each corner, cut between them with a piercing saw or nibbler, and file the edges straight.
4. Lay the converter (front left) and the controller (rear left) on the plate as Figure 9 shows, mark each module's mounting holes through the module, and drill them 3.2 mm. For the expected modules they are about 23 x 33 mm apart for the converter and 45 x 19 mm for the controller.
5. Tie slots: two 2 x 3 mm slots, 15.5 mm forward of centre, 24 and 32 mm right of centre, beside where the capacitor stands. Drill 2 mm and file.

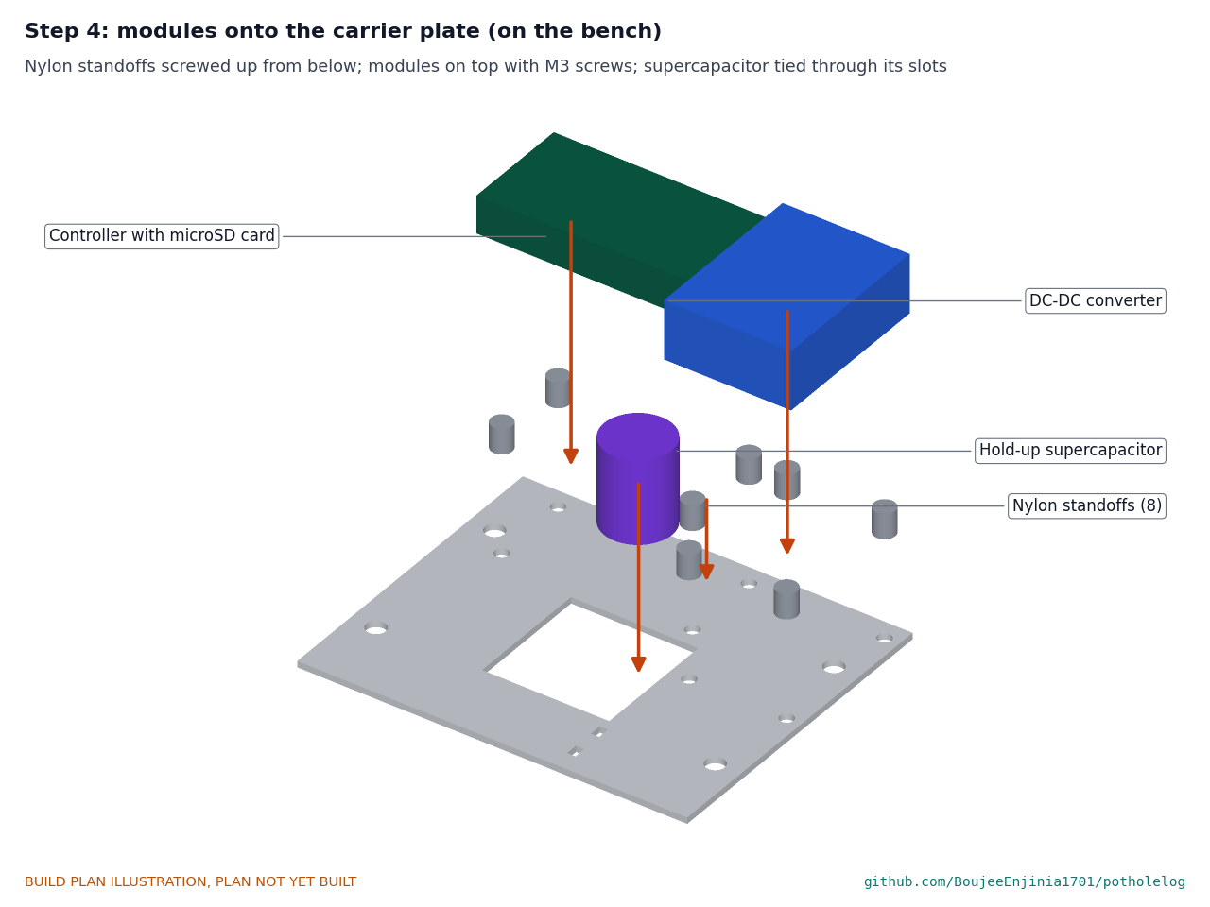
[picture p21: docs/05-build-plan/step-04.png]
Figure 9. Step 4 picture: modules on the carrier plate


*Figure 9. Where each module goes on the carrier.*

**How it fits the parts next to it.** The carrier sits on the four hex standoffs (Figure 6), 1.5 mm clear of the box walls and corner pillars and 4.5 mm clear of the gland locknut (Figure 5). Each module stands on four 6 mm M3 nylon standoffs, screwed up through the carrier from below; the modules are screwed down onto them with M3 screws. The capacitor stands on the carrier and is held by a cable tie through the two slots.

**Check before moving on.** The carrier drops onto the standoffs without touching a wall or pillar, and nothing on it touches the next part.

#### 3.5.1 Wiring

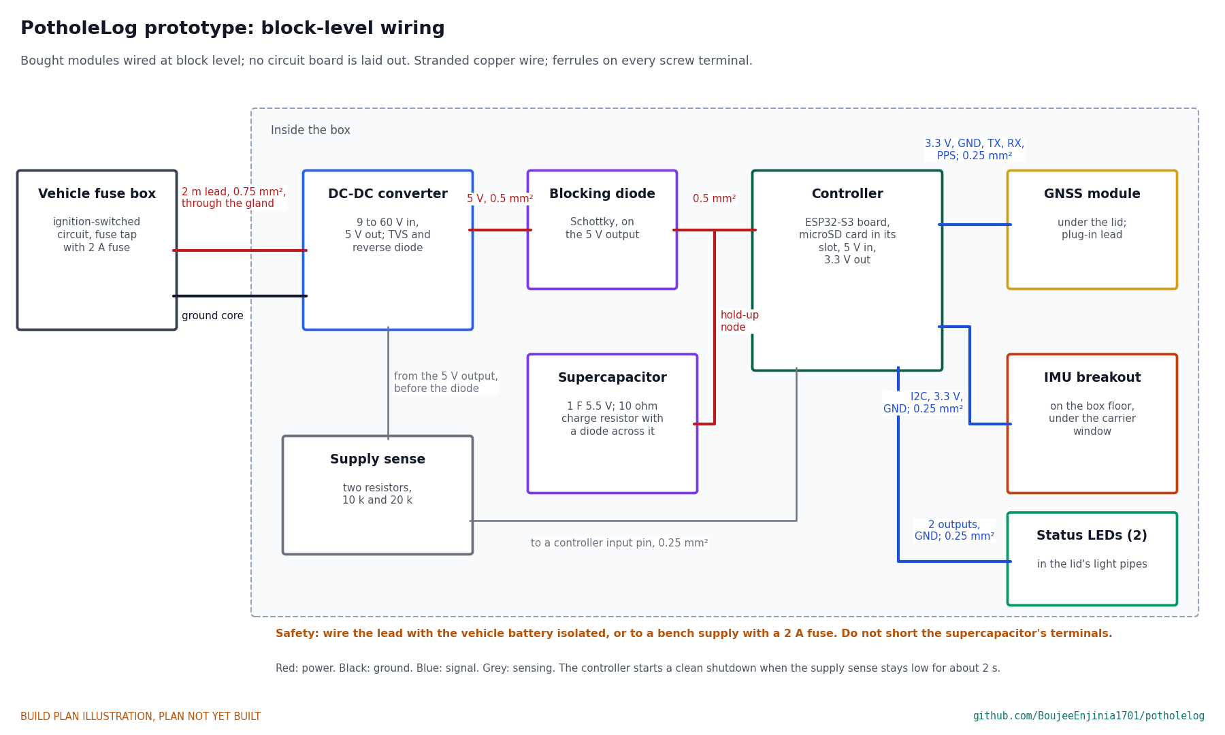
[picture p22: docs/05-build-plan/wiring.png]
Figure 9a. Block-level wiring


*Figure 9a. Block-level wiring with wire sizes. No circuit board is laid out; bought modules are wired together.*

Wire it like this, with stranded copper and a ferrule on every screw terminal:

1. The fused lead's live core to the converter's input terminal, its ground core to the converter's ground: 0.75 mm² (18 AWG), the lead's own cores.
2. Converter 5 V output to the blocking diode, and the diode to the controller's 5 V pin: 0.5 mm² (20 AWG).
3. The capacitor to the controller's 5 V pin through its 10 ohm resistor, with the bypass diode across the resistor so the capacitor can feed the controller when power drops: 0.5 mm².
4. Supply sense: a 10 k and a 20 k resistor in series from the converter's 5 V output (before the blocking diode) to ground; the joint between them to a controller input pin: 0.25 mm² (24 AWG).
5. IMU to the controller's 3.3 V, ground and I2C pins with its plug-in lead, up through the carrier window: 0.25 mm².
6. GNSS plug-in lead (3.3 V, ground, transmit, receive and the timing pulse) to the controller, long enough to set the lid down beside the box: 0.25 mm².
7. Status lights: each LED has its series resistor soldered in one leg and sleeved; both LEDs share a ground. Their plug lead goes to two controller output pins and ground, long enough to set the lid down beside the box: 0.25 mm².
8. Put the microSD card in the controller's slot.

**Check before moving on.** Every wire continues end to end; with no power connected, the converter input reads open between live and ground; every wire is labelled.

### 3.6 GNSS module (bought)

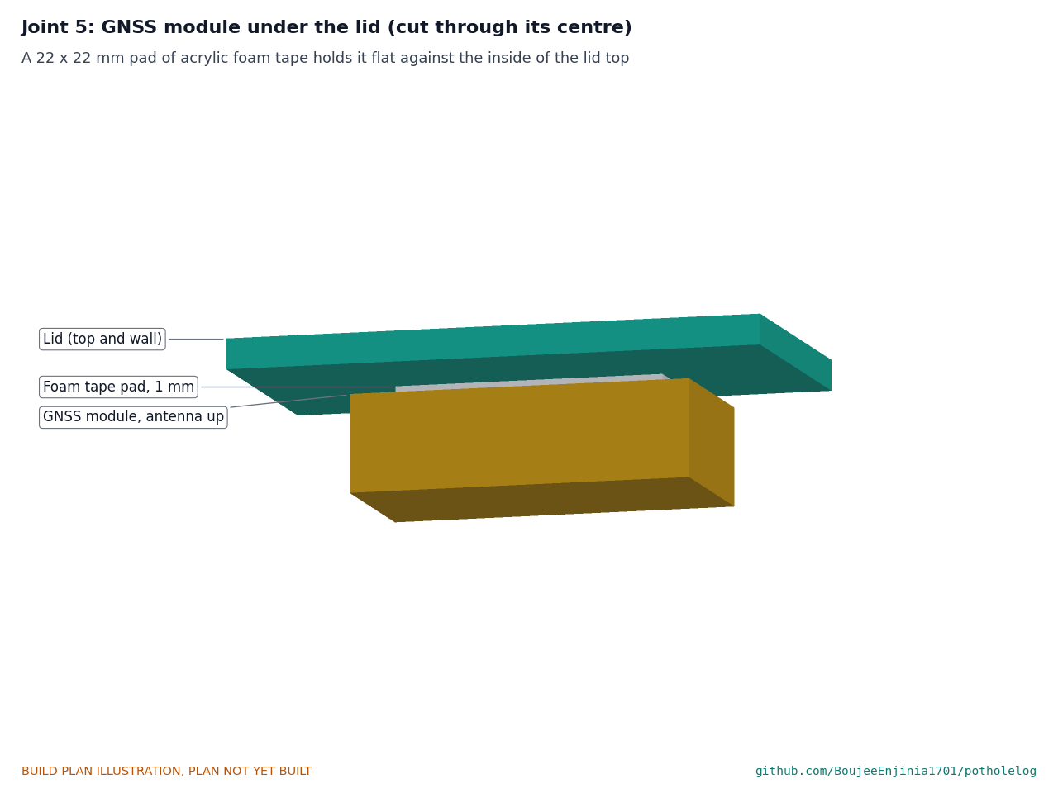
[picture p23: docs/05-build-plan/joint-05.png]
Figure 10. Joint 5: GNSS module under the lid


*Figure 10. A 22 x 22 mm pad of foam tape holds the module flat under the lid top.*

**What to buy and how it fits.** A u-blox M10 class GNSS module, no larger than 28 x 28 mm, with its patch antenna on top, a timing-pulse output and a plug-in lead. It goes under the lid top, 25 mm toward the rear and 20 mm left of the centre, above the controller, held by a 22 x 22 mm pad of 1 mm acrylic foam tape (step 8). Keep metal, labels and the lid screws away from the area above the antenna.

**Check before moving on.** The module does not move when pushed sideways with a finger.

### 3.7 Lid, lid screws and the box's corner pillars

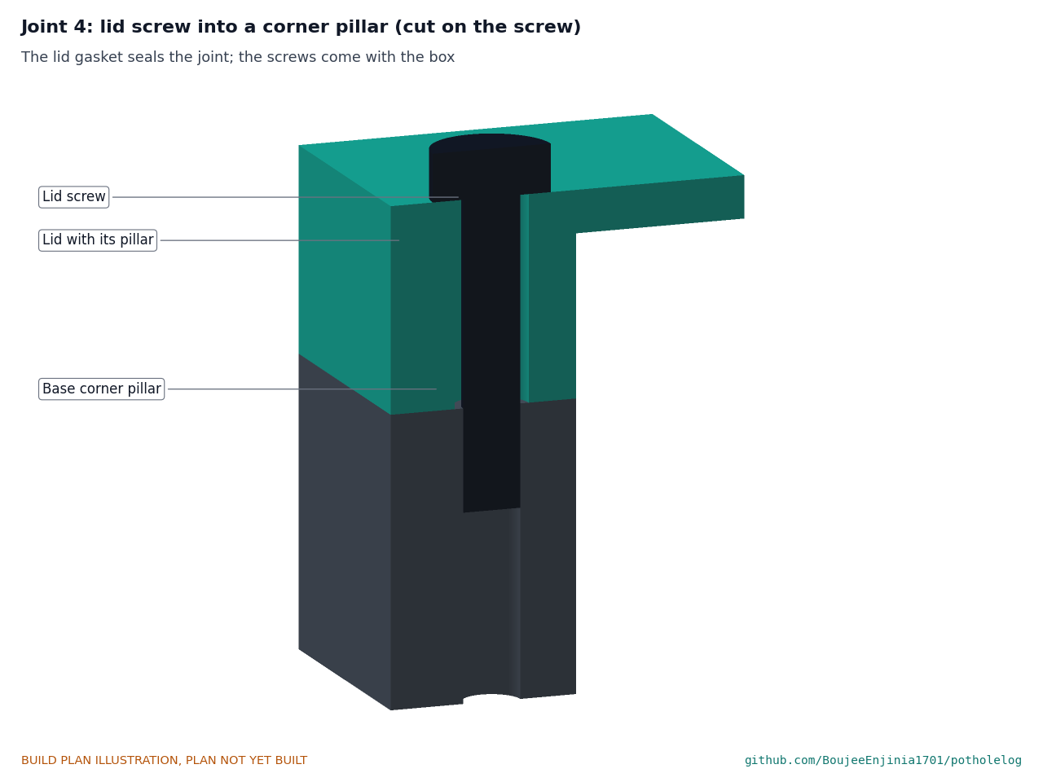
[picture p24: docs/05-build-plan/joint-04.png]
Figure 11. Joint 4: lid screw into a corner pillar


*Figure 11. Each lid screw passes through the lid's pillar into the base's pillar; the gasket in the lid seals the joint.*

**What to buy and how it fits.** The lid, gasket and four lid screws come with the box. The lid sits on the base's rim with its gasket between them; the four screws go into the moulded corner pillars. The modules stay clear of the pillars by 1.5 mm or more.

**Check before moving on.** The gasket sits in its groove all the way round, with no wire across it.

### 3.8 Lid drilling, status light pipes and nameplate label

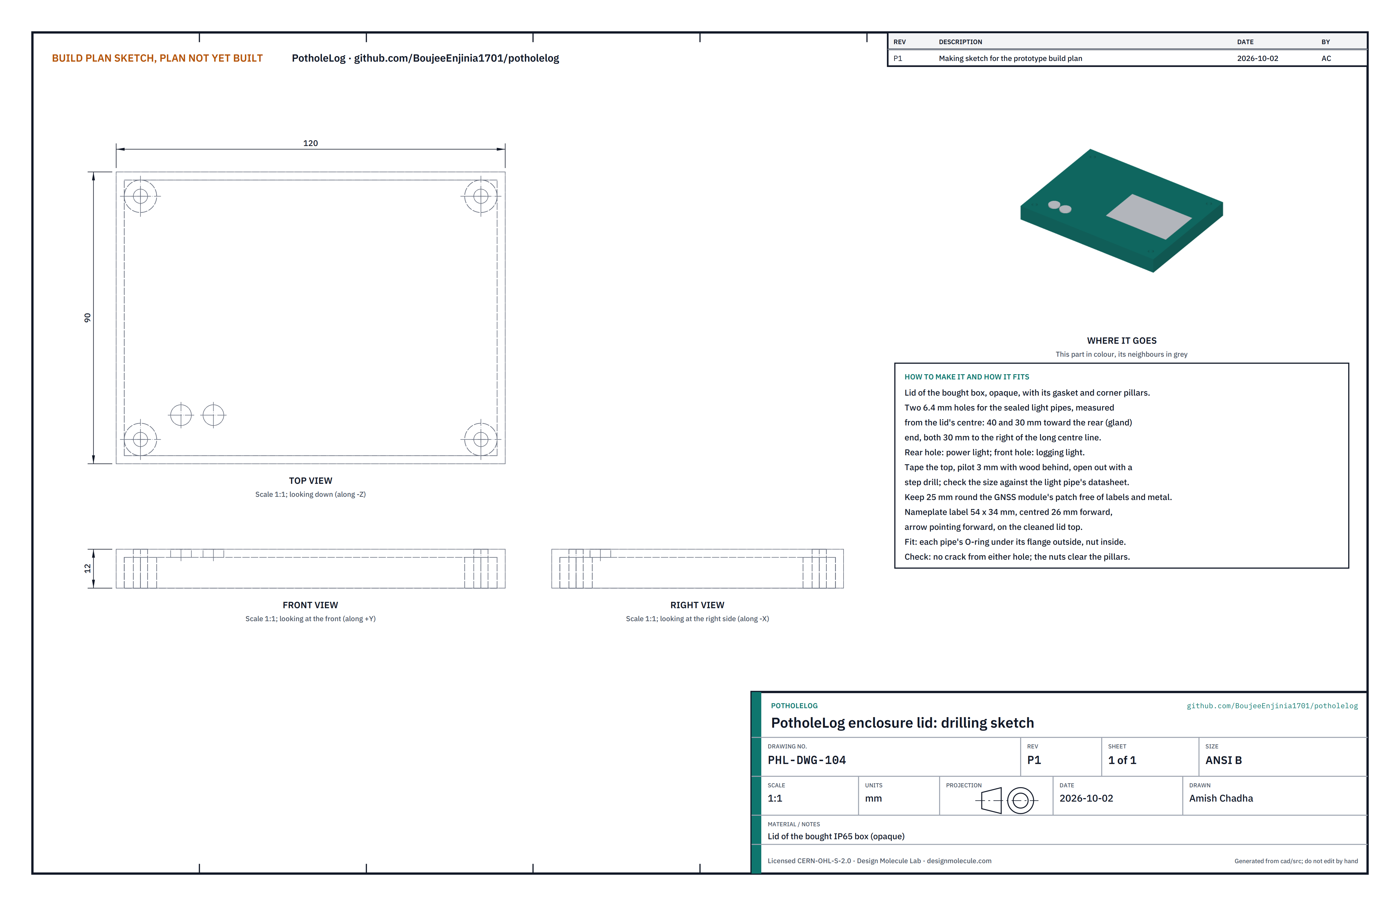
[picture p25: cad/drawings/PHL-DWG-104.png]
Figure 11a. Drilling sketch of the lid


*Figure 11a. Lid drilling sketch (PHL-DWG-104).*

**What it is and what it is made from.** The bought box's opaque lid, drilled with two holes for sealed light pipes, and a printed label stuck on its top.

**How to make it.**

1. Cover the lid top with masking tape and mark both centre lines.
2. Mark two points 30 mm to the right of the long centre line, one 40 mm and one 30 mm toward the rear (gland) end from the cross centre line. The rear one is the power light, the front one the logging light.
3. Pilot 3 mm with a block of wood under the lid, then open both holes to 6.4 mm with the step drill, checking the size against the light pipe's datasheet.
4. Deburr, and clean with water and mild soap only.

**How it fits the parts next to it.**

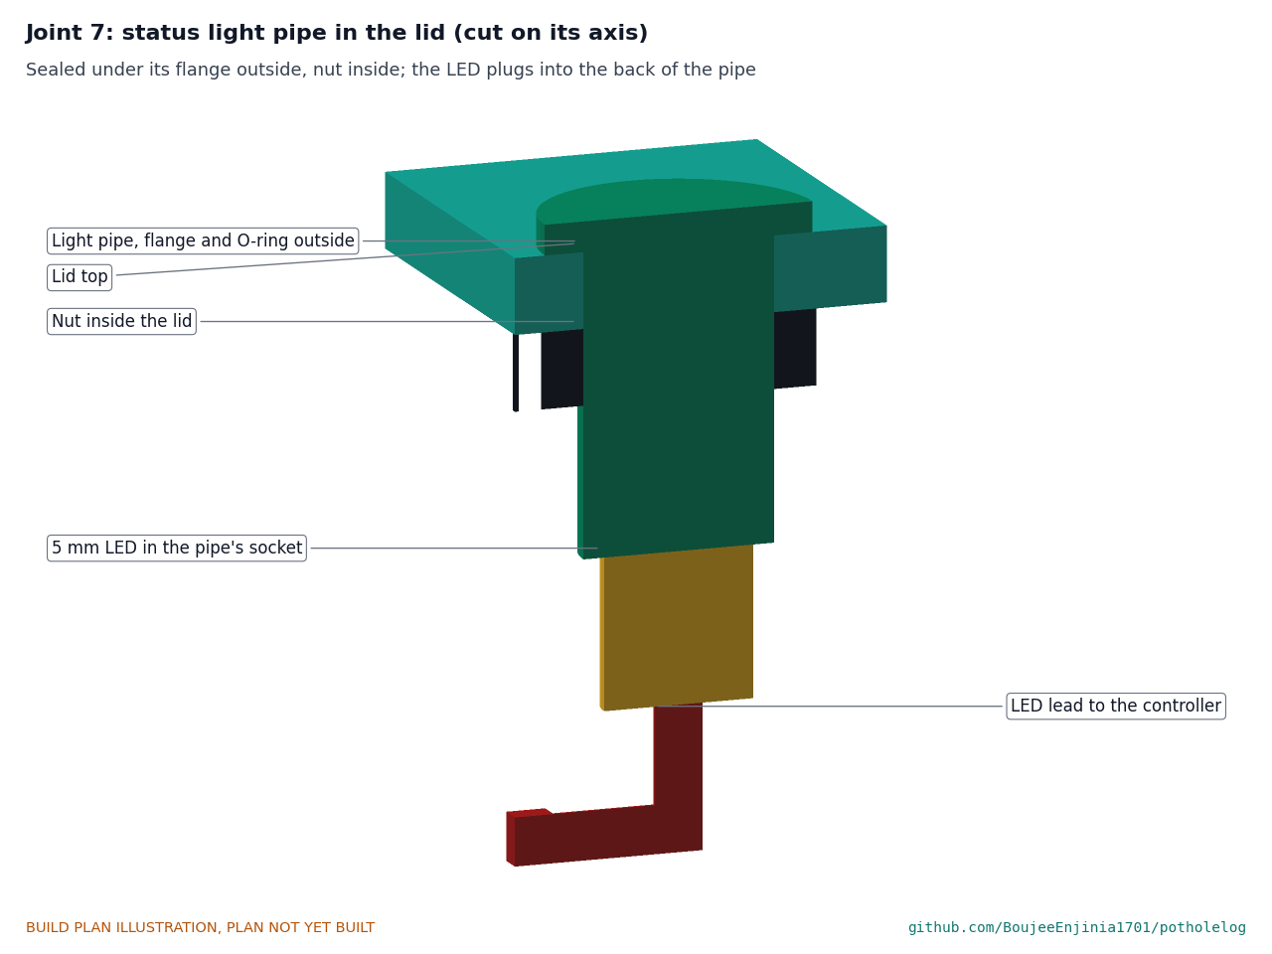
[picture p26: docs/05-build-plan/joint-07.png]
Figure 11b. Joint 7: status light pipe in the lid


*Figure 11b. Each light pipe seals under its flange outside and is held by a nut inside; its LED plugs into the back of the pipe.*

Each light pipe goes in from outside with its O-ring under the flange and its nut inside, clear of the corner pillars; the LED plugs into the back of the pipe (step 7). The nameplate label, 54 x 34 mm, goes on the lid top centred 26 mm forward of the centre with its arrow pointing forward, well away from the area above the GNSS antenna.

**Check before moving on.** No crack runs from either hole; both pipes are tight in the lid and do not turn by hand.

### 3.9 Bought components

Buy to specification, not brand. Line numbers are those of the bill of materials.

- **Enclosure base and lid (lines 2 and 3).** Polycarbonate or ABS, IP65 or better, 120 x 90 x 55 mm outside, flat floor, four moulded corner pillars and lid screws, gasketed opaque lid.
- **DC-DC converter (line 4).** 9 to 60 V input (60 V rated), 5 V 1 A output, about 30 x 40 mm with four mounting holes; a 36 V-class transient suppressor and a reverse-polarity diode on its input.
- **Hold-up capacitor (line 5).** 1 F, 5.5 V, about 16 mm across and 20 mm tall, rated to 70 °C or more, with a 10 ohm resistor, a bypass diode and a Schottky blocking diode.
- **Controller (line 6).** ESP32-S3 board with Wi-Fi and a microSD slot, no larger than about 52 x 26 mm, module rated to 85 °C.
- **IMU (line 7) and GNSS (line 8).** As sections 3.4 and 3.6.
- **Cable gland and fused lead (line 9).** M16 IP68 nylon gland for 4 to 8 mm cable; 2 m two-core lead, inline 2 A blade fuse holder, fuse tap and ring terminals.
- **microSD card (line 10).** 32 GB high-endurance, rated -25 to 85 °C.
- **Hardware (line 11).** Four M6 x 20 bolts, property class 8.8, with washers and nyloc nuts (for the bench board, M6 x 30); hook-up wire 0.5 and 0.25 mm²; two resistors; heat shrink; cable ties.
- **Status light pipes and LEDs (line 14).** Two sealed panel-mount light pipes for a 6.4 mm hole, about 10 mm long, with O-ring, nut and a rear socket for a 5 mm LED; a green and a blue-green 5 mm LED, each with its series resistor; a two-way plug lead.
- **Breather vent (line 15).** M12 x 1.5 screw-in pressure-equalizing vent with a membrane, IP67 or better, with O-ring and locknut.
- **Nameplate label (line 16).** 54 x 34 mm laminated polyester label with outdoor-rated adhesive, printed with the name, a forward arrow and a contact line.
- **Box fixing kit (line 13).** Four M4 hex standoffs as section 3.3; four M4 x 6 pan-head screws; two M3 x 8 pan-head screws; eight 6 mm M3 nylon standoffs with screws; a 22 x 22 mm pad of 1 mm acrylic foam tape; neutral-cure silicone sealant.

## 4. Putting it together

In each picture the parts already fitted are grey and the part being fitted is in colour, with an arrow showing the way it goes in.

### Step 1: cable gland and breather vent into the end walls

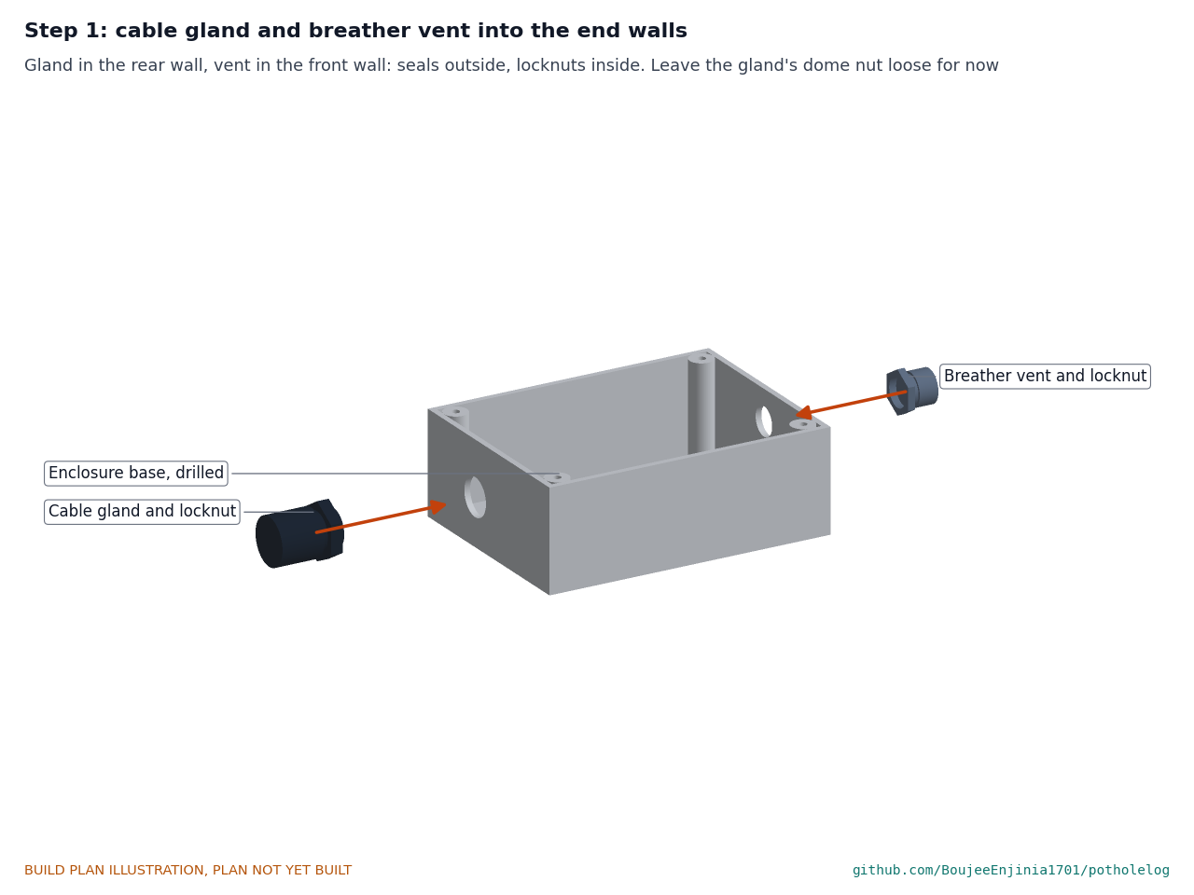
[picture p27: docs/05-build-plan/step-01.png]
Step 1


Gland body and sealing washer outside the rear wall, locknut inside, tightened to the gland maker's torque. Leave the dome nut loose until step 6. Breather vent into the front wall the same way: O-ring outside, locknut inside, hand tight plus the turn its maker gives.

### Step 2: box onto the plate with four hex standoffs

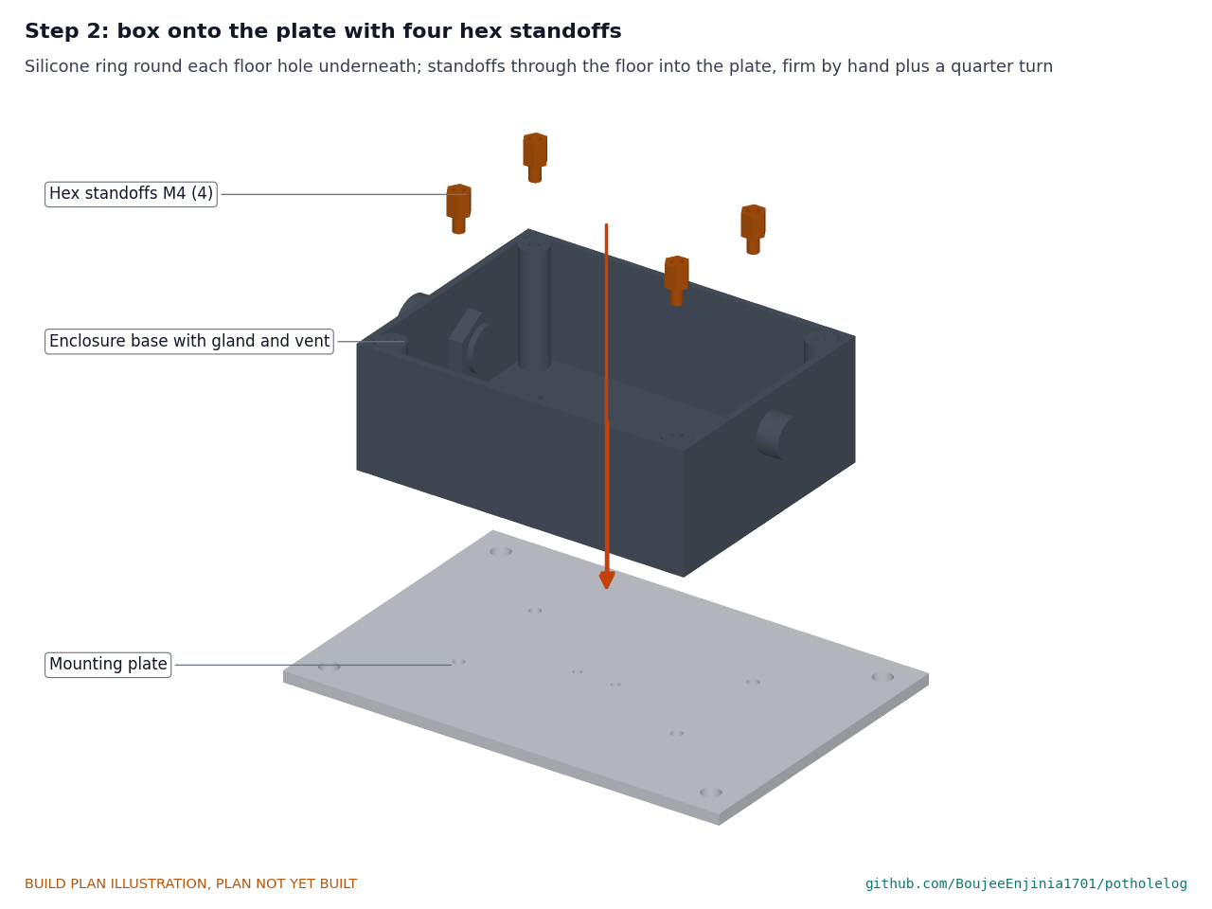
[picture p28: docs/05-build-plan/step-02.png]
Step 2


Put a thin ring of neutral-cure silicone round each of the four standoff holes and two IMU holes on the underside of the box floor. Set the box on the plate, holes lined up, and screw the four standoffs through the floor into the plate, firm by hand plus a quarter turn with a 7 mm spanner. Wipe off any silicone that squeezes out inside.

### Step 3: IMU onto the box floor

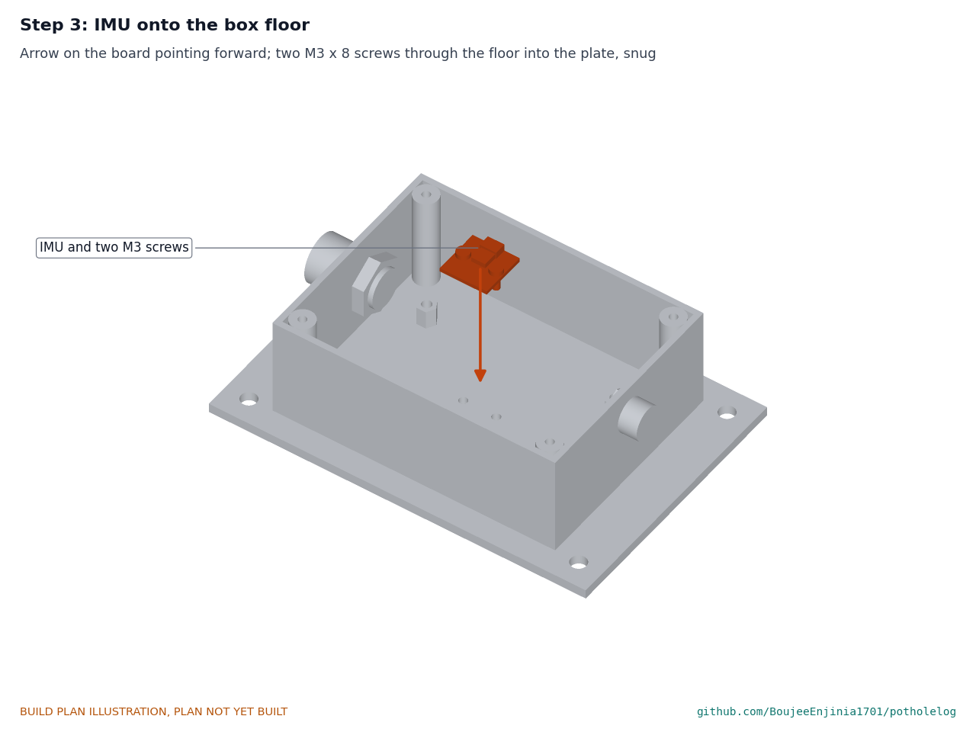
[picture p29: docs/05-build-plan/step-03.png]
Step 3


Board flat on the floor, its forward arrow pointing forward; two M3 x 8 screws through the board and floor into the plate, snug. **Hold point:** let the silicone cure for the time on its tube before going on.

### Step 4: modules onto the carrier plate (on the bench)

Step 4

Screw the eight nylon standoffs up through the carrier from below. Fit the converter and controller on top with M3 screws; stand the capacitor beside the window and tie it through its slots. Wire the modules to each other as section 3.5.1, leaving the lead, IMU and GNSS connections for later.

### Step 5: carrier into the box

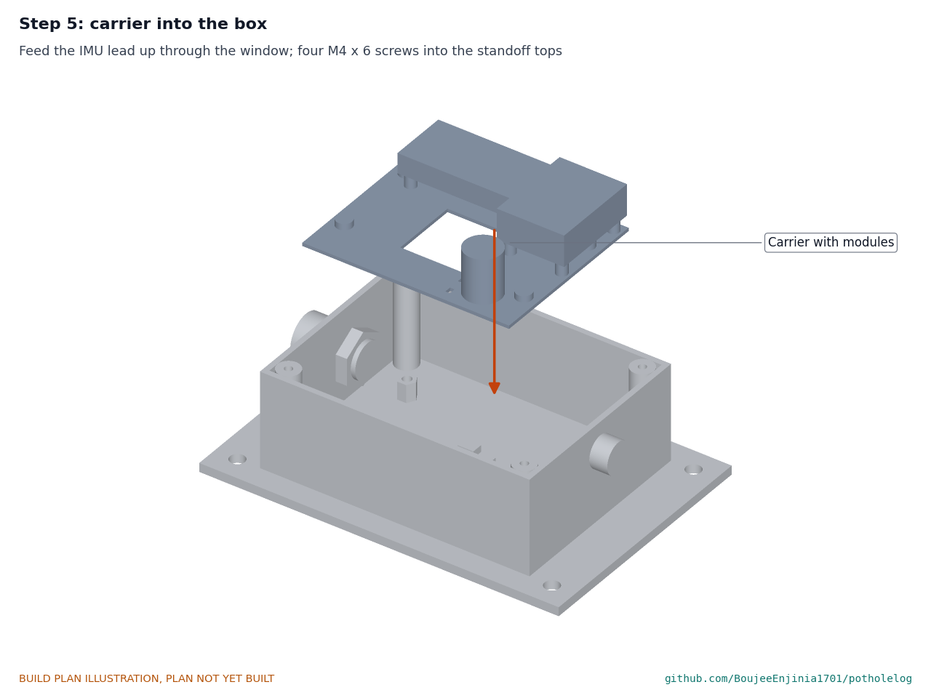
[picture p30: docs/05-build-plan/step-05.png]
Step 5


Feed the IMU lead up through the window, lower the carrier onto the standoff tops and fit four M4 x 6 screws. Plug in the IMU lead.

### Step 6: fused lead through the gland and wired

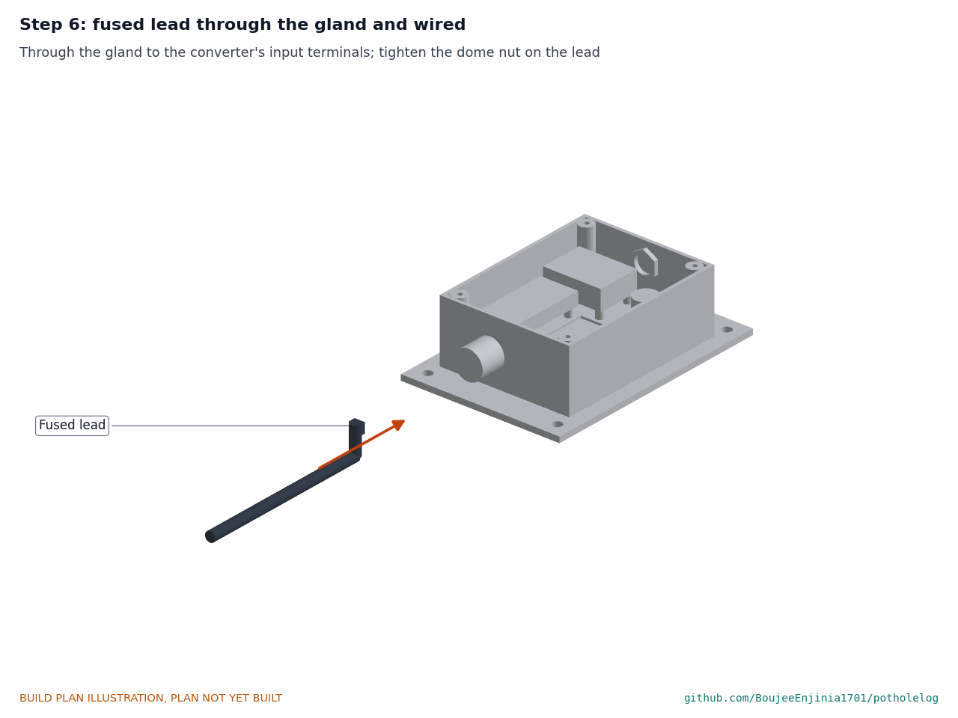
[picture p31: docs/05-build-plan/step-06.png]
Step 6


Pass the lead through the gland, strip it, crimp ferrules and connect it to the converter's input terminals, live and ground as marked. Leave about 40 mm of slack inside, then tighten the gland's dome nut on the lead. **Hold point:** the fuse holder at the far end of the lead has no fuse in it.

### Step 7: light pipes and nameplate onto the lid

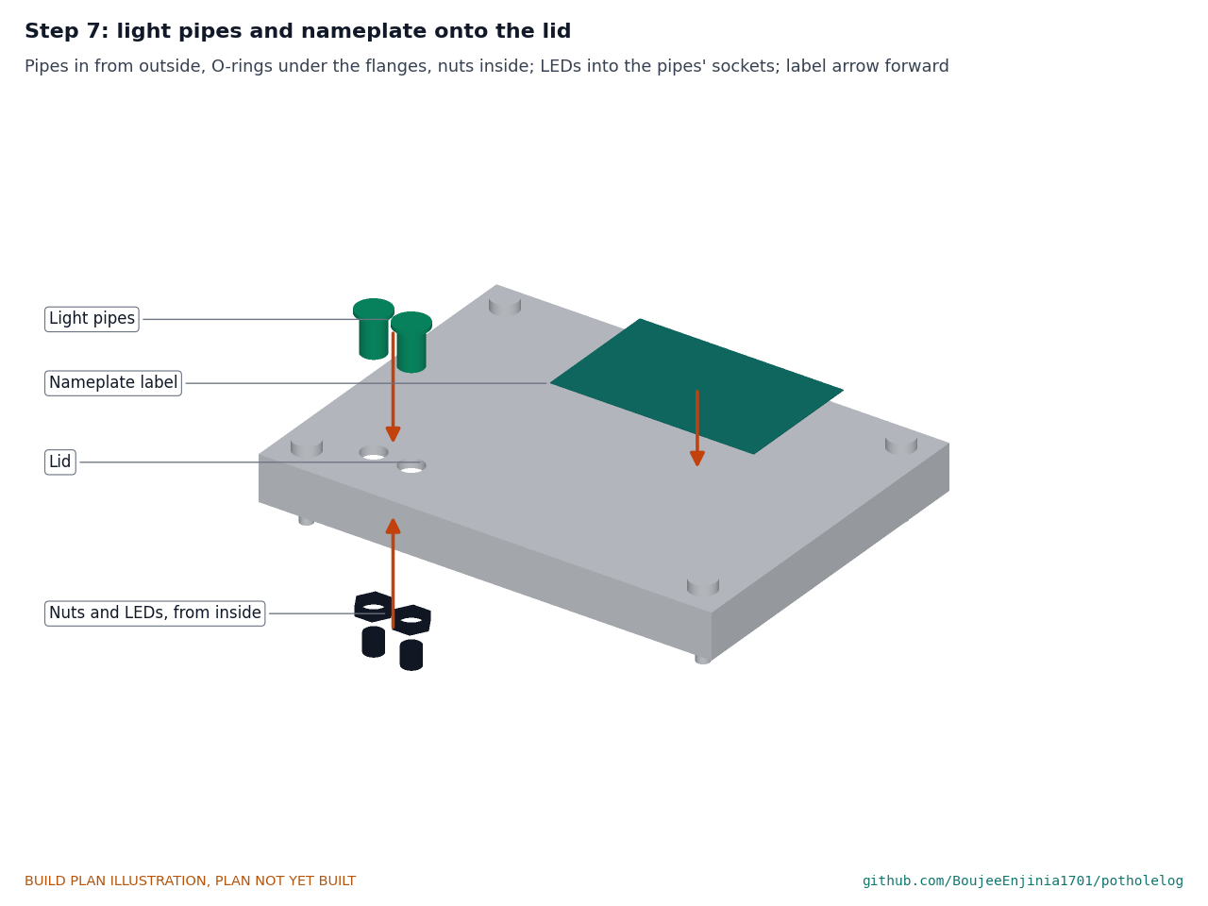
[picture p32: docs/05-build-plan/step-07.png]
Step 7


Push each light pipe into its hole from outside, O-ring under the flange, and tighten its nut inside by hand plus a quarter turn. Push the power LED into the rear pipe's socket and the logging LED into the front one. Clean the lid top with isopropyl alcohol, let it dry, and stick the label on with its arrow pointing forward.

### Step 8: GNSS module under the lid

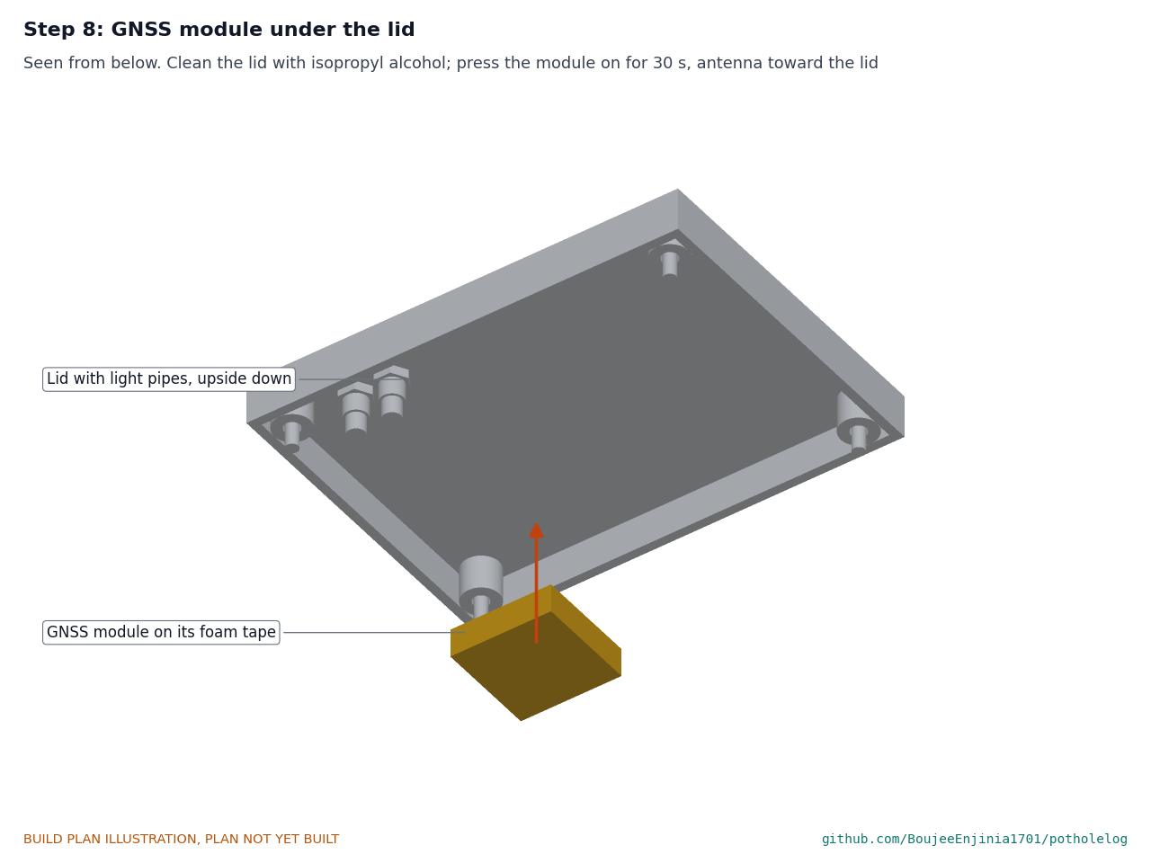
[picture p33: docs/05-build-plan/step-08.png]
Step 8


Clean the inside of the lid top with isopropyl alcohol and let it dry. Stick the tape pad to the module's underside, then press the module onto the lid, antenna toward the lid, for 30 seconds.

### Step 9: close the lid

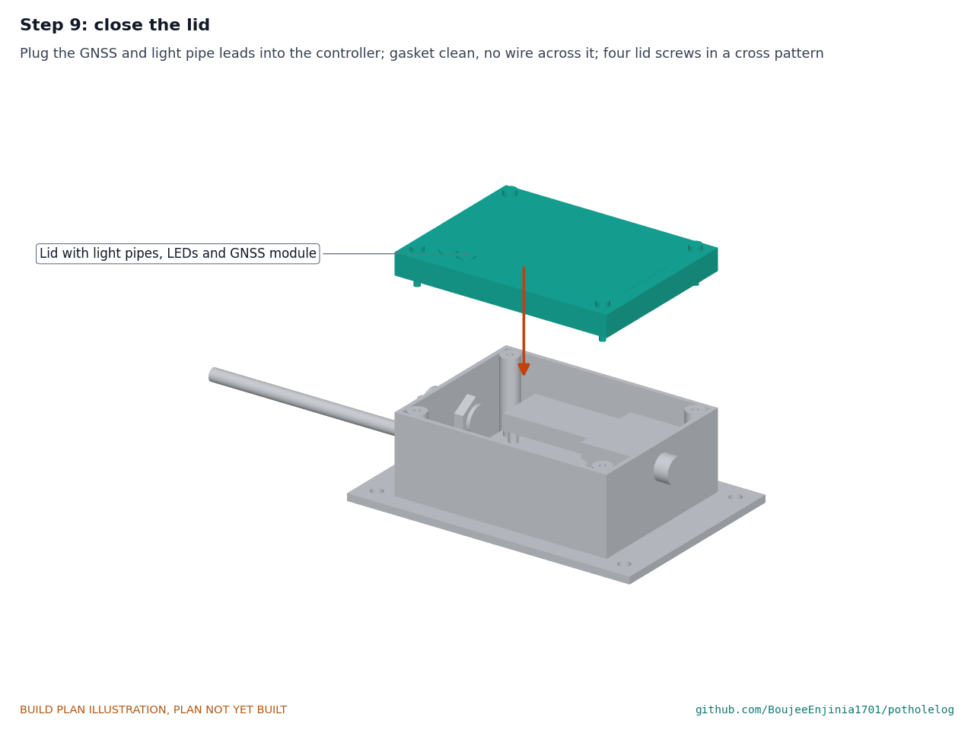
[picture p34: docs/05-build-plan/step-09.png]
Step 9


Plug the GNSS lead and the status light lead into the controller. Check the gasket is clean and seated with no wire across it, and tighten the four lid screws evenly in a cross pattern.

### Step 10: onto the bench board for the first checks

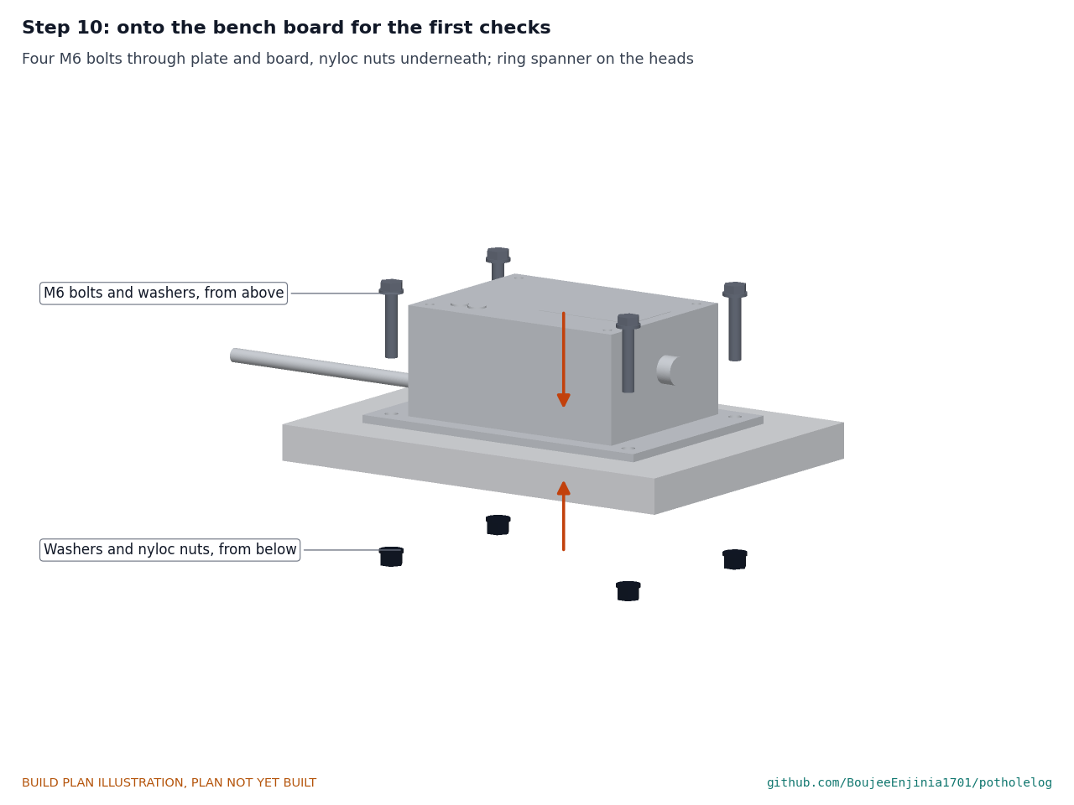
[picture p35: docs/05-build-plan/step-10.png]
Step 10


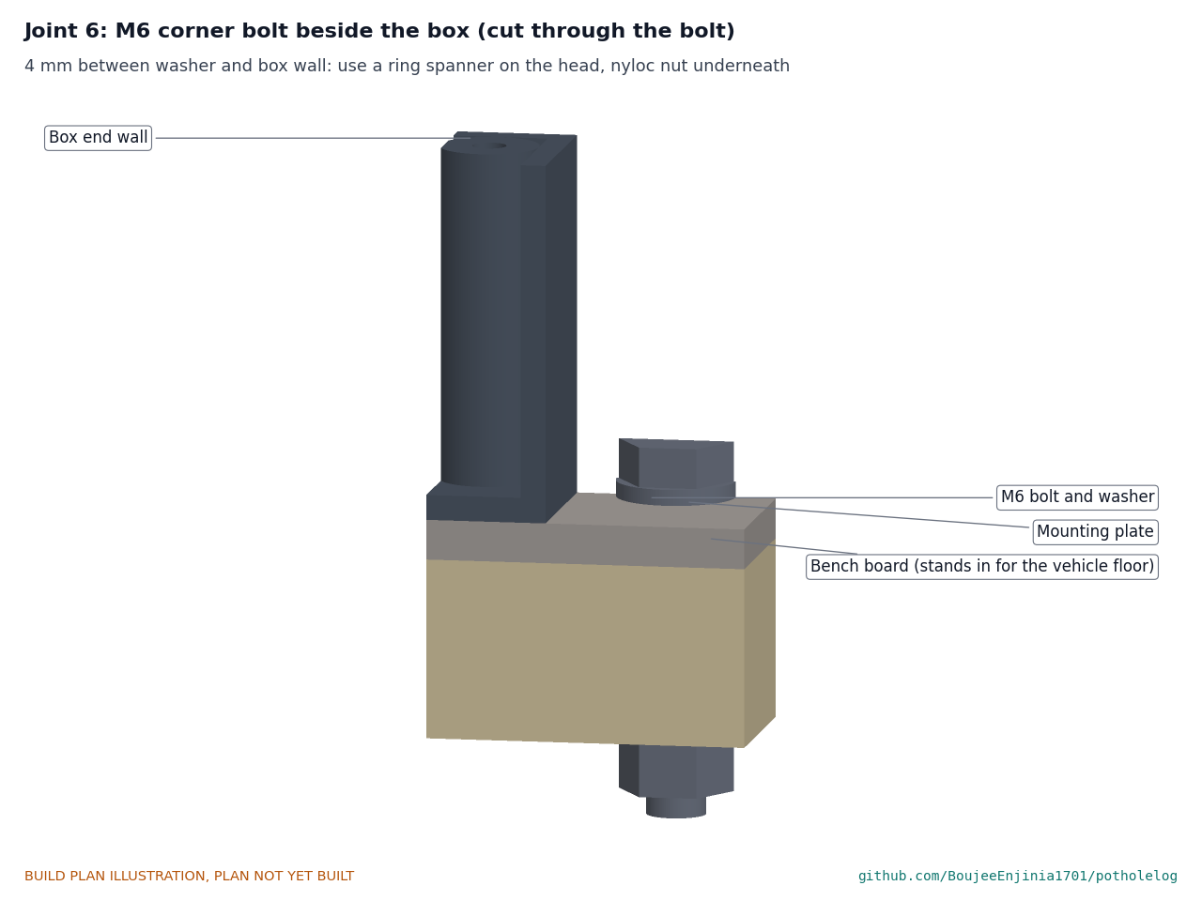
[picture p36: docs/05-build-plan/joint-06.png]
Figure 12. Joint 6: M6 corner bolt beside the box


*Figure 12. There are 4 mm between each washer and the box: hold the bolt head with a ring spanner and tighten the nyloc nut underneath.*

Drill a 220 x 160 mm offcut of 18 mm plywood through the plate's corner holes. Four M6 x 30 bolts with washers from above, washers and nyloc nuts underneath, tightened with a ring spanner on the head and a socket on the nut.

## 5. First checks

These are the checks a TRL 4 test report would record; this plan only lists them. Requirement numbers are those of PHL-REQ-001.

*Table 2. First checks.*

| Check | Requirement | How | Pass when |
| --- | --- | --- | --- |
| Fit and seal | R11 | Look at the gasket, gland, vent, light pipes and floor holes under a lamp; tug the lead | Gasket seated all round; silicone ring visible round every floor hole; vent and light pipes tight with O-rings seated; the lead does not move in the gland |
| Supply polarity and current | R9 | Bench supply at 12 V, current limit 0.5 A, 2 A fuse in the lead; then reversed for 5 s | About 45 mA when running; no current and no damage when reversed |
| Supply range | R9 | Bench supply at 9 V, 24 V and 32 V | Runs at each; current falls as voltage rises (about 22 mA at 24 V) |
| Hold-up and clean shutdown | R10 | Running and logging, switch the supply off; repeat 20 times | The controller closes its files every time; the card reads without errors on a computer |
| Status lights | PHL-DEC-001 | Power up; start and stop logging | Power light on whenever powered; logging light shows logging, both visible through the lid in room light |
| Sampling | R6 | Read the IMU and GNSS rates from the logged file with the board still | IMU at 400 Hz or more, GNSS at 5 Hz or more with the timing pulse present |
| Sensor coupling | R6 | Tap the bench board near the logger with a small hammer | A sharp vertical spike in the logged data with no ringing longer than about 20 ms |
| GNSS fix through the lid | R4 | Lid closed, by a window or outdoors | A position fix within the module maker's stated time |
| Upload | R8 | Ignition-on signal from the bench supply within range of a test Wi-Fi network | The day's summary file arrives on the test server |
| Mass | R12 | Weigh the logger without the lead | About 0.44 kg |

## 6. Safety stops

Stop at each point. Carry on only when everything listed is true.

- **S1. Before any supply is connected.** Every wire checked end to end; no fuse in the lead's fuse holder; the converter input reads open between live and ground; no bare conductor near the carrier or the plate.
- **S2. Before the first power.** A certified bench supply, current limit 0.5 A, voltage set to 12 V before connecting; a 2 A fuse in the lead's holder; the logger on the bench board, lid closed.
- **S3. Before any test above 30 V.** The converter's datasheet confirms a 60 V input rating; the bench supply cannot exceed 36 V. Load-dump pulse tests are TRL 4 work and need a proper surge generator, never a bench supply.
- **S4. After power is removed.** Wait 30 s before opening the lid, so the hold-up capacitor has discharged through the controller; never short its terminals.
- **S5. Before fitting to any vehicle (outside this plan).** All checks of section 5 passed; the vehicle parked, secured and switched off, battery isolated; bolted through at existing fixings into structure, never to a thin floor panel and never by cutting or welding structural members; the lead on a fused, ignition-switched circuit and routed clear of moving parts and hot surfaces; the fleet operator's agreement, including the data rules for drivers.

## 7. Tools, skills and workspace

**Tools.** Hacksaw or bandsaw with a fine blade; piercing saw or nibbler; bench vice with soft jaws; bench drill or a drill in a stand; drills 2 to 6.6 mm; step drill to 20 mm; M3 and M4 taps with tap wrench; flat and needle files; deburring tool; scriber, square, steel rule and calipers; 7 mm and 10 mm spanners, a 10 mm ring spanner and socket; screwdrivers; ferrule crimper and wire strippers; soldering iron; multimeter; bench power supply with an adjustable current limit (0 to 36 V, 0 to 2 A); kitchen scale to 1 kg.

**Skills.** No certified trade is needed. Basic metalwork (marking out, sawing, drilling, tapping, filing), careful drilling of plastic, crimping and through-hole soldering, and safe use of a bench power supply. All circuits are extra-low voltage: up to 36 V at the input and 5 V inside. No mains wiring is part of this build.

**Workspace.** A bench about 1.2 x 0.6 m; a metalwork corner kept apart from the electronics so chips stay off the modules; a ventilated spot for the silicone to cure.

**Personal protective equipment.** Safety glasses for cutting, drilling and soldering; gloves when handling cut sheet; no gloves near a turning drill.

## 8. Where the numbers come from

- Model and constructability checks: `cad/src/model.py` (`python cad/src/model.py --check`); STEP and STL exports in `cad/step/` and `cad/stl/`.
- Pictures: `cad/src/build_plan_media.py`, using `.kit/build_views.py`; written to `docs/05-build-plan/` and `cad/drawings/PHL-DWG-101` to `PHL-DWG-104`.
- General arrangement: `cad/drawings/PHL-DWG-001.pdf`, Rev P4.
- Calculations: `docs/04-calcs/01-sizing.md` (PHL-CAL-001 v0.5) and `docs/04-calcs/sizing.py`; power and supply current [F1], [F2], hold-up [G1], mass [H2], fixings [H3], plate stiffness [I1], spanner room [I4].
- Bill of materials: `bom/bom.csv` (16 lines).
- Decisions of 2026-10-02 (light pipes, vent, label): `docs/06-design-decisions.md` (PHL-DEC-001).
- Decisions: `docs/decisions/0003-design-for-construction.md` (PHL-DDR-003), with PHL-DDR-001 and PHL-DDR-002.
- Requirements: `docs/03-requirements.md` (PHL-REQ-001 v0.7).

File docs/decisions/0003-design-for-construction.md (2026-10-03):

---
doc_id: PHL-DDR-003
title: PotholeLog design for construction
project: PotholeLog
doc_type: Design decision record
version: "0.3"
status: Draft
date: '2026-10-02'
author: Amish Chadha
license: CERN-OHL-S-2.0
revisions:
- version: "0.1"
  date: '2026-10-01'
  author: Amish Chadha
  change: Changes that make the concept physically buildable, with the reason for each; made under Amish's 2026-09-30 instruction to make the design physically buildable; open for his review
- version: "0.2"
  date: '2026-10-02'
  author: Amish Chadha
  change: 'A1 to A3 accepted by Amish on 2026-10-02 as recommended; Tables 1 and 2 still open for review'
- version: "0.3"
  date: '2026-10-02'
  author: Amish Chadha
  change: "Tables 1 and 2 accepted by Amish on 2026-10-02"
---

# 0003: Design for construction

- **Date:** 2026-10-01
- **Status:** accepted. Amish, 2026-10-02: "APPROVED: Design-for-construction changes in 10 repos (CityTwin, CoolShade, PalletPilot, Heliolite, PotholeLog, EarthPress, ReadyKit, CellCheck, CargoMule and ThermaCart)". This covers the changes P1 to P7 in Table 1 and the knock-on changes in Table 2, made under Amish's 2026-09-30 instruction to make the design physically buildable, and is recorded in the design decisions register (PHL-DEC-001). The questions in Table 3 (A1 to A3) were accepted by Amish as recommended earlier the same day: "i approve your recommendations for all 555 open decisions." They are recorded in the register too.

## Context

On 2026-09-30 Amish asked for every repo to have an illustrated build plan that shows how each component is made and how it fits the next, and wrote: "If you are realising that the design cannot be built as per concept - fix the design assumptions to match and be physically feasible as you draw the illustrations." The concept model of PHL-DDR-002 showed what PotholeLog does, but checking it with build123d (overlaps, contacts and clearances between every pair of parts) found modules that overlapped one another or a fixing, parts with no fixing at all, and stock-box features that were not modelled and would have clashed.

The changes keep what the logger does: the same 160 x 110 x 4 mm plate and M6 pattern, the same 120 x 90 x 55 mm stock box, the same modules and electrical design, the IMU on the box floor on the centre line, the GNSS under the plastic lid, the gland and lead on the rear end wall, and the same mounting place on the vehicle floor. Nothing here changes the pitch or the safety case. Every change is in `cad/src/model.py`, which now runs 48 constructability checks (`python cad/src/model.py --check`): parts that must touch do touch, parts that must not touch are apart by at least the stated clearance, and nothing reaches below the plate's underside. All 48 pass.

## Decision

*Table 1. Changes made to the model, the BOM and the calculations.*

| # | Problem in the concept | Change made | Why this way |
| --- | --- | --- | --- |
| P1 | The box was held by four M4 screws through its floor on a 100 x 70 mm pattern. Two of the screw heads lay under the converter, which sat directly on the floor, and all four fell where a stock box has its moulded corner pillars for the lid screws. | The box is held by four M4 male-female hex standoffs (7 mm across flats, 8 mm body, 6 mm male thread) on an 80 x 40 mm pattern. The male end passes through a 4.5 mm hole in the floor into an M4 tapped hole in the plate and clamps the floor down; a ring of neutral-cure silicone round each hole under the floor seals it. | One part both holds the box down and carries the modules (P2). The 6 mm thread stops 0.5 mm short of the plate's underside, so the plate still sits flat. The new pattern is clear of the corner pillars, the IMU and the gland. |
| P2 | The converter, supercapacitor and controller had no fixings: the converter and supercapacitor stood on the floor, and the controller on a "standoff rail" that was not a part. | A module carrier plate (92 x 76 x 1.5 mm aluminium, new BOM line 12) sits on the four hex standoffs, 8 mm above the floor, held by four M4 x 6 screws. The converter and controller stand on 6 mm M3 nylon standoffs on it; the supercapacitor stands on it, held by a cable tie through two slots. A 30 x 30 mm window over the IMU leaves the IMU and its lead clear. | Bought modules are made to be screwed to a plate on standoffs. A flat aluminium sheet is cut and drilled with the same tools as the mounting plate. The carrier stays 1.5 mm clear of the walls and pillars and 4.5 mm clear of the gland locknut. |
| P3 | The supercapacitor overlapped the controller by 0.5 mm, and the controller's end touched the inside of the end wall where the gland's locknut goes. | The converter is turned 90 degrees (30 x 40 mm footprint) and placed at the front left; the controller moved 19 mm forward, onto the carrier, at the rear left; the supercapacitor sits at the front right, beside the window. Every module is at least 2 mm from the next and 7.5 mm or more from the gland locknut. | The box size is unchanged; only the layout inside it moved. |
| P4 | The gland was a cylinder against the outside of the end wall, with no hole and no locknut inside. | A 16.2 mm hole in the rear end wall, 10 mm left of centre and 20 mm up from the box's underside (where the concept had the gland); the M16 gland body outside with its seal, and its locknut inside. | This is how a gland is fitted; the locknut needs the inside room that P3 makes. |
| P5 | The IMU was "screwed to the box floor" with no fixing shown; a screw into 2.5 mm of plastic alone would hold poorly and let the floor flex under the sensor. | Two M3 x 8 screws pass through the IMU board and 3.5 mm holes in the box floor into M3 tapped holes in the plate, clamping the board, floor and plate together. Silicone seals the two floor holes. | The IMU stays on the box floor, on the centre line, where the concept put it, and is now clamped to the aluminium plate the vehicle shakes, which keeps the measurement path stiff. The screws stop 0.1 mm short of the plate's underside. |
| P6 | The GNSS module floated under the lid with no fixing. | A 22 x 22 mm pad of 1 mm acrylic foam tape holds it under the lid top, antenna up; a plug-in lead joins it to the controller so the lid can be set aside. | No hole in the lid, so the seal and the sky view through the plastic lid are unchanged. |
| P7 | The stock box's corner pillars and lid screws were not modelled. | Four moulded corner pillars in the base and lid and four lid screws are modelled as on a stock IP65 box; every part inside is checked clear of them. | They exist on the box that will be bought, and they set where the box fixings and carrier can go. |

*Table 2. Knock-on changes.*

| Item | Change | Reason |
| --- | --- | --- |
| Plate | Hole pattern: four M4 tapped holes on 80 x 40 mm (were on 100 x 70 mm) and two new M3 tapped holes 14 mm apart for the IMU. Size, thickness and M6 pattern unchanged. | P1, P5 |
| Mass | Logger 0.43 kg (was 0.37 kg); 0.57 kg with the lead and fixings (was 0.51 kg) [H2]. | Carrier 24 g, standoffs, screws and tape 21 g, and the box's pillars. |
| Plate stiffness | First mode 168 Hz (was 186 Hz) on the conservative half-width model [I1]; R12's 150 Hz is still met on paper. | More mass rides on the plate. |
| Crash loads | 21 N per M6 bolt (was 18 N) and 46 N on the four hex standoffs (was 34 N on the box screws) at 20 g [H3]. | Mass. |
| Cost | BOM line 12 (carrier, $2.00) and line 13 (box fixing kit, $1.50) added; line 11 repriced from $3.00 to $2.50 because its M4 screws and M3 standoffs moved to line 13. Estimated cost $74.00, $1.00 under the unchanged $75 value-engineering target (`budget_usd`) [J1]. | Parts added for construction. |
| Drawing | PHL-DWG-001 Rev P3; making sketches PHL-DWG-101 to 103 added. | Follows the model. |
| Documents | PHL-CAL-001 v0.3, PHL-PRC-001 v0.5, PHL-REQ-001 v0.5: mass, stiffness, crash and cost figures; R15 restated against the value-engineering target. No requirement changed status. | Follows the model. |
| Unchanged | Power, hold-up, storage, upload, detection, location and self-heating results; overall height 59 mm; box and plate size. | No change touches them. |

*Table 3. Proposed, then accepted by Amish as recommended on 2026-10-02.*

| # | Question | Options | Recommendation |
| --- | --- | --- | --- |
| A1 | How the four standoff holes and two IMU holes in the box floor are sealed against the plate. | (a) a ring of neutral-cure silicone round each hole under the floor, as modelled; (b) a 1 mm closed-cell foam gasket sheet between the box and the plate. | (a) for the prototype; spray-test at TRL 4 before choosing for a pilot. Accepted 2026-10-02; the foam gasket is the fallback if the spray test leaks. |
| A2 | The GNSS module is held by foam tape, which ages in a hot cabin. | (a) acrylic foam tape, as modelled; (b) a small printed clip screwed to two lid pillars. | (a); check adhesion after the TRL 4 heat soak. Accepted 2026-10-02; the printed clip is the fallback if the tape lets go. |
| A3 | Spanner room at the M6 bolts is 4 mm between washer and box wall (2 mm for a 10 mm socket), so the logger is bolted down as a unit with a ring spanner. | (a) keep the plate and use a ring spanner, as planned; (b) lengthen the plate to 180 mm with the M6 holes 160 mm apart, for socket room (plate mass and first mode change). | (a) for the prototype; review after a TRL 4 trial fitting. Accepted 2026-10-02 (a longer plate would lower the 168 Hz first mode toward R12's 150 Hz limit). |

## Consequences

- `design_state: constructable` in `project.yaml`. The build plan PHL-BLD-001 shows every component and step in pictures generated from the model (`cad/src/build_plan_media.py`).
- Requirement status is unchanged: 0 not met, 6 at risk, 2 not verifiable at TRL 3, 4 met on paper, 4 met by design (PHL-CAL-001 v0.3).
- The photoreal renders (`media/render-*.png`), `media/card.png`, `media/social-preview.png` and the appearance model `cad/src/product_model.py` still show the concept's internal layout (converter beside the controller on the floor, no carrier plate). The outside of the logger is unchanged, so the hero render is still true; the exploded and detail renders need updating on Amish's Mac, where Blender is.
- With A1 to A3 accepted, the build plan stands as written: silicone rings round the floor holes, the GNSS module on foam tape and the logger bolted down as a unit with a ring spanner.
- The enclosure, converter, controller, IMU and GNSS parts are chosen at TRL 4; their sizes and hole positions must be checked then, and the carrier holes marked from the parts bought.

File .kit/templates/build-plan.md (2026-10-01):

---
doc_id: PRJ-BLD-001
title: Project prototype build plan
project: Project name
doc_type: Build plan
version: "0.1"
status: Draft
date: YYYY-MM-DD
author: Amish Chadha
license: CERN-OHL-S-2.0
revisions:
  - version: "0.1"
    date: YYYY-MM-DD
    author: Amish Chadha
    change: First build plan; design made constructable
---

# Project prototype build plan

**Plan, not yet built.** How to build the first proof-of-concept prototype, component by component. Building and testing to it is TRL 4 work. Decisions still to be made are kept in the design decisions register (`docs/06-design-decisions.md`), not here.

## 1. What you are building

Every component, pulled apart and numbered in build order

One short paragraph: what the prototype is, how many components, which are made and which are bought, and the main ways they are made.

## 2. What changed to make it buildable

| Component | The concept had | The buildable design has | Why |
| --- | --- | --- | --- |

## 3. Making the components

### 3.1 Component name

Making sketch

**What it is and what it is made from.**

**How to make it.**

1. Mark out ...
2. Cut ...

**How it fits the parts next to it.**

Close-up of the joint

**Check before moving on.**

## 4. Putting it together

### Step 1: ...

Step 1

## 5. First checks

| Check | Requirement | How | Pass when |
| --- | --- | --- | --- |

## 6. Safety stops

## 7. Tools, skills and workspace

## 8. Where the numbers come from

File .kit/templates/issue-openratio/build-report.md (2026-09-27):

---
name: Build report
about: Tell us what happened when you built, printed or tested part of this design
title: "Build report: "
labels: build-report
---

This is a research and educational prototype, not a medical device. It is a TRL 3 concept and is not released for fabrication. If you build any part of it, you do so at your own risk. Reports help everyone.

**What you built** (part, sub-assembly or test)

**Materials, tools and settings**

**What worked**

**What did not work, with photos or measurements if you have them**

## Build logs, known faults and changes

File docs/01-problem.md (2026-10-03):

---
doc_id: PHL-PRB-001
title: PotholeLog problem statement
project: PotholeLog
doc_type: Problem statement
version: "0.7"
status: Draft
date: '2026-10-02'
author: Amish Chadha
license: CERN-OHL-S-2.0
revisions:
- version: "0.1"
  date: '2026-09-25'
  author: Amish Chadha
  change: Initial scaffold
- version: "0.2"
  date: '2026-09-25'
  author: Amish Chadha
  change: Populate to TRL 2 (problem, users, context, constraints, prior work with sources)
- version: "0.3"
  date: '2026-09-25'
  author: Amish Chadha
  change: Reflect PHL-DDR-001 (floor mount, depot upload, privacy rule, bicycles deferred) and the tyre-bridging finding of PHL-CAL-001
- version: "0.4"
  date: '2026-09-25'
  author: Amish Chadha
  change: Recommendations accepted by Amish (DDR-002)
- version: "0.5"
  date: '2026-10-01'
  author: Amish Chadha
  change: Budget treated as a value-engineering target
- version: "0.6"
  date: '2026-10-02'
  author: Amish Chadha
  change: 'First pilot partner stated as decided on 2026-10-02 (PHL-DEC-001)'
- version: "0.7"
  date: '2026-10-02'
  author: Amish Chadha
  change: 'Cost estimate USD 77.50 with the parts adopted on 2026-10-02'
---

# PotholeLog problem statement

Road surveys are expensive and infrequent, so repairs follow complaints rather than condition. Most cities and road agencies already run vehicles over every street each week, but those trips produce no record of the road surface. A low-cost logger on those vehicles could turn routine driving into a continuous, repeatable condition survey.

## The problem

Road condition data is collected in two main ways today, and both leave gaps.

- **Survey vehicles and profilers.** Agencies measure roughness with instrumented vans or profilers and report it as the International Roughness Index (IRI), a standard scale the World Bank set out in 1986 ([Sayers, Gillespie and Paterson, World Bank Technical Paper 46](https://documents1.worldbank.org/curated/en/851131468160775725/pdf/multi-page.pdf)). These surveys are accurate but are usually repeated only every year or several years, and local streets are surveyed least often.
- **Complaints and patrols.** Potholes on local streets are mostly found by residents reporting them or by inspectors on foot or in a car. This favors busy and vocal neighborhoods and misses defects on routes that few people report.

The size of the gap is large even in well-funded networks. In the United States, about 25 % of the reported mileage of urban "other principal arterials" had an IRI above 170 in/mi (2.7 m/km) in 2023, the level the Federal Highway Administration treats as poor (computed from [FHWA Highway Statistics 2023, table HM-64](https://www.fhwa.dot.gov/policyinformation/statistics/2023/hm64.cfm)). In England, local authorities rated 17 % of their unclassified roads, the small residential and rural roads, as needing maintenance to be considered in the year to March 2025 ([DfT, Road conditions in England to March 2025](https://www.gov.uk/government/statistics/road-conditions-in-england-to-march-2025)).

Poor surfaces also matter for safety. About 1.16 million people die each year in road traffic crashes, 92 % of them in low- and middle-income countries, and more than half are pedestrians, cyclists and motorcyclists ([WHO fact sheet](https://www.who.int/news-room/fact-sheets/detail/road-traffic-injuries)). Road surface is only one factor in those crashes, but it weighs most on two-wheelers, and it is the factor that condition data helps a maintenance team act on.

## Users and context

| User | Need | Context |
| --- | --- | --- |
| City or county road maintenance team | A map of where roads are rough and where new potholes appear, updated weekly, to plan patching and resurfacing | Small engineering team, limited survey budget, existing asset or GIS system |
| Fleet operator (transit agency, refuse contractor, municipal fleet) | A device that installs in minutes, needs no driver action and does not track drivers | Vehicles return to a depot daily; maintenance staff install and service devices |
| Drivers | No distraction, no performance monitoring | The device is out of sight and has no controls |
| Residents and cyclist groups | Evidence that repairs follow measured condition, not only complaints | Open data published by the city |
| Road agencies in low- and middle-income countries | Network condition data where survey vans are unaffordable | Mixed paved and unpaved roads, minibuses and trucks, intermittent connectivity |

Operating context assumed for the concept:

- Host vehicles are city buses, refuse trucks and similar fleet vehicles on fixed or repeated routes. They run about 8 to 12 h a day at 0 to 80 km/h and return to a depot each night (assumption).
- The logger is bolted to a rigid point of the vehicle floor or structure above the rear axle and wired to the ignition-switched 12 V or 24 V supply (floor mount decided by Amish, 2026-09-25, PHL-DDR-001 D3).
- A bus tyre about 1 m in diameter bridges much of a small pothole: it can drop only about 22 mm into one 300 mm long (PHL-CAL-001). Small potholes are therefore sought on slow passes, 10 to 30 km/h near stops and junctions (PHL-DDR-002), and larger ones at any speed.
- Each street is driven many times a month by one or more vehicles, so results can be averaged over passes and vehicles.
- The vehicle filters the road input through its tyres and suspension, and each vehicle responds differently, so the raw signal must be calibrated per vehicle before it can be compared with IRI.

## Prior work

- **Pothole Patrol (MIT, 2008).** Accelerometers and GPS on 7 taxis in Boston. A simple classifier misidentified good road as potholes less than 0.2 % of the time, and after clustering over 90 % of reported potholes contained road anomalies needing repair ([Eriksson et al., MobiSys 2008](https://doi.org/10.1145/1378600.1378605)). This is the closest precedent and shows the approach works on fleet vehicles.
- **Response-type roughness measuring systems.** The World Bank IRI guidelines describe instruments that measure a vehicle's response to the road and convert it to IRI with a calibration equation found experimentally for that specific vehicle ([World Bank Technical Paper 46](https://documents1.worldbank.org/curated/en/851131468160775725/pdf/multi-page.pdf)). PotholeLog follows the same principle with a cheaper sensor.
- **Smartphone apps.** Several cities and development agencies have used phone apps to log bumps and roughness. Phones are cheap but move in their mounts, change between trips and depend on a volunteer; a fixed, calibrated logger avoids those problems.

## Constraints

- Garage-buildable prototype, with parts cost judged against a value-engineering target of about $75 USD per unit (`budget_usd` in `project.yaml`, a hypothetical control target, raised from $70 under PHL-DDR-002 to cover a 60 V converter); the constructable design is estimated at $77.50 with the status lights, breather vent and nameplate adopted on 2026-10-02, $2.50 over the target.
- Off-the-shelf modules only; no custom PCB for the first build.
- Installs on a fleet vehicle without cutting or welding structural members and without the driver doing anything.
- Road data only: no camera, no microphone, and no driver behavior scoring. Only road-segment roughness and defect clusters are published; vehicle tracks and timestamps stay on the operator's server (privacy rule decided by Amish, 2026-09-25).
- This build serves buses and refuse trucks; a bicycle variant is a later step (PHL-DDR-001, D1).
- Open hardware (CERN-OHL-S-2.0) and open software (MIT), with outputs in open formats (CSV, GeoJSON).

## Out of scope

- Replacing a calibrated profiler for pavement design or contract acceptance.
- Measuring crack type, rutting depth or skid resistance.
- Real-time alerts to drivers.

> **Safety:** The logger is installed on vehicles that operate in traffic and are connected to a vehicle electrical system. Mounting, wiring and fusing must follow the fleet operator's procedures. See the precis (PHL-PRC-001) for the full safety section.

## User research and co-design

This design is for communities the author is not part of, so requirements come from the people who will use it.

- [ ] Identify a local partner organization (Helpful Engineering network, NGO or university); the first pilot partner to approach is a Dallas-Fort Worth area city with its own bus or refuse fleet, with TxDOT pavement management roughness data on state roads in that city as the reference IRI sections (decided 2026-10-02, PHL-DEC-001)
- [ ] Run co-design sessions with intended users; record who, where and what was learned
- [ ] Validate load, distance, terrain and cost assumptions in the field
- [ ] Revise requirements (REQ) from findings before freezing the design

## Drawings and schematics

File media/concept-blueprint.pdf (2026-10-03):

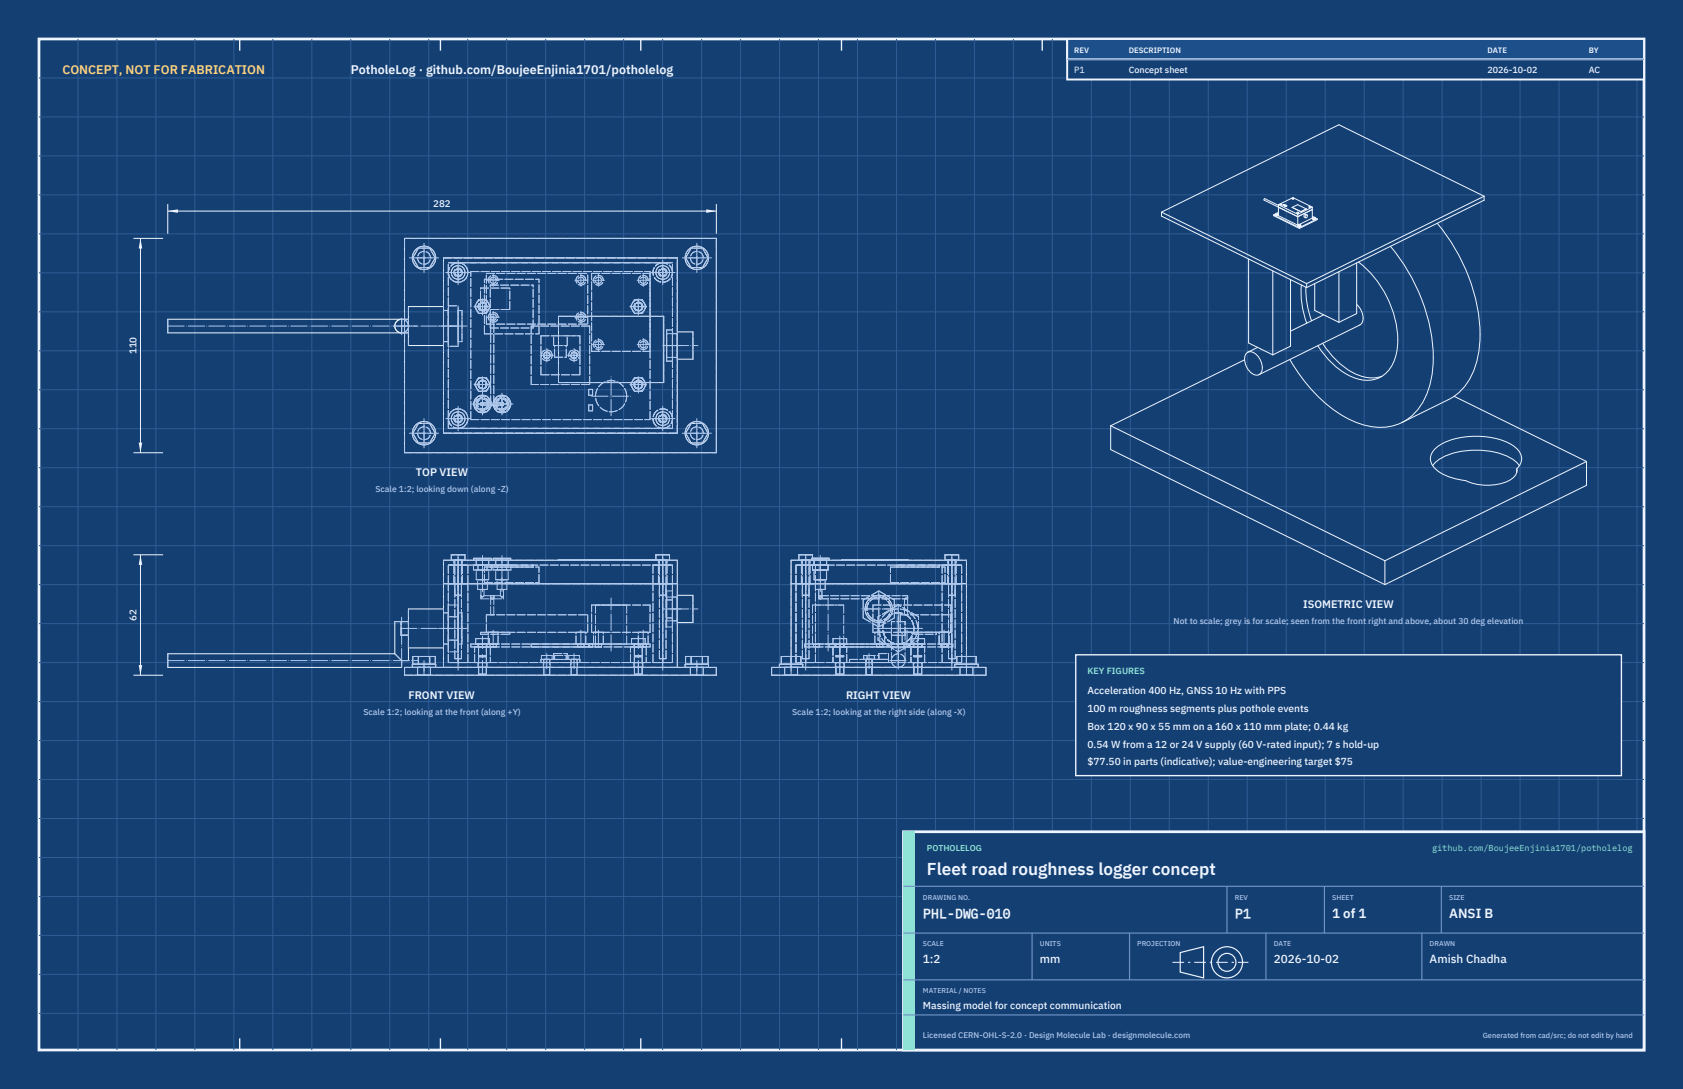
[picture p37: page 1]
CONCEPT, NOT FOR FABRICATION; PotholeLog · github.com/BoujeeEnjinia1701/potholelog; FRONT VIEW; TOP VIEW; RIGHT VIEW; ISOMETRIC VIEW; REV; DESCRIPTION; DATE; Concept sheet; POTHOLELOG; github.com/BoujeeEnjinia1701/potholelog; DRAWING NO. PHL-DWG-010; REV P1; SHEET 1 of 1; SIZE ANSI B; SCALE 1:2; UNITS mm; PROJECTION; DRAWN Amish Chadha; Licensed CERN-OHL-S-2.0 · Design Molecule Lab · designmolecule.com; Generated from cad/src; do not edit by hand

Scale 1:2; looking down (along -Z)

Not to scale; grey is for scale; seen from the front right and above, about 30 deg elevation

KEY FIGURES
Acceleration 400 Hz, GNSS 10 Hz with PPS
100 m roughness segments plus pothole events
Box 120 x 90 x 55 mm on a 160 x 110 mm plate; 0.44 kg
0.54 W from a 12 or 24 V supply (60 V-rated input); 7 s hold-up
$77.50 in parts (indicative); value-engineering target $75

Scale 1:2; looking at the front (along +Y)

Scale 1:2; looking at the right side (along -X)

Fleet road roughness logger concept

MATERIAL / NOTES
Massing model for concept communication

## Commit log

2026-09-25 Initial scaffold: standard open hardware layout, CERN-OHL-S v2 + MIT licenses
    Claude-Session: https://claude.ai/code/session_01XuhhSU4W6fYhgCfURbrkut
    [bom.csv]
2026-09-26 Populate to TRL 2: problem, requirements, precis, concept media, BOM and README use cases
    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
    [bom.csv]
2026-09-26 Advance to TRL 3: DDR-001, CAL-001 sizing, parametric model with STEP/STL, GA drawing, priced BOM; TRL 4 on hold
    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
    [bom.csv, enclosure.step, enclosure.stl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]
2026-09-26 Accept all recommendations (DDR-002), switch footer to designmolecule.com, add README write-up with new inspiration point
    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
    [bom.csv, enclosure.step, mounting-plate.step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]
2026-09-27 Product appearance model and photoreal renders
    Adds cad/src/product_model.py (appearance model for renders only, all main
    dimensions from model.py) and Blender renders in media/render-*.png,
    captioned with the project, repository and viewing direction. README leads
    with the product render; trl stays 3.
    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
2026-10-01 Image quality pass: legible exploded views, flow diagrams and drawing sheets
    Kit 1.6.1 image layout: the parts list sits in its own column, number bubbles sit on visible parts and never overlap, small parts get a leader, pictures are cropped to the subject, flow labels keep numbers with their units, and sheet captions and the revision table no longer overprint. Concept images, blueprint and general arrangement sheet regenerated; repo-specific labels moved clear of other text and lines.
2026-10-01 Kit 1.7.0: constructable design, illustrated build plan and design decisions register
    The design is now constructable: every part can be made and fits its neighbours, with each change recorded in a Design for construction decision record (made under Amish's 2026-09-30 instruction; ope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
    FlexHand also credits Dr. Geeti Chadha as a contribut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
    [bom.csv, enclosure.step, enclosure.stl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]
2026-10-02 Record Amish's approval of the open-decision recommendations
    Amish approved the recommendation on every open decision in the design decisions register ("i approve your recommendations for all 555 open decisions.", 2026-10-02). Each decision is moved to Decisio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
2026-10-03 Carry approved follow-ups into the design and redo photoreal renders
    Amish approved the follow-up actions from the open-decision sign-off ("APPROVED CHANGES, COMPLETE THESE", 2026-10-02), the design-for-construction change tables in ten repos, the last wave's open dec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
    [bom.csv, enclosure.step, enclosure.stl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]
2026-10-03 Record Amish's 2026-10-03 decisions; FlatTrike fork and PotPress guard fixes
    Amish, 2026-10-03: "PalletPilot - i accept it"; "FlatTrike - i accept your design recommendation, proceed and execute the solution for fork direction or caster"; "PotPress - move forward with the four guard fixes. I accept the cost."; "GravitySort - i accept your recommendation"; "TIght Margins - i accept the margins"; "Cost over target - i accept all the cost variations and overruns". FlatTrike knuckle forks turned to trail (35 mm trail); PotPress finer mesh, small-hole plates, top beam and crank bracket covers, ISO 13857 desk check now met on paper. Registers, requirements, drawings, pictures, renders and PDFs upd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
